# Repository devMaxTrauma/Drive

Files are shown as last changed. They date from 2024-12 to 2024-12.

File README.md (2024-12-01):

[//]: # (this description is temp for MDP announcement)

# **BL™ v1**

> **Blind Lumos**
>
> devMaxTrauma. Inc.™ presents **BL™ v1**

## 목차

> 1. [소개](#소개)
> 2. [대상 및 목적](#대상-및-목적)
> 3. [오픈소스](#오픈소스)
> 4. [기능](#기능)
> 5. [개발 과정](#개발-과정)
> 6. [알려진 문제](#알려진-문제)
> 7. [개발자들](#개발자들)

## 제품 소개

BL™ v1은 devMaxTrauma Inc.에서 개발한 혁신적인 시각 보조 기기로, 주로 시각장애인들을 위한 고급 기술을 탑재하고 있습니다. 이 제품은 OpenCV와 TensorFlow를 활용한 이미지 인식 기능과
FindMy 기능 등 다양한 편의 기능을 제공합니다.

BL™ v1의 소프트웨어는 오픈소스로 제공되며, 누구나 이를 참고하거나 수정할 수 있지만, 다음과 같은 조건이 적용됩니다:

> # BL™ v1 소프트웨어 사용 조건
>
> ---
>
> ## A. 출처 표기
> BL™ v1 소프트웨어를 사용할 때는 **반드시 devMaxTrauma Inc.와 BL™ v1의 출처를 명시**해야 합니다.  
> 출처가 명시되지 않을 경우, 해당 소프트웨어 사용 권한이 **즉시 상실**되며, 소프트웨어의 **소유권이나 지적 재산권을 주장할 수 없습니다**.
>
> ---
>
> ## B. 비상업적 및 윤리적 사용
> BL™ v1 소프트웨어는 **비상업적 목적**으로만 사용 가능하며, **비윤리적 사용**을 엄격히 금지합니다.  
> 상업적 목적으로 사용하려면 devMaxTrauma Inc.의 **사전 서면 승인**이 필요합니다.
>
> ---
>
> ## C. 수정 및 파생 소프트웨어
> BL™ v1 소프트웨어를 수정하거나 이를 기반으로 개발된 소프트웨어는 **본 라이선스 조건**을 그대로 따라야 하며,  
> devMaxTrauma Inc.는 해당 수정 소프트웨어에 대한 **소유권 및 라이선스 권한**을 보유합니다.
>
> ---
>
> ## D. 보증 및 책임
> BL™ v1 소프트웨어는 **"있는 그대로" 제공**되며, devMaxTrauma Inc.는 사용 중 발생하는 **어떠한 손해나 문제에 대해서도 책임을 지지 않습니다**.  
> 소프트웨어 사용으로 인해 발생하는 법적 분쟁, 손실, 또는 기타 불이익은 **사용자의 책임**입니다.
>
> ---
>
> ## E. 동의
> BL™ v1 소프트웨어를 다운로드, 설치 또는 사용할 경우, 위의 모든 조건에 **자동으로 동의**한 것으로 간주됩니다.
>
> ---

## 대상 및 목적

- 사람들은 보통 시각장애인이라 하면 전맹일 것이라 생각하지만, 실제로는 **전체 시각장애인 중 약 12%만이 전맹**이고, 나머지 88%는 색약이 있거나 시력이 떨어지는
  사람들입니다. [출처](http://www.kbufac.or.kr/Board/News/Detail?ContentSeq=2908&Page=19)
- **BL™은 전맹이 아닌 시각장애인들을 주 대상으로** 하며, 시각장애인의 불확실한 시각정보를 보완해주기 위해 제작한 작품입니다.
- 취약계층의 경제적 부담을 최대한 줄이며 보급률을 올리고자 제품 가격을 낮게 책정하여 설계했습니다. 대략 판매시 250,000 KRW 정도로 판매되길 희망합니다.

## 오픈소스

> ### EULA:
>
> BL™ v1을 개발하는 데 사용된 각종 소프트웨어 코드들은 모두 **오픈소스**로 제작되었습니다.  
> 이를 통해 누구나 이 프로젝트를 참고하거나 코드를 자유롭게 수정 및 재배포할 수 있습니다.  
> 다만, 이 프로젝트를 사용하는 모든 사용자는 다음 조건을 준수해야 합니다:
>
> ---
>
> 1. **출처 표기**
>> * 이 프로젝트를 참고하거나 수정된 코드를 배포할 때는 반드시 **devMaxTrauma Inc. 및 BL™ v1의 출처**를 명시해야 합니다.
>> * 출처를 명시하지 않을 경우, 귀하의 소프트웨어 사용 권한은 **즉시 상실**되며, devMaxTrauma Inc.가 귀하의 코드에 대한
>> * **소유권 및 라이선스 권한**을 행사할 수 있습니다.
>
> 2. **비도덕적 및 악용 금지**
>> * 이 프로젝트는 **비도덕적 목적**이나 **악의적인 의도**로 사용하는 것을 엄격히 금지합니다.
>> * 예를 들어, 불법적인 활동, 차별, 폭력 조장 등에 사용되는 경우 devMaxTrauma Inc.는 해당 사용자에 대해
>> * 법적 조치를 취할 권리를 보유합니다.
>
> 3. **수정 및 재배포**
>> * BL™ v1 기반으로 수정된 소프트웨어는 **동일한 라이선스 조건**을 따라야 합니다.
>> * 수정 및 재배포된 소프트웨어 또한 반드시 devMaxTrauma Inc.의 출처를 명시해야 하며,
>> * 이와 관련된 소유권은 devMaxTrauma Inc.에 귀속됩니다.
>
> ---
>
> ### 동의:
>
> 이 프로젝트를 다운로드, 수정, 재배포하거나 참여하는 행위만으로도 위의 모든 조건에 **자동으로 동의**한 것으로 간주됩니다.  
> devMaxTrauma Inc.는 본 프로젝트와 관련된 모든 지적 재산권과 법적 권리를 보유합니다.

### 작업결과들

- [S:IDE™](https://github.com/ellystargram/SIDE) - 자체개발 Code Editor, Kotlin 기반
- [rOS™](https://github.com/ellystargram/rOS) - Raspberry Pi 에서 돌아가는 텐서플로우 운영 체제
- [SLD™](https://github.com/devMaxTrauma/SLD) - FindMy기능을 활용할 수 있게 해주는 Android용 앱
- [devMaxTrauma. Inc.™](https://github.com/devMaxTrauma/Drive) - devMaxTrauma. Inc.의 모든 프로젝트 결과물

## 기능

> BL™ v1은 시각장애인의 시각정보를 보완해주는 제품입니다.

- BL™ v1은 라즈베리파이와 텐서플로우를 이용하여 사물을 인식하고, OpenCV를 이용하여 사물을 강조하여 표시합니다.
- SLD와 연동되어 안드로이드 기기에서 FindMy 기능을 사용할 수 있습니다.
- 탭틱엔진을 이용하여 햅틱 피드백을 얻을 수 있습니다.
- AR 기기답게 FPS 증진에 초점을 맞추어 최적화되었습니다. OpenCV Thread 와 Tensorflow Thread 를 병렬로 돌리며, 이를 통해 빠른 인식을 제공합니다.
- 물체와 사용자간의 거리를 측정하여 사용자에게 알려줍니다.

## 개발 과정

BL™ v1 (https://youtu.be/08gYM3Qs6oE)

### 설계 단계때 Inventor 상에 설계된 모델

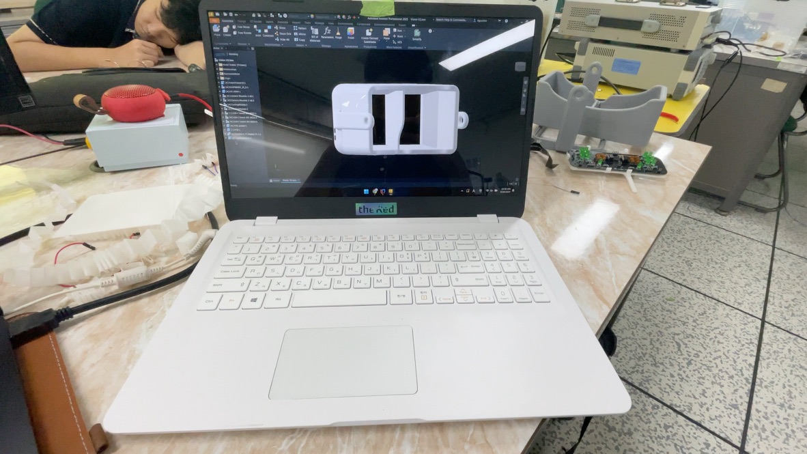
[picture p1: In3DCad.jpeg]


### 착용샷

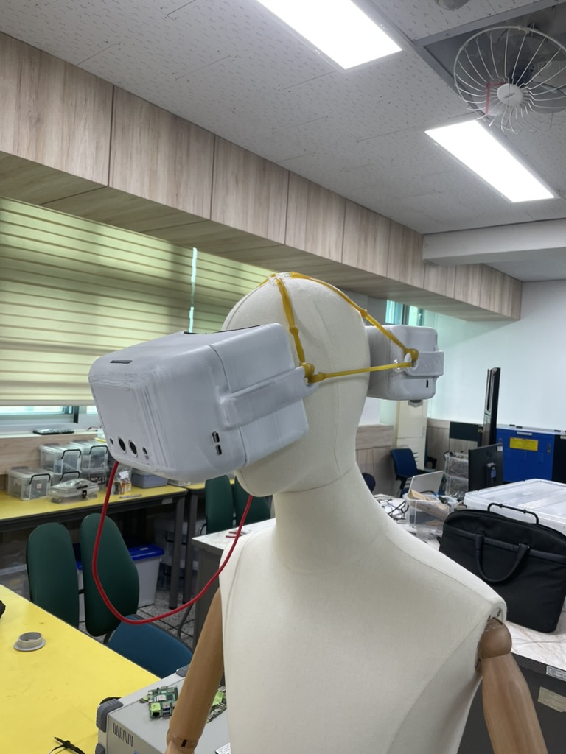
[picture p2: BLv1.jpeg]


### PCB

pcb picture

## 알려진 문제

- BL™ v1은 보기와 다르게 무거울 수 있습니다. 이는 MVP제품 특성상 발생하는 문제로, 이후 출시될 제품에서 개선될 예정입니다.
- BL™ v1은 시각장애인의 시각정보를 보완해주는 제품이지만, 시각장애인의 시각정보를 완벽하게 보완해주지는 못합니다. 이 점을 감안하여 사용해주시기 바랍니다.
- BL™ v1의 현재 디스플레이는 라즈베리파이 7인치 디스플레이로, 해상도가 낮고 명암비가 충분하지 않을 수 있습니다. 이는 다음 세대 제품에서 OLED 디스플레이를 탑제하면서 해결될 문제입니다.
- Light Seal™ 은 사람 체형에 맞춰서 커스텀으로 제작됩니다. 현제 착용하신 Light Seal 은 조원들중 한명의 얼굴을 본따 만들었기에 불편할 수 있습니다.
- Tensorflow Lite 모델이 부정확한 결과를 가져올 수 있습니다. 이는 AR 제품 특성상 FPS를 높이기 위해 모델을 최적화하다 보니 발생하는 문제입니다. 이는 다음 세대 제품에서 개선되길 희망합니다.

## 개발자들

### 최지오

> Role: Techno_King && Software Integrating Maestro

- <a href="https://discordapp.com/users/479559804021506049">
  Discord logo
  </a>
- <a href="https:/x.com/techno_sexking"> 
  X logo
  </a>
- <a href="https://github.com/ellystargram">
  Github logo
  </a>

### 송다연

> Role: Circuit Master

- <a href="https://instagram.com/day2onll"> 
    Instagram logo

</a>

### 최지훈

> Role: QC Master && Android Platform Sailor

- <a href="https://instagram.com/ji_h_6"> 
    Instagram logo

</a>

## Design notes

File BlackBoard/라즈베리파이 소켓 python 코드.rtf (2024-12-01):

import serial
import RPi.GPIO as GPIO
import socket
import threading

GPIO.setmode(GPIO.BCM)
GPIO.setup(17, GPIO.IN) # 입력 설정

HOST = "192.168.0.6"
PORT = 9021

# UART 포트 초기화

uart = serial.Serial("/dev/ttyS0", baudrate=115200, timeout=1)

# Socket 생성

s = socket.socket(socket.AF_INET, socket.SOCK_STREAM)
print('Socket created')
s.bind((HOST, PORT))
print('Socket bind complete')
s.listen(1)
print('Socket now listening')

u_data = ''
flag = 0

# 파이 컨트롤 함수

def do_some_stuffs_with_input(input_string):
if input_string == "send": # 휴대폰에서 send 라는 값이 올 경우 ...라는 값을 돌려준다.
input_string = "..."
else:
input_string = input_string + " 없는 명령어 입니다."
return input_string

# Socket 데이터 송수신을 위한 쓰레드

def socket_func(conn):
while True:
# 데이터 수신

data = conn.recv(1024)
data = data.decode("utf8").strip()
if not data:
break
print("Socket 수신된 데이터:", data)

u_data = data

# 수신한 데이터로 파이를 컨트롤

if data == 'close':
break
res = do_some_stuffs_with_input(data)

if data == "close":
flag = 1;

if GPIO.input(17) == 1: # 16번 GPIO에 입력값이 들어올 경우 ...이라는 값 대신에 push값전달
print("in")
command = "push"
conn.sendall(command.encode("utf-8"))
else: # 클라이언트에게 답을 보냄
conn.sendall(res.encode("utf-8"))

print(data)

# 데이터 송신

data_to_send = data
uart.write(data_to_send.encode()) # 문자열을 바이트로 변환하여 전송

conn.close()

try:

while True:
# 접속 승인

print("Waiting for connection...")
conn, addr = s.accept()
print("Connected by", addr)

# Socket 수신 쓰레드 시작

socket_thread = threading.Thread(target=socket_func, args=(conn,))
socket_thread.start()
print(u_data)

if flag == 1:
break

except KeyboardInterrupt:
pass

finally:
# Continuing the code

# Clean up resources

uart_thread.join()
s.close()
uart.close()

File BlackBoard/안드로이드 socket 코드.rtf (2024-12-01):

package com.example.socket5;

import androidx.appcompat.app.AppCompatActivity;

import android.os.Handler;
import android.os.Bundle;
import android.util.Log;
import android.view.View;
import android.widget.Button;
import android.widget.EditText;
import android.widget.TextView;
import android.widget.Toast;

import java.io.BufferedReader;
import java.io.BufferedWriter;
import java.io.IOException;
import java.io.InputStreamReader;
import java.io.OutputStreamWriter;
import java.io.PrintWriter;
import java.net.InetAddress;
import java.net.Socket;

public class MainActivity extends AppCompatActivity {
private Handler mHandler;
Socket socket;
String ip = "192.168.0.6"; // 서버의 IP 주소
int port = 9021; // PORT번호를 꼭 맞추어 주어야한다.
EditText et;
TextView msgTV;

@Override
protected void onCreate(Bundle savedInstanceState) {
super.onCreate(savedInstanceState);
setContentView(R.layout.activity_main);

mHandler = new Handler();


et = (EditText) findViewById(R.id.EditText01);
Button btn = (Button) findViewById(R.id.Button01);
msgTV = (TextView) findViewById(R.id.chatTV);

msgTV.setText("123");

btn.setOnClickListener(new View.OnClickListener() {
public void onClick(View v) {
if (et.getText().toString() != null || !et.getText().toString().equals("")) {
ConnectThread th = new ConnectThread();
Toast.makeText(MainActivity.this, "연결중", Toast.LENGTH_SHORT).show();
th.start();
}
}
});
}

@Override
protected void onStop() {
super.onStop();
try {
socket.close();//종료시 소켓도 닫아주어야한다.
} catch (IOException e) {
e.printStackTrace();
}
}

class ConnectThread extends Thread {//소켓통신을 위한 스레드

public void run() {
try {
// Toast.makeText(MainActivity.this, "linking", Toast.LENGTH_SHORT).show();
//소켓 생성
InetAddress serverAddr = InetAddress.getByName(ip);
socket = new Socket(serverAddr, port);
msgTV.setText("connected");
Toast.makeText(MainActivity.this, "linked", Toast.LENGTH_SHORT).show();
//입력 메시지
String sndMsg = et.getText().toString();
Log.d("=============", sndMsg);
//데이터 전송
PrintWriter out = new PrintWriter(new BufferedWriter(new OutputStreamWriter(socket.getOutputStream())), true);
out.println(sndMsg);
//데이터 수신
BufferedReader input = new BufferedReader(new InputStreamReader(socket.getInputStream()));
String read = input.readLine();
//화면 출력
mHandler.post(new msgUpdate(read));
Log.d("=============", read);
socket.close();//사용이 끝난뒤 꼭 닫아주어야한다.

if(et.getText().toString().equals("shut")) {
Toast.makeText(MainActivity.this, "closed", Toast.LENGTH_SHORT).show();
onStop();
}
} catch (Exception e) {
e.printStackTrace();
}
}


}

// 받은 메시지 출력
class msgUpdate implements Runnable {
private String msg;

public msgUpdate(String str) {
this.msg = str;
}

public void run() {
msgTV.setText(msgTV.getText().toString() + msg + "\n");
}
}
}

<?xml version="1.0" encoding="utf-8"?>
<LinearLayout xmlns:android="http://schemas.android.com/apk/res/android"
xmlns:app="http://schemas.android.com/apk/res-auto"
xmlns:tools="http://schemas.android.com/tools"
android:layout_width="match_parent"
android:layout_height="match_parent"
android:orientation="vertical"
tools:context=".MainActivity">

<LinearLayout
android:layout_width="match_parent"
android:layout_height="wrap_content"
android:layout_gravity="center"
android:orientation="horizontal"
android:weightSum="5">

<EditText
android:id="@+id/EditText01"
android:layout_width="0dp"
android:layout_height="match_parent"
android:layout_weight="4"
app:layout_constraintEnd_toEndOf="parent"
app:layout_constraintHorizontal_bias="0.874"
app:layout_constraintStart_toStartOf="@+id/Button01"
tools:layout_editor_absoluteY="608dp" />

<Button
android:id="@+id/Button01"
android:layout_width="0dp"
android:layout_height="match_parent"
android:layout_weight="1"
android:text="Send"
app:layout_constraintBottom_toBottomOf="parent"
tools:layout_editor_absoluteX="317dp" />

</LinearLayout>

<TextView
android:id="@+id/chatTV"
android:layout_width="match_parent"
android:layout_height="wrap_content"
app:layout_constraintBottom_toBottomOf="parent"
app:layout_constraintEnd_toEndOf="parent"
app:layout_constraintHorizontal_bias="0.0"
app:layout_constraintStart_toStartOf="parent" />

</LinearLayout>

<uses-permission android:name="android.permission.INTERNET" />

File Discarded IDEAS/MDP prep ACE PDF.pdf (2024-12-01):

## 작품 제안서

학과: 전자제어과 2학년 2반 12번 이름: 최지오

작품명 | ACE® (Autonomous Cooking Environment)
제안 이유 | 파스타를 만들다 보면 거의 레시피가 비슷한데, 손이 많이가는 경험을 할 수 있다. 또한 식당(* 돈까스 클럽, 홍익 돈까스 등)을 가보면 인건비로 인하여 파 스타 가격이 많이 비싸단것도 몸소 채감할 수 있다. 인건비를 해소하고 더 빠 르고 안전하게 파스타를 만들 수 있도록 이 장치를 개발시작하게 되었다.

블록 다이어그램

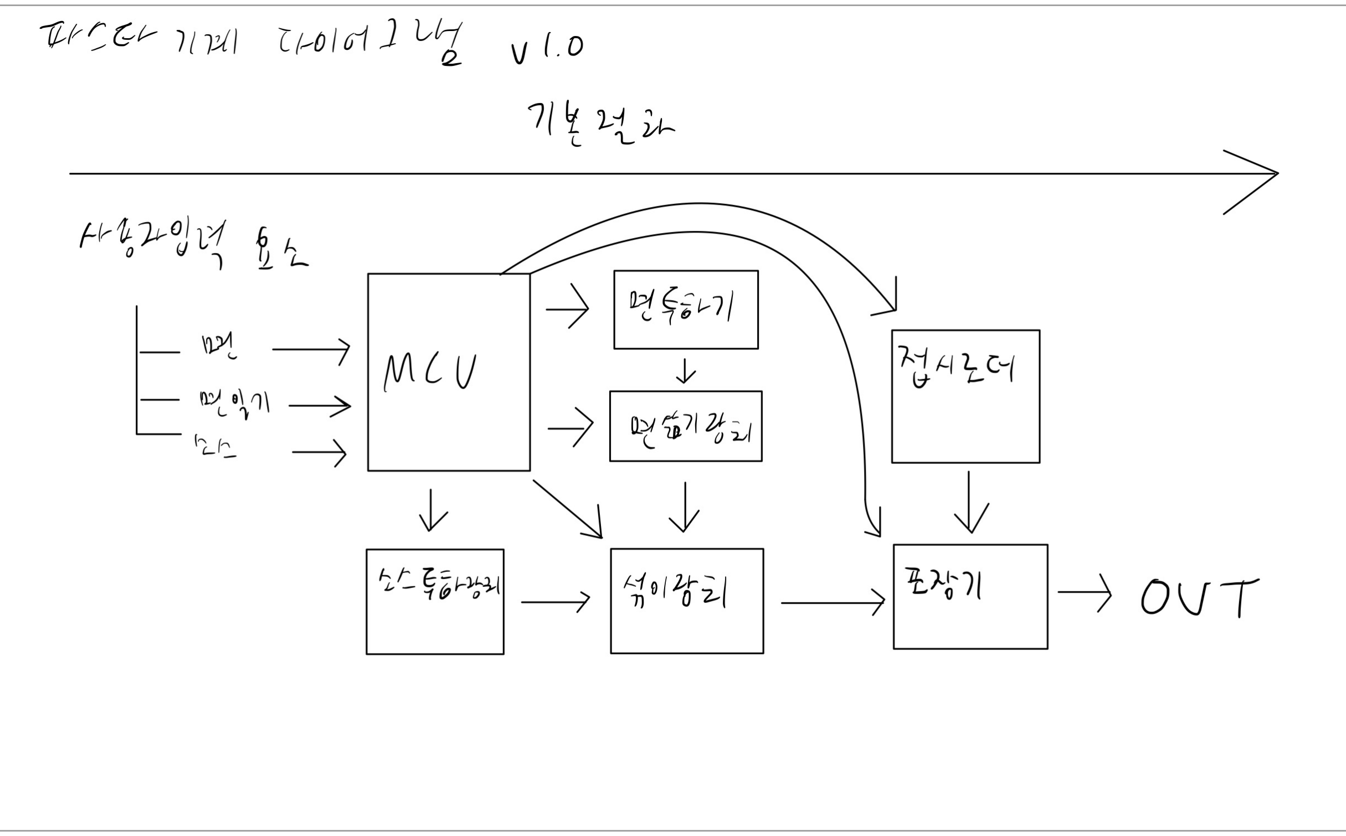
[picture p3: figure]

주요 구현 동작 | 1) 재료를 미리 다 넣어둔다. 2) 터치스크린을 통해 원하는 파스타면을 선택할 수 있다. 3) 터치스크린을 통해 원하는 소스를 선택할 수 있다. 4) 터치스크린을 통해 원하는 면 익힘 정도를 선택할 수 있다. 5) 선택된것(2,3,4)에 따라 조리를 한다음에 접시에 담아 제공한다.
필요 소모품 목록 | 입력부 | 터치스크린, 안전상의 이유로 존재하는 긴급 중지 버튼
| 제어부 | STM32(여러가지 모터 구동)
| 출력부 | 표시장치(진행상황 표시), 모터들, 발열체(가열), 펌프(급수)
참고자료 및 필요 배경 지식 | STM32 작동하기 c로 작동함 * c언어 배우기(Github, chatGPT, copilot) * c언어 분석(2학년때 만든 MDP 코드, sOS™ 분석) 여러가지 기계적 특성 및 설계 방법 * 유튜브에 Inventor 강의 많음 * 기계과 나온 우리형한테 자문 구함

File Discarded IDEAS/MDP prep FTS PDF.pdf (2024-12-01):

## 작품 제안서

학과: 전자제어과 2학년 2반 12번 이름: 최지오

작품명 | FTS (Fire Terminating System)
제안 이유 | 캠핑을 할때, 불타는 장작속으로 뛰어들어가는 나방을 본적이 있을것이다. 나 는 여기서 영감을 받아서 알아서 온도가 가장 높은곳(불 또는 발화원)으로 달 려가서 소화가스를 분사하는 시스템을 만들고 싶어졌다. 이는 화재 진압 과정 에서 인적 손실을 줄일 수 있고 배치 시간을 줄이는데 도움을 줄 수 있다.

블록 다이어그램

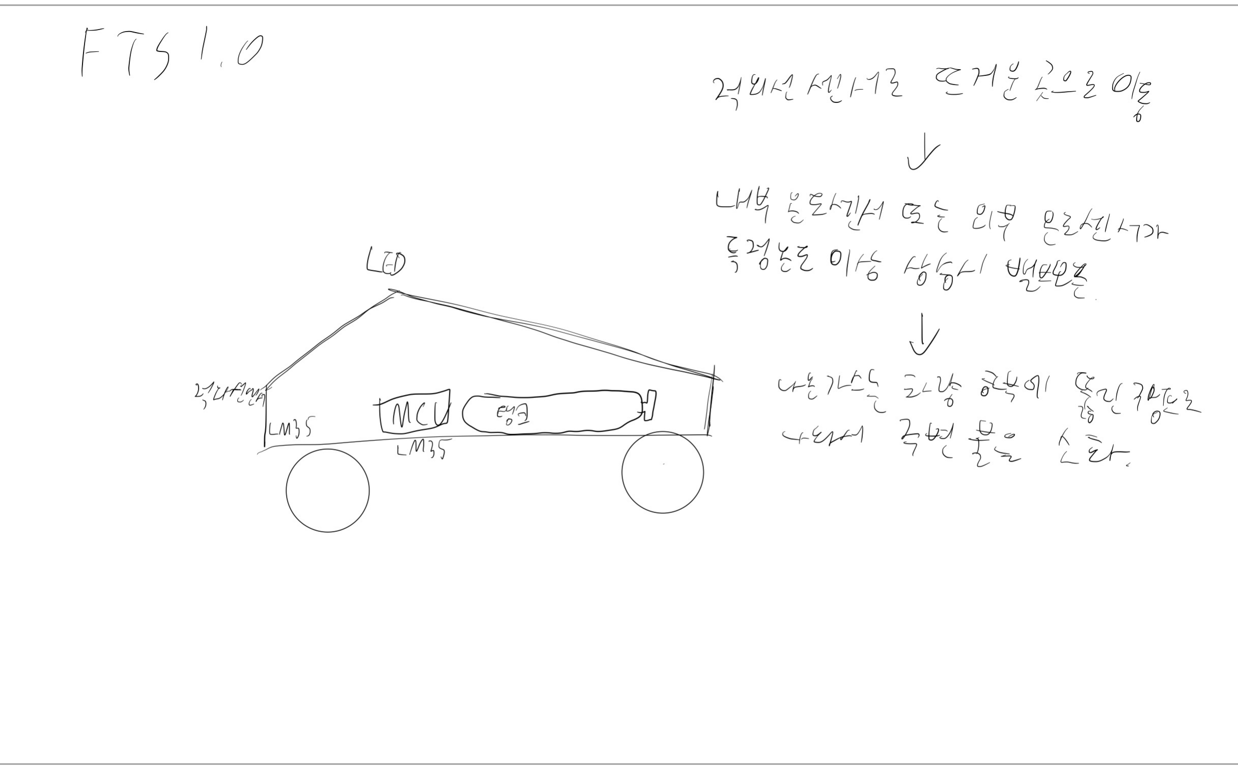
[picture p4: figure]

주요 구현 동작 | 1) 소화가스가 충전된 상태로 준비상태에 있다. 2) 출동 명령이 들어온다 3) 자체적으로 달려있는 적외선 감지기를 통해 가장 뜨거운 곳으로 주행을 시작한다 4) 주변 온도가 일정 온도 이상으로 올라가면(불난곳으로 들어가면) 소화가스방출을 시작한다.(이는 주변 소화 기능도 있지만, 소화가스방출중 발생하는 단열팽창을 통해 기계 자체를 냉각한다.) 5) 소화가스를 다 소모시 불 밖으로 도망나온다. 6) 소화가스를 다시 충전하면 다시 출동 준비가 완료된다.
필요 소모품 목록 | 입력부 | 적외선 센서, 주변온도 센서, 원격 제어를 위한 무선송수신부
| 제어부 | STM32(여러가지 모터 구동)
| 출력부 | 서보모터(소화가스 밸브작동), 모터(주행), 스피커(사이렌), LED, 가스탱크, 소화가스(CO2)
참고자료 및 필요 배경 지식 | STM32 작동하기 c로 작동함 * c언어 배우기(Github, chatGPT, copilot) * c언어 분석(2학년때 만든 MDP 코드, sOS™ 분석) 여러가지 기계적 특성 및 설계 방법 * 유튜브에 Inventor 강의 많음 * 기계과 나온 우리형한테 자문 구함 뜨거운 곳에서 작동해야 하기에 스테인리스 스틸로 외관을 제작해야함

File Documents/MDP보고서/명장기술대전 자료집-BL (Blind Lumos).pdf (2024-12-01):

# BL (Blind Lumos)

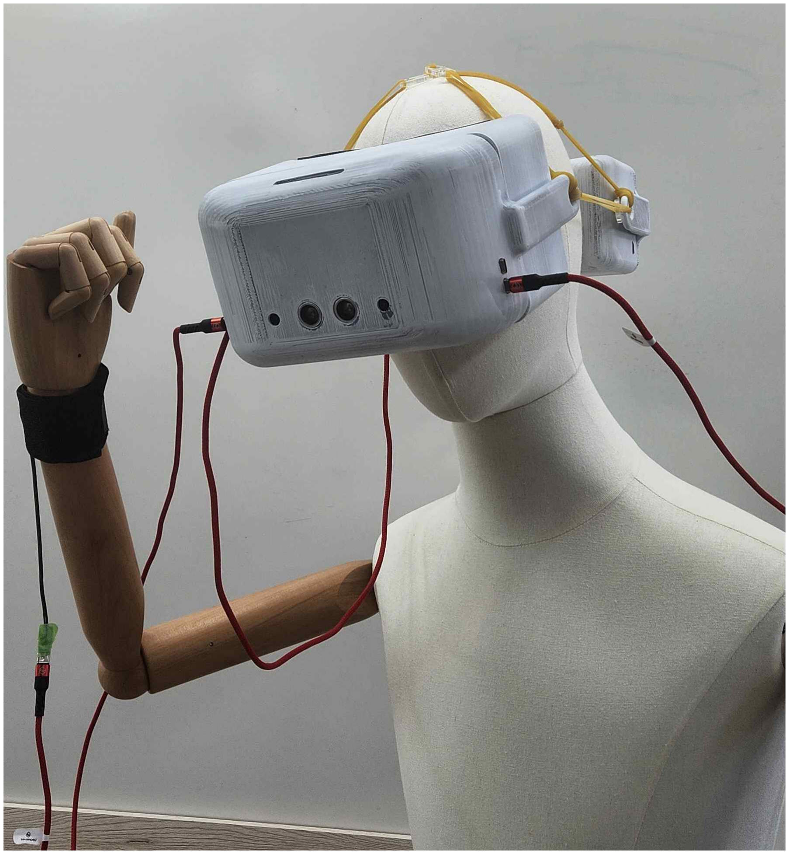
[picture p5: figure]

# 인천전자마이스터고등학교

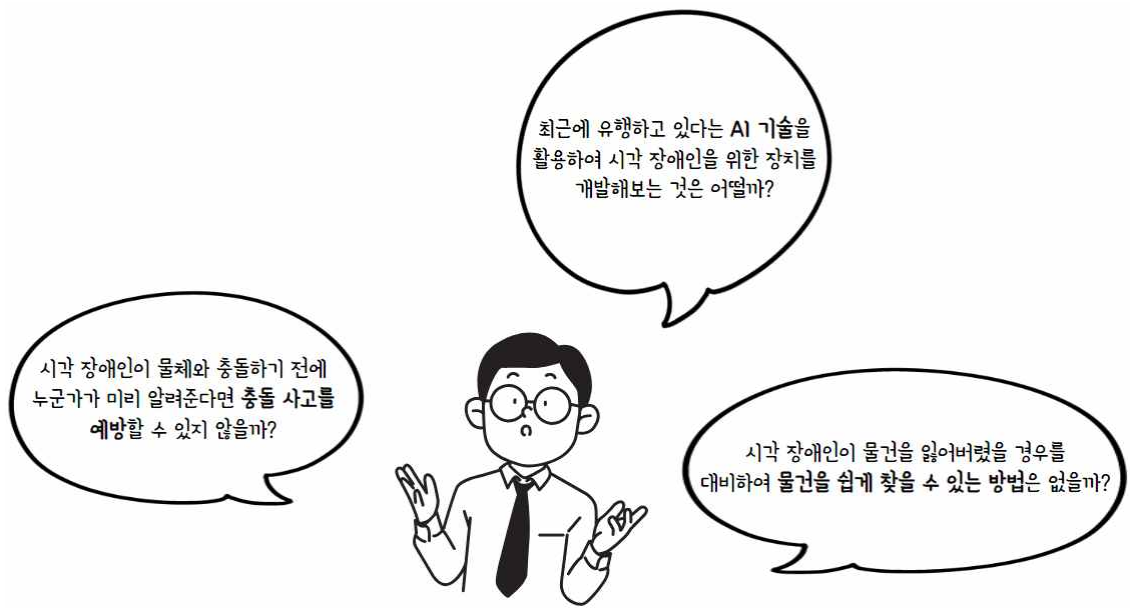
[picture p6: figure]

2 | 인천전자마이스터고등학교 IM 명장기술대전

사람들은 대부분 시각 장애라 하면, 빛을 완전히 인지하지 못하는 전맹을 생각하곤 한다. 하 지만 실제로는 저시력이나 단안 실명, 시야각 결손도 시각 장애에 포함이 된다. 따라서, 시각 장애인의 대부분은 전맹이 아니라 빛을 인지하고, 사물의 윤곽은 알아볼 수 있는 시각 장애인 의 비중이 훨씬 높다. 하지만 이들은 정확하지 않은 시각 정보에 크게 의존하는 경우가 많기 때문에 오히려 전맹을 가진 시각 장애인보다 더욱 위험한 상황에 처할 수 있다. 우리들은 이러 한 문제점을 파악한 후, 시각 장애인들의 안전을 위한 장치(BL)를 고안해보게 되었다. 장치의 기본적인 기능으로는 내부의 각종 모듈을 통해 디스플레이로 사물의 정보를 송출할 수 있도록 하는 것이다. 그리고 사물을 사람의 눈에 잘 띄는 색상(예: 고대비)을 가진 네모 영역으로 이미 지를 대체하여 사용자가 세상과 안전하게 상호작용 할 수 있도록 도움을 주게 한다. 또한, 정 면에 존재하는 사물이 사용자와 얼마나 가까이 있는지를 알리기 위해 손목 밴드의 진동 모듈 을 통하여 사용자에게 직접적으로 거리에 대한 정보를 제공한다. 만약, 사용자가 장치를 잃어 버렸을 경우에 대비하여 전용 APP(SLD)과 장치를 블루투스를 통해 서로 연동함으로써 사용자 가 장치와 멀리 떨어져 있어도 쉽게 장치를 찾을 수 있도록 하는 기능이 존재한다.

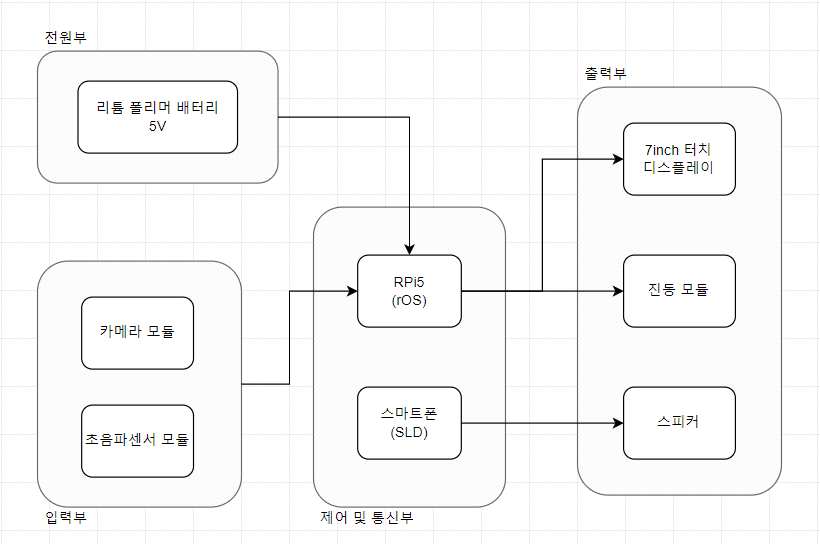
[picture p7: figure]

전자제어과 | 3

### 1. 동작 설명

가. 전원이 공급되고 있는 장치를 착용하여 장치의 동작을 확인한다.
나. 사용자의 주위에 위험한 사물이 있거나, 사물이 가까이 있는지 살펴본다.
다. 사용자의 주위에 위험한 사물이 있을 경우, 빨간색으로 강조된 네모 영역 이미지가 사물을 표시하여 보여준다.
라. 사용자의 주위에 사물이 가까이 있을 경우, 손목 밴드에 탑재되어 있는 진동 모듈이 거리에 따라 진동의 세기가 다르게 동작하여 사용자에게 위험 수준을 알린다. 2. 부가 요소

가. 장치 내부의 디스플레이를 통해 사물의 네모 영역 이미지를 보고 세상과 상호작용 할 수 있다,
나. 위험한 상황에 노출되지 않도록 정면에 있는 사물이 사용자와 얼마나 가까이 있는지를 진동 모듈을 통해 알 수 있다.
다. 장치의 디스플레이에 블루라이트 차단 필터 효과를 적용할 수 있다.
라. 전용 App과 장치를 연동할 경우에 장치가 사용자와 떨어져 있어도 어디에 있는지 전용 App을 통해 알 수 있다.
마. 전용 App의 화면을 슬라이딩하여 손쉽게 장치의 색약 보정을 할 수 있다.

4 | 인천전자마이스터고등학교 IM 명장기술대전

### 3. 전원부

가. 리튬 폴리머 배터리 5V
: 장치 내부의 Raspberry pi 5에 5V의 전원을 공급한다. 4. 프로세서 제어부

가. Raspberry pi 5 (8GB)
: 안드로이드 앱과 블루투스 통신을 하고, Raspberry pi 5와 연결된 카메라 모듈 및 초음파센서로부터 받아온 정보를 7inch 다스플레이에 실시간 송출한다. 또한, 사물을 인식하여 그에 맞는 네모 영역 이미지를 생성해 보여준다.
나. Android 및 iOS 어플리케이션 (SLD)
: 어플리케이션의 화면 속 버튼을 눌렀을 때, Raspberry pi 5와 연결된 스피커를 통해서 소리를 출력한다. 5. 입력부

가. 카메라 모듈
: Raspberry pi 5와 연결하여 사용자가 바라보는 시야 정보를 카메라 센서를 통해 디지털신호로 반환한다.
나. 초음파센서
: Raspberry pi 5와 연결하여 정면에 존재하는 사물과의 거리를 측정한다. 6. 출력부

가. 7inch 터치 디스플레이
: Raspberry pi 5와 연결된 카메라가 받아온 디지털신호와 사물의 네모 영역 이미지를 출력하여 보여준다.
나. 진동 모듈 (Taptic Engine)
: Raspberry pi 5와 연결된 초음파센서에서 받아온 데이터 값이 일정한 수치에 가까워지게 되면 진동 모듈에서 진동이 시작된다, 사물과의 거리가 가까울수록 진동 모듈이 크게 진동하고, 사물과의 거리가 멀수록 진동 모듈이 작게 진동한다. 다. 스피커
: Android 및 iOS 어플리케이션(SLD)을 통해 신호를 받으면 스피커에 소리를 재생시킨다.

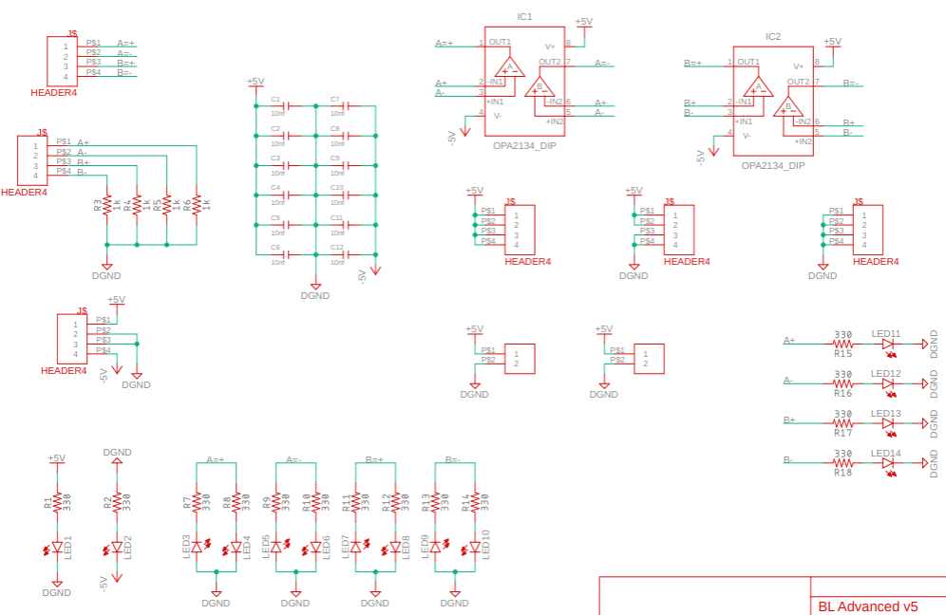
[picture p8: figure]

전자제어과 | 5

리튬 폴리머 배터리 5V로부터 전원을 공급받는 전원부이다. 이를 통해 각종 프로세서에 필요한 전원을 공급하여 프로세서를 동작시킬 수 있다.

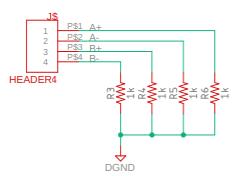
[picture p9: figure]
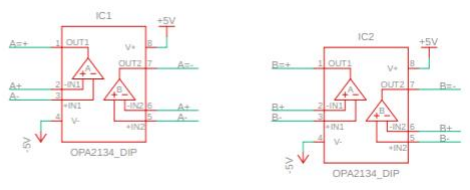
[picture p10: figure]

6 | 인천전자마이스터고등학교 IM 명장기술대전

입력을 받는 입력부이다. 진동 모듈이 동작하기 위해 Raspberry pi 5의 PWM 값을 입력받아 OP-Amp로 양과 음의 파형을 동작시키기 위한 회로이다.

출력이 되는 출력부이다. OP-Amp로 Raspberry pi 5의 PWM 파형이 입력되면 듀티비에 따라 진동 모듈의 진동 모터 속도가 변화하여 진동의 세기를 조절한다.

Raspberry pi 5로부터 입력을 받아 진동 모듈의 출력을 제어하는 OP-Amp 회로이다.

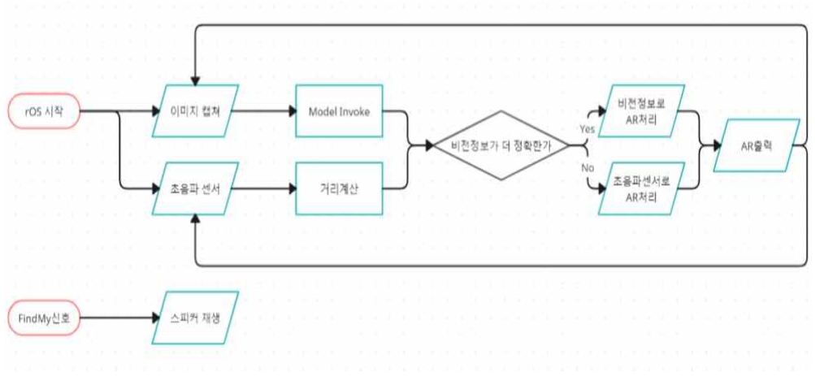
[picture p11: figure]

전자제어과 | 7

장치에는 Raspberry pi 5가 내장되어 있으며, 카메라 모듈과 초음파센서로부터 데이터를 받 아 프로그램의 동작을 수행한다. 또한, 받아온 데이터를 바탕으로 진동 모듈의 동작을 수행한 다. Raspberry pi 5로 실행되는 프로그램은 카메라 모듈로 입력받은 데이터를 통해 사물과 사 용자 간의 거리를 디스플레이에 표시하고, AI를 이용해 사물을 인식하여 네모 영역의 이미지를 디스플레이에 표시한다. 스마트폰의 장치 전용 App에서는 Raspberry pi 5와 블루투스 연동이 되어있을 때, 화면의 버튼을 누르면 장치 내부의 스피커에서 소리가 재생된다.

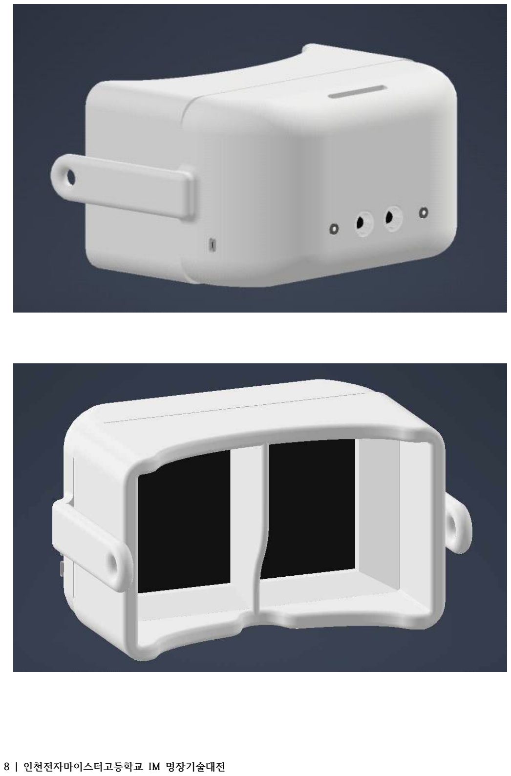
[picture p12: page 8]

8 | 인천전자마이스터고등학교 IM 명장기술대전

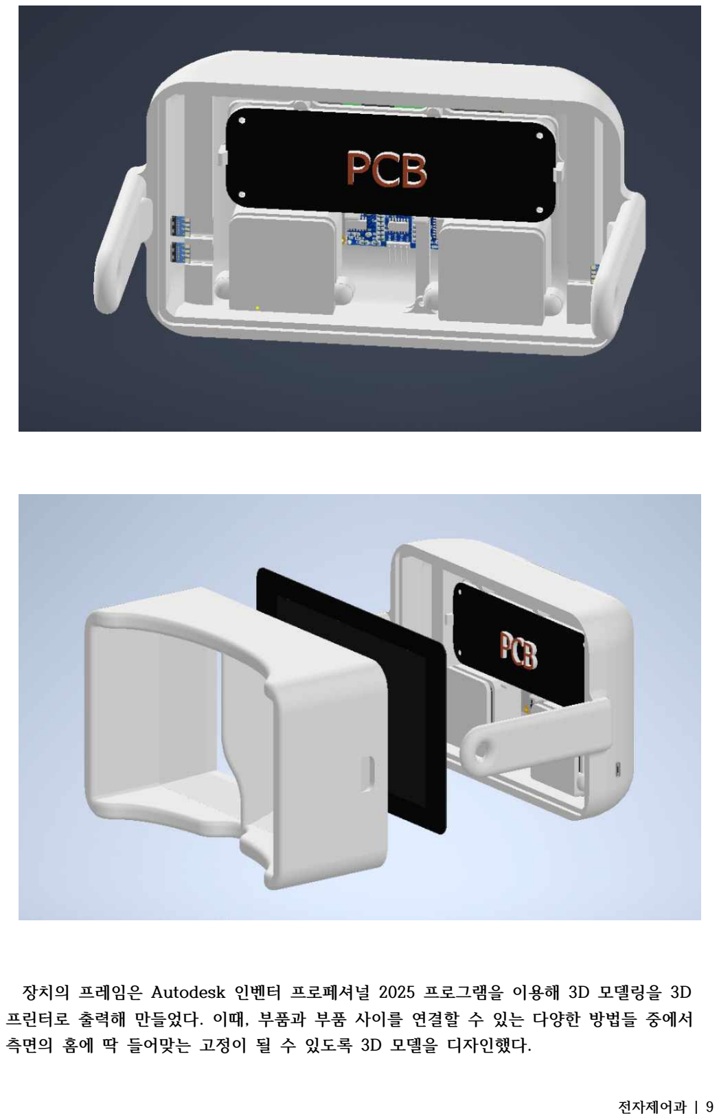
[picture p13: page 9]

전자제어과 | 9

장치의 프레임은 Autodesk 인벤터 프로페셔널 2025 프로그램을 이용해 3D 모델링을 3D 프린터로 출력해 만들었다. 이때, 부품과 부품 사이를 연결할 수 있는 다양한 방법들 중에서 측면의 홈에 딱 들어맞는 고정이 될 수 있도록 3D 모델을 디자인했다.

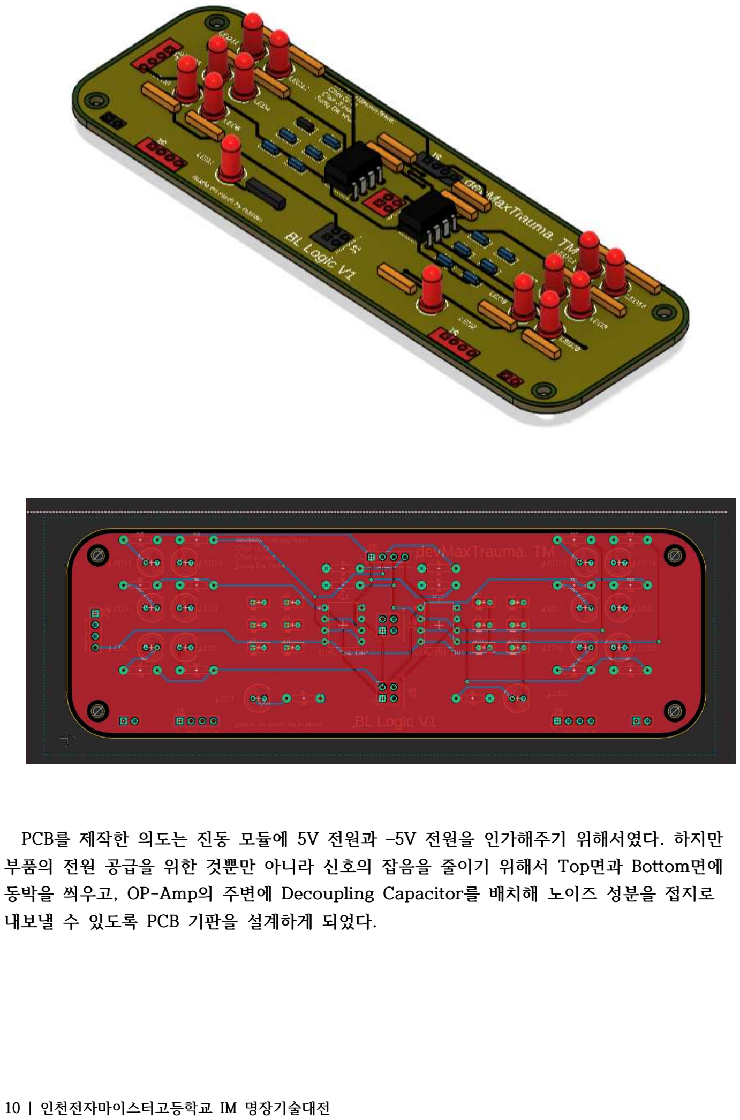
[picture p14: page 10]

10 | 인천전자마이스터고등학교 IM 명장기술대전

PCB를 제작한 의도는 진동 모듈에 5V 전원과 –5V 전원을 인가해주기 위해서였다. 하지만 부품의 전원 공급을 위한 것뿐만 아니라 신호의 잡음을 줄이기 위해서 Top면과 Bottom면에 동박을 씌우고, OP-Amp의 주변에 Decoupling Capacitor를 배치해 노이즈 성분을 접지로 내보낼 수 있도록 PCB 기판을 설계하게 되었다.

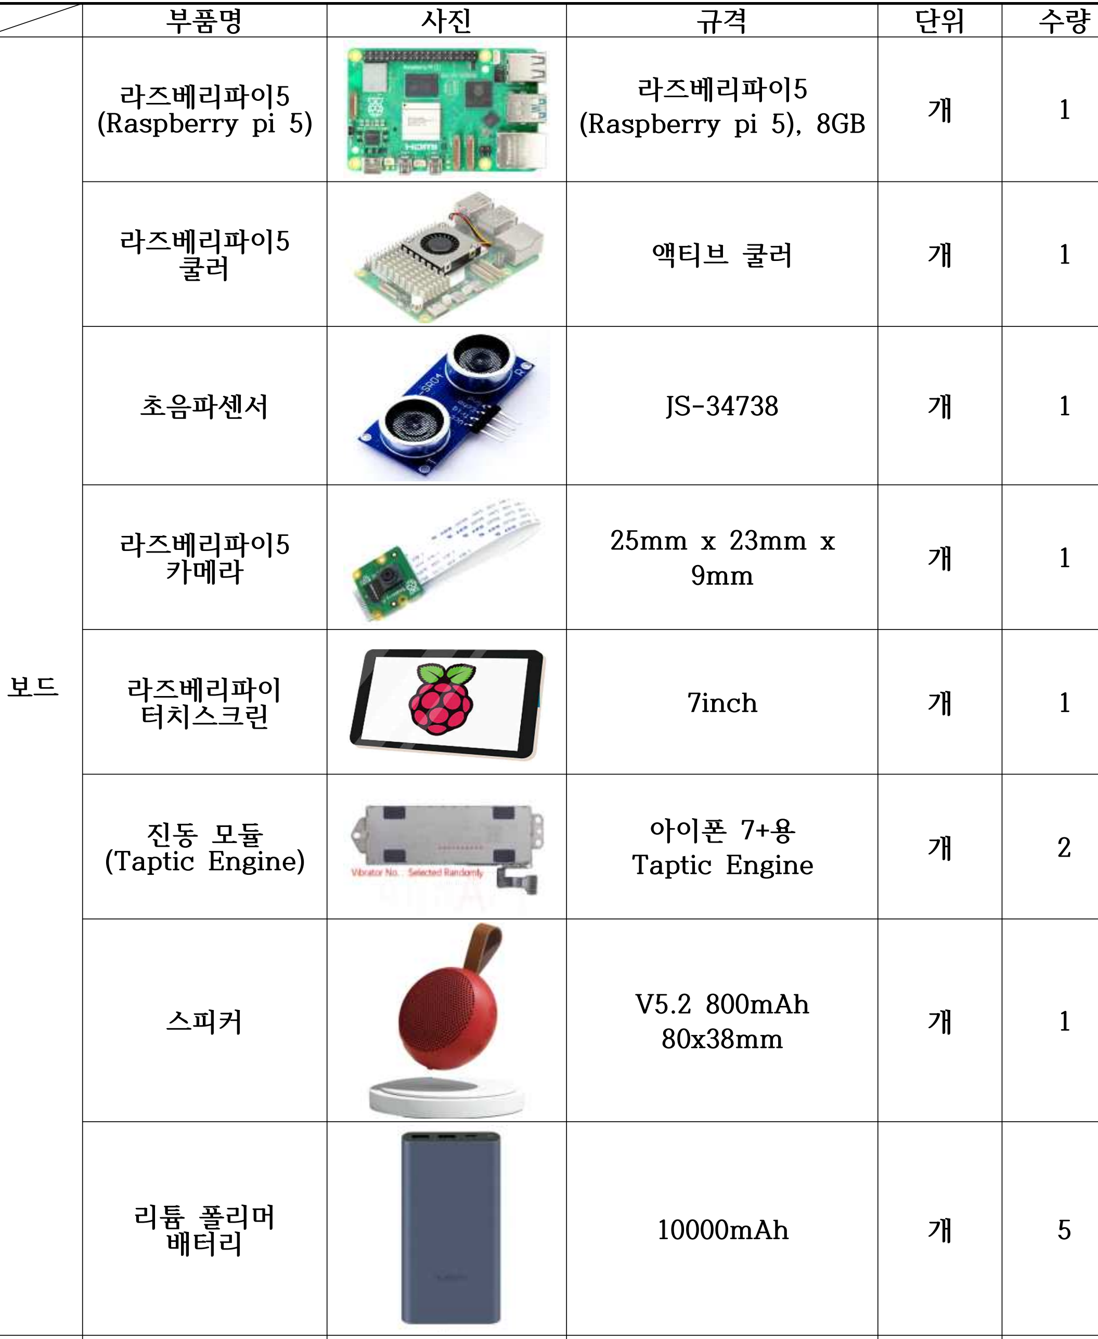
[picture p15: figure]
부품명; 라즈베리파이5 (Raspberry pi 5); 라즈베리파이5 (Raspberry pi 5), 8GB; 라즈베리파이5 쿨러; 액티브 쿨러; 초음파센서; 라즈베리파이5 카메라; 라즈베리파이 터치스크린; 7inch; 진동 모듈 (Taptic Engine); 아이폰 7+용 Taptic Engine; 스피커; V5.2 800mAh 80x38mm; 리튬 폴리머 배터리; 10000mAh

전자제어과 | 11
기구물 | 장치 프레임 | | 필라멘트, 16.3cm x 23.5cm x 11.9cm | 개 | 1

12 | 인천전자마이스터고등학교 IM 명장기술대전

이 작품은 우리가 처음 계획했었던 사물 인식 기능과 사용자와 사물간의 거리 측정 기능, 그 리고 사용자에게 위험도를 알리는 기능을 모두 수행하는 만족스러운 결과를 만들어 냈다. 하지만, 우리는 추가적으로 개발하려고 했었던 가속도센서를 이용한 추락 인지 기능을 구현

하지 못했다. 또한, 해당 작품이 우리가 예상했었던 무게를 초과하였기 때문에 착용하는 사람 에 따라 장치가 무겁다고 느낄 수 있을 것 같다. 앞으로 우리는 지금까지 개발된 기능들을 조금 더 체계적으로 정리한 다음, 구현해내지 못했

던 추락 인지 기능을 개발하여 장치에 추가할 예정이다. 그리고 기능이 추가된 만큼 늘어난 장 치의 무게를 줄이기 위한 방법을 찾기 위해 꾸준히 장치를 시험해볼 예정이다. 우리들은 이 장치를 통해서 세상에 존재하는 많은 시각 장애인들이 안전하게 세상과 상호작

용 할 수 있었으면 한다. 참고문헌

[1] https://www.apple.com/kr/newsroom/2023/06/introducing-apple-vision-pro/
[2] https://www.meta.com/kr/quest/quest-3/
[3] http://www.kbufac.or.kr/Board/News/Detail?ContentSeq=2908&Page=19

전자제어과 | 13

### 1. 프로젝트 수업 계획서

월 | 주 | 일 | 단 원 | 주요업무 | 비 고
(작성되어야 할 내용, 제출평가) | 확인 (지도교사)
3 | 2 | 3/4 ~ 3/8 | 프로젝트 구성안 | 제품명/디자인 및 동작 계획
| 3 | 3/11 ~ 3/15 | 프로젝트 구성안 | 기능 구상 및 역할 분담
| 4 | 3/18 ~ 3/22 | 부품 발주 | 프로젝트 필요 부품 구상 및 발주 신청
| 5 | 3/25 ~ 3/29 | 소프트웨어 | 플로우차트 작성
4 | 1 | 4/1 ~ 4/5 | 소프트웨어 | 기본 소프트웨어 구현
| 2 | 4/8 ~ 4/12 | 관련 학습 | 앱 기능 구현 방법 학습
| 3 | 4/15 ~ 4/19 | 부품 발주 | 필요 부품 발주 추가 신청
| 4 | 4/22 ~ 4/26 | 소프트웨어 | 기본 소프트웨어 구현
| 5 | 4/29 ~ 4/30 | 하드웨어 | 하드웨어 3D 모델링 제작
5 | 1 | 5/1 ~ 5/3 | 소프트웨어 | 기본 소프트웨어 구현
| 2 | 5/7 ~ 5/10 | 소프트웨어 | 심화 소프트웨어 구현
| 3 | 5/13 ~ 5/17 | 소프트웨어 | 심화 소프트웨어 구현
| 4 | 5/20 ~ 5/24 | 소프트웨어 | 앱 기능 구현
| 5 | 5/27 ~ 5/31 | 소프트웨어 | 앱 기능 구현
6 | 2 | 6/3 ~ 6/7 | 부품 발주 | 필요 부품 발주 신청
| 3 | 6/10 ~ 6/14 | 하드웨어 | 하드웨어 블록도 작성
| 4 | 6/17 ~ 6/21 | 소프트웨어 | 심화 소프트웨어 구현
| 5 | 6/24 ~ 6/28 | 하드웨어 | 기본 하드웨어 구성

14 | 인천전자마이스터고등학교 IM 명장기술대전
월 | 주 | 일 | 단 원 | 주요업무 | 비 고
(작성되어야 할 내용, 제출평가) | 확인 (지도교사)
7 | 1 | 7/1 ~ 7/2 | 하드웨어 | 기본 하드웨어 구성
| 2 | 7/8 ~ 7/12 | 하드웨어 | 심화 하드웨어 구성
| 3 | 7/15 ~ 7/19 | 소프트웨어 | 심화 소프트웨어 구현
| 4 | 7/22 ~ 7/26 | 소프트웨어 | 심화 소프트웨어 구현
| 5 | 7/29 ~ 7/31 | 소프트웨어 | 심화 소프트웨어 구현
8 | 1 | 8/1 ~ 8/2 | 하드웨어 | 심화 하드웨어 구성
| 2 | 8/5 ~ 8/9 | 하드웨어 | 심화 하드웨어 구성
| 3 | 8/12 ~ 8/16 | 소프트웨어 | 소프트웨어 구동 확인 및 수정
| 4 | 8/19 ~ 8/23 | 하드웨어 | 기구물과 하드웨어 결합
| 5 | 8/26 ~ 8/30 | 하드웨어 | 하드웨어 테스트 및 수정
9 | 1 | 9/2 ~ 9/6 | 성능 구현 | 소프트웨어 시연 및 수정
| 2 | 9/9 ~ 9/13 | 성능 구현 | 소프트웨어 시연 및 수정
| 3 | 9/16 ~ 9/20 | 성능 구현 | 소프트웨어 시연 및 수정
| 4 | 9/23 ~ 9/27 | 성능 구현 | 소프트웨어 시연 및 수정

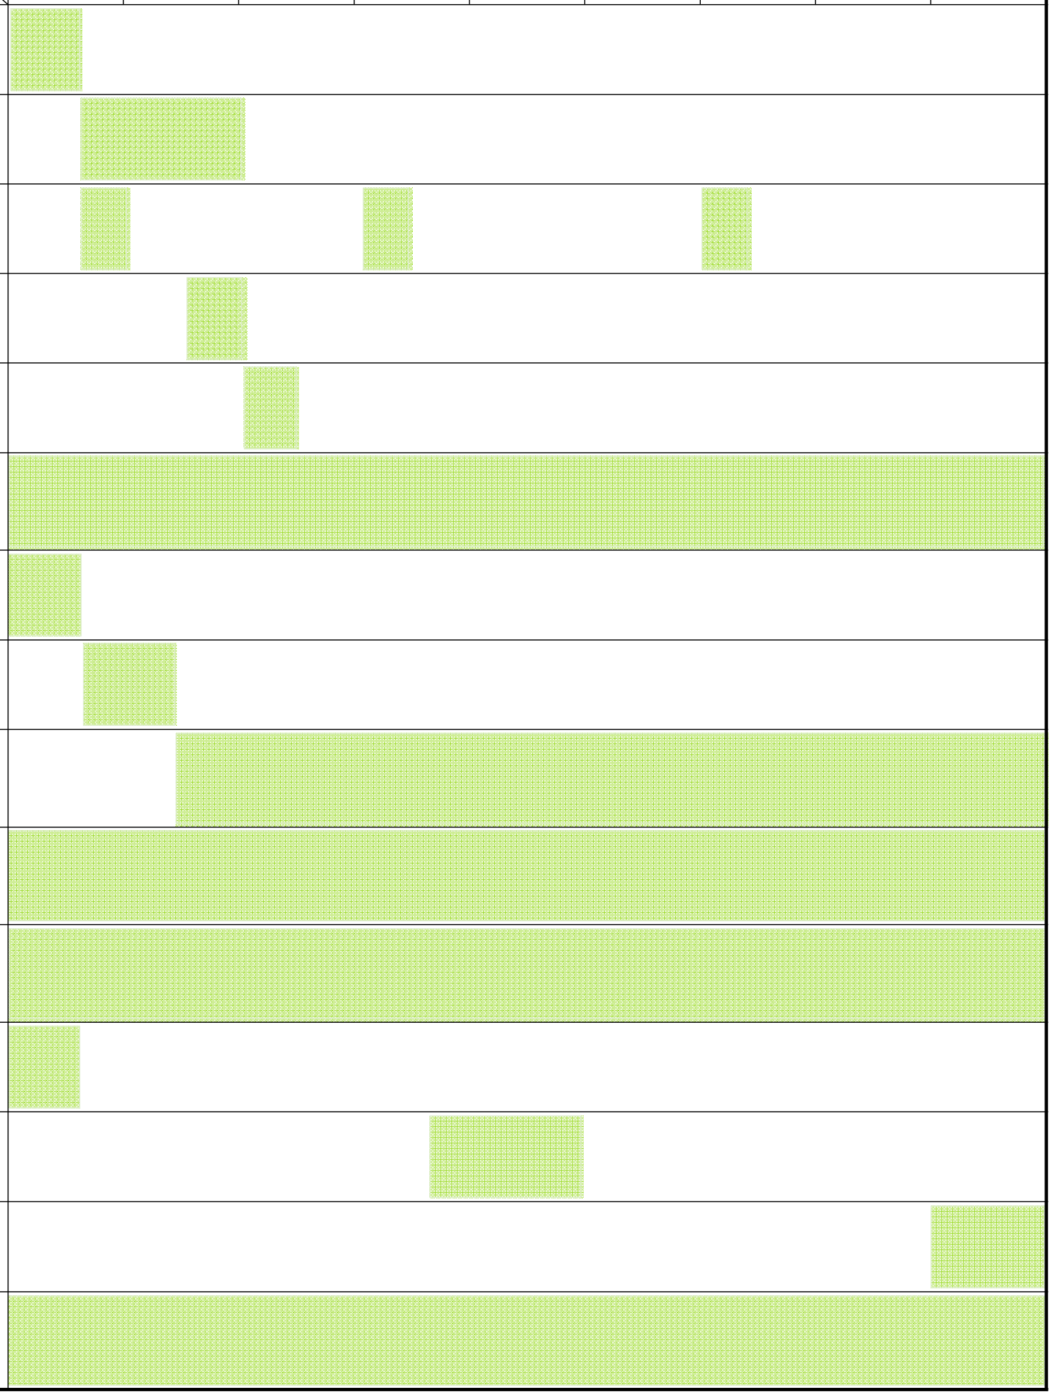
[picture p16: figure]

전자제어과 | 15

### 2. 과제 수행 진도표

일정 내용 | 3월 1~3주 | 3월 4~5주 | 4월 1~2주 | 4월 3~5주 | 5월 1~2주 | 5월 3~5주 | 6월 1~2주 | 6월 3~4주 | 7월 1~2주
하 드 웨 어 | 초안 작성
| 회로 설계
| 부품 발주
| 블럭도
| 테스트보드
| 보고서
소 프 트 웨 어 | 초안 작성
| 플로우차트
| 소프트웨어 구현
| 학습
| 보고서
시 스 템 | 초안 작성
| 기구물 디자인
| 조립 및 시현
| 보고서

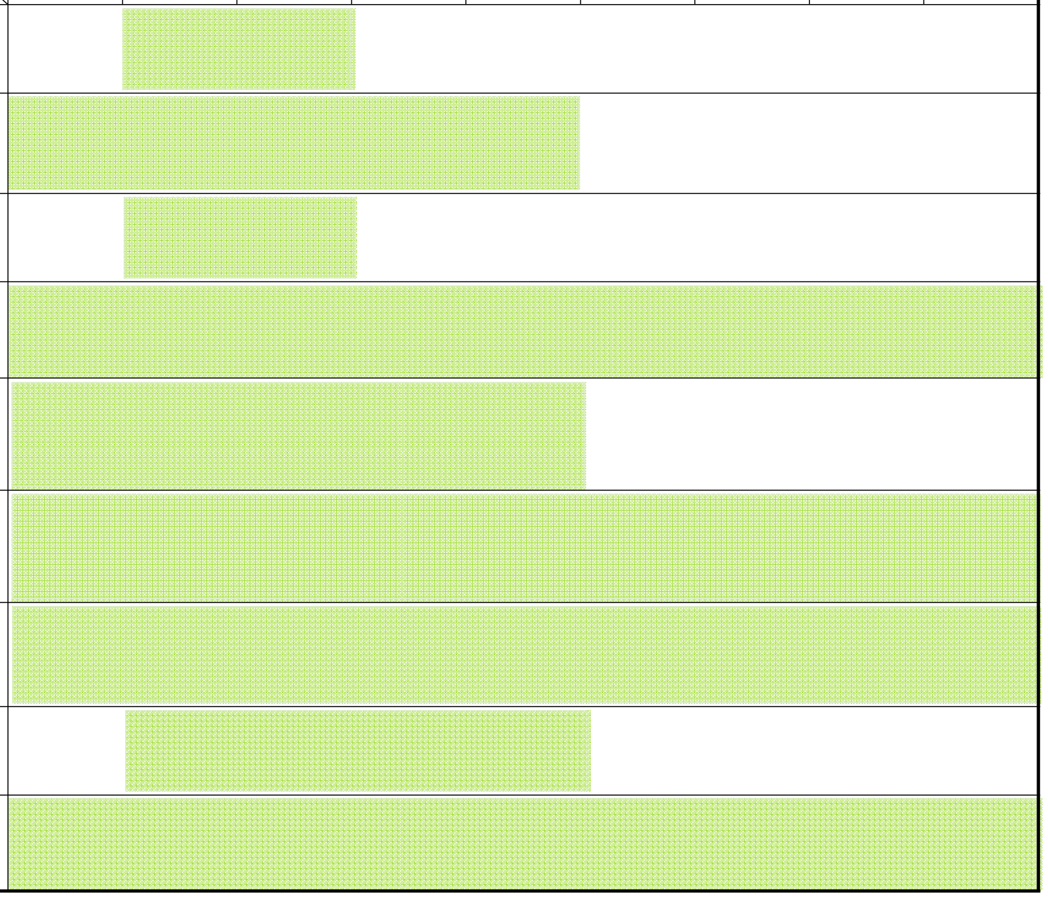
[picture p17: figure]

16 | 인천전자마이스터고등학교 IM 명장기술대전
일정 내용 | 7월 3~5주 | 8월 1~3주 | 8월 4~5주 | 9월 1~2주 | 9월 3~5주 | 10월 1~2주 | 10월 3~5주 | 11월 1~2주 | 11월 3~5주
하드 웨어 | 회로설계
| 시뮬레이션
| 구조물제작
| 보고서
소프 트웨 어 | 소프트웨어 구현
| 학습
| 보고서
시스 템 | 조립 및 시현
| 보고서

전자제어과 | 17

가. 라즈베리파이5 (Raspberry pi 5)

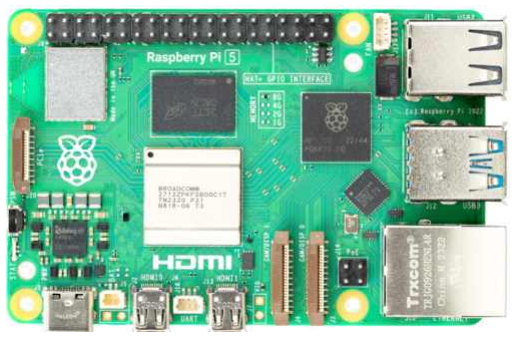
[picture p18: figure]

라즈베리 파이는 영국 잉글랜드의 라즈베리 파이 재단이 학교와 개발도상국에서 기초 컴퓨터 과학의 교육을 증진시키기 위해 개발한 신용카드 크기의 싱글 보드 컴퓨터이다. 초기의 라즈베 리 파이는 엘레멘트14/프리미어 파넬, RS 콤포넌트와의 허가된 제조 협정을 통해 제작되었다. Raspberry pi 5는 이전 세대에 비해 브로드컴 BCM2712 쿼드코어 Arm Cortex-A76 프로

세서를 탑재하여 2-3배 이상 빨라지고 가능한 최고의 성능을 위해 라즈베리파이 재단에서 자 체적으로 설계된 반도체가 포함된 패키지인 RP1 I/O 컨트롤러를 내장하여 지금까지의 라즈베 리파이와는 차원이 다른 경험을 제공한다. USB 3는 더 빠른 전송 속도를 위해 더 많은 총 대 역폭을 제공하고, 카메라와 DSI 디스플레이 커넥터는 서로 바꿔 사용하거나 각각 하나씩 사용 하는 등 두 개를 동일하게 사용할 수 있다. 우리가 사용한 Raspberry pi 5의 규격은 2.4GHz ARM 프로세서, 8GB의 RAM이다. 작품에서는 AR 플랫폼을 제공하고 전용 APP과 소켓 통신 을 하여 각종 부품들을 제어한다. 나. 진동 모듈 (Taptic Engine)

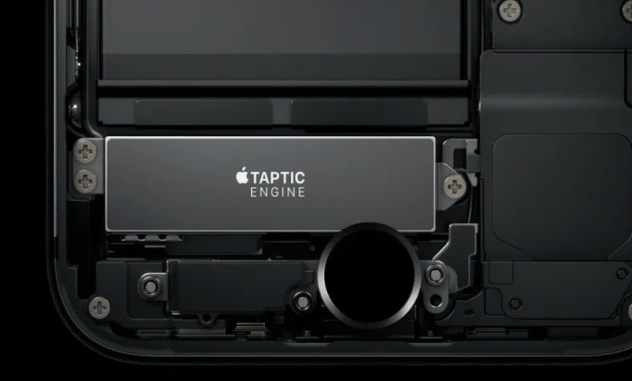
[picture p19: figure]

18 | 인천전자마이스터고등학교 IM 명장기술대전

Apple에서 개발한 진동 모터를 이용한 엔진이다. 일반적인 진동 부품보다 내구도가 강하며, 더 섬세하게 작동한다고 Apple은 소개하고 있다. 기존 진동 모터와 같은 느낌을 내는 것도 당

연히 가능하며, 일반적인 진동 모터와는 다르게 버튼을 누르는 듯한 매우 짧고 경쾌한 진동을 울리게 하는 것도 가능하다는 특징이 있다. Apple은 Taptic Engine을 이용하여 3D Touch 피드백이나 Apple Watch의 모든 진동 피드백을 구현했다. 이는 구조상 Taptic Engine에는 최대 크기의 진동까지 도달하는데 거의 딜레이가 존재하지 않기 때문에 가능한 것이지만, Tap tic Engine은 단방향으로만 직선운동을 하는 리니어 모터란 특성 때문에 바닥에 두었을 때에 는 진동이 울리는 것을 알아채기 힘들다는 것이 단점으로 꼽힌다. 작품에서는 초음파센서가 받 아온 값에 따라 사람에게 위험도를 알리는 용도로 사용된다. 다. 카메라 모듈

카메라모듈은 렌즈를 통해 들어온 이미지를 센서를 통해 디지털신호로 변환시키는 부품이다. 카메라 모듈은 크게 이미지 센서와 렌즈 모듈, IR-Filter, Package 등으로 구성된다. 이미지

센서는 CCD(Charge Coupled Device)센서와 CMOS(Complementary Metal Oxide Semi-co nductor)로 분류 된다. CCD센서는 일반적으로 CMOS보다 질 좋은 화질을 구현할 수 있다는 장점이 있으며, 단점은 가격이 비싸고 전력의 소모량이 크다는 것이 있다. CMOS는 양산성이 우수해서 가격이 저렴하지만, 단점으로는 상대적으로 화질이 떨어지고 노이즈가 발생하며 사이 즈가 크다는 것이 있다. 렌즈 모듈(Lens Module)은 구면은 유리로 만들고, 비 구면은 플라스 틱 사출로 만든다. 작품에서 카메라 모듈은 사용자가 바라보는 시각 정보를 받아오기 때문에 다른 부품들 보다도 매우 중요한 역할을 한다.

전자제어과 | 19

[ Android App(SLD) 코드 ]

// 메인코드 //
package com.example.mdp_project;

import static android.speech.tts.TextToSpeech.ERROR; import android.Manifest;
import android.annotation.SuppressLint;
import android.bluetooth.BluetoothAdapter;
import android.bluetooth.BluetoothDevice; import android.bluetooth.BluetoothSocket; import android.content.Context;
import android.content.pm.PackageManager; import android.os.Bundle;
import android.os.Vibrator;
import android.speech.tts.TextToSpeech;
import android.util.Log;
import androidx.appcompat.app.AppCompatActivity; import androidx.core.app.ActivityCompat;
import androidx.fragment.app.Fragment;
import androidx.viewpager2.widget.ViewPager2;
import com.tbuonomo.viewpagerdotsindicator.DotsIndicator; import java.io.IOException;
import java.io.OutputStream;
import java.lang.reflect.Method;
import java.util.ArrayList;
import java.util.Locale;
import java.util.UUID;

public class MainActivity extends AppCompatActivity { private static final int SPEECH_REQUEST_CODE = 0; PageAdapter pageAdapter;
ViewPager2 viewPager2;
ArrayList<Fragment> fragList = new ArrayList<Fragment>(); private TextToSpeech tts;

private static final String DEVICE_ADDRESS = "2C:CF:67:28:A6:D6";
// 라즈베리 파이 블루투스 주소
private static final UUID MY_UUID = UUID.fromString("00001101-0000-1000-8000-00805F9B 34FB");

private static BluetoothAdapter bluetoothAdapter;
private static BluetoothSocket bluetoothSocket;
private static OutputStream outputStream; @Override
protected void onCreate(Bundle savedInstanceState) { super.onCreate(savedInstanceState);
setContentView(R.layout.activity_main);
bluetoothAdapter = BluetoothAdapter.getDefaultAdapter();
BluetoothDevice device = bluetoothAdapter.getRemoteDevice(DEVICE_ADDRESS); tts = new TextToSpeech(this, new TextToSpeech.OnInitListener() {
@Override
public void onInit(int status) {
if (status != ERROR) {
// 언어를 선택한다.
tts.setLanguage(Locale.KOREAN);

20 | 인천전자마이스터고등학교 IM 명장기술대전
tts.setPitch(1.0f); | // 음성 톤은 기본 설정
tts.setSpeechRate(2.0f); | //음성 속도 기본 설정
tts.speak("기본 화면 입니다.", TextToSpeech.QUEUE_ADD, null); }
}
});
new Thread(new Runnable() { public void run() {
try {
bluetoothSocket = createBluetoothSocket(device);
if (ActivityCompat.checkSelfPermission(MainActivity.this, Manifest.permission. BLUETOOTH_CONNECT) != PackageManager.PERMISSION_GRANTED) { String[] permissions = new String[]{Manifest.permission.BLUETOOTH_CONNECT};

// TODO: Consider calling
// ActivityCompat#requestPermissions
// here to request the missing permissions, and then overriding
// public void onRequestPermissionsResult(int requestCode, String[] permissions,
// | int[] grantResults)
// to handle the case where the user grants the permission. See the documentation
// for ActivityCompat#requestPermissions for more details. ActivityCompat.requestPermissions(MainActivity.this, permissions, 01);
}
bluetoothSocket.connect();
tts.speak("연결되었습니다", TextToSpeech.QUEUE_ADD, null); outputStream = bluetoothSocket.getOutputStream(); Log.d("MainActivity", "Bluetooth connected");
} catch (IOException e) {
Log.e("MainActivity", "Error connecting to Bluetooth", e); }
}
}).start(); ~ 중략 ~

@SuppressLint("MissingPermission")
public | static | BluetoothSocket | createBluetoothSocket(BluetoothDevice | device) | throws
IOException {
try {
final | Method | m | = | device.getClass().getMethod("createRfcommSocket", | new
Class[]{int.class});
return (BluetoothSocket) m.invoke(device, 1);
} catch (Exception e) {
Log.e("MainActivity", "Could not create Insecure RFComm Connection", e); }
return device.createRfcommSocketToServiceRecord(MY_UUID);
}

public static void sendSignal(String signal) {
try {
outputStream.write(signal.getBytes()); Log.d("MainActivity", "Signal sent: " + signal); } catch (IOException e) {
Log.e("MainActivity", "Error sending signal", e); }
}
}~ 이하 생략 ~

전자제어과 | 21

[ Rapsberry pi 5(rOS) 코드 ]

// 메인코드 //
import numpy as np
import RKernel

rk = RKernel.RKernel()
fps_history = []

# resize window 360 360

rk.cv.namedWindow("ROS", rk.cv.WINDOW_NORMAL)
if rk.key_engine.get_key("ROSARDisplayEnabled").get("value"): ar_width = rk.key_engine.get_key("ARDisplayWidth").get("value") ar_height = rk.key_engine.get_key("ARDisplayHeight").get("value") rk.cv.resizeWindow("ROS", ar_width, ar_height)
else:
rk.cv.resizeWindow("ROS", 320, 320)

boot_start_time = rk.time.time()
while rk.time.time() - boot_start_time < 5:
if rk.key_engine.get_key("ROSARDisplayEnabled").get("value"): rk.cv.imshow("ROS", rk.make_ar_frame(rk.splash_screen)) else:
rk.cv.imshow("ROS", rk.splash_screen)
rk.cv.waitKey(1)

if rk.key_engine.get_key("CameraDevice").get("value") == "macbook pro": camera = rk.cv.VideoCapture(0)
elif rk.key_engine.get_key("CameraDevice").get("value") == "iphone": camera = rk.cv.VideoCapture(1)
elif rk.key_engine.get_key("CameraDevice").get("value") == "raspberry pi":
camera = rk.picamera2.Picamera2() camera.configure(camera.create_preview_configuration(main={"size": (320, 320)})) camera.start()

else:
print("warning! Invalid camera device. Using default device.") camera = rk.cv.VideoCapture(0)

if camera is None:
print("camera open failed") rk.shutdown()

last_update_time = rk.time.time()
while True:
if rk.key_engine.get_key("CameraDevice").get("value") == "raspberry pi":

22 | 인천전자마이스터고등학교 IM 명장기술대전 frame = camera.capture_array()
frame = rk.cv.cvtColor(frame, rk.cv.COLOR_BGR2RGB) if frame is None:
print("raspberry pi camera read failed")
break
else:
capture_success, frame = camera.read() if not capture_success:
print("camera read failed")
break

if frame.shape[0] != 320 or frame.shape[1] != 320: # make new_frame but don't flect it target_width = 320
target_height = 320
aspect_ratio = float(target_height) / frame.shape[0] dsize = (int(frame.shape[1] * aspect_ratio), target_height) new_frame = rk.cv.resize(frame, dsize)

# cut the new_frame width to 320 center

new_frame = new_frame[:,
new_frame.shape[1] // 2 - target_width // 2: new_frame.shape[1] // 2 + target_width // 2]
else:
new_frame = frame

if rk.key_engine.get_key("ROSModelActive").get("value"): rk.process_frame(new_frame)

boxes_idx, classes_idx, scores_idx = 0, 1, 2
boxes = rk.model.get_tensor(rk.model_output_details[boxes_idx]['index'])[0] classes = rk.model.get_tensor(rk.model_output_details[classes_idx]['index'])[0] scores = rk.model.get_tensor(rk.model_output_details[scores_idx]['index'])[0]

for i in range(len(scores)):
class_name = rk.label_engine.get_label(int(classes[i] + 1)).get("value") class_color = rk.color_engine.get_color(class_name)
if scores[i] > 0.5:
box = boxes[i] * [320, 320, 320, 320]
text_x, text_y = 0, 0 # for text position
if rk.key_engine.get_key("ROSMindDisplayWay").get("value") == "filled box": inverted_color = (255 - class_color[0], 255 - class_color[1], 255 - class_color[2])

# outer line

rk.cv.rectangle(new_frame, (int(box[1]), int(box[0]), int(box[3]), int(box[2])), inverted_color, 2)

전자제어과 | 23

# inner box

rk.cv.rectangle(new_frame, (int(box[1]), int(box[0])), (int(box[3]), int(box[2])), class_color, -1)
# put text center of the box

text_size = rk.cv.getTextSize(class_name, rk.cv.FONT_HERSHEY_SIMPLEX, 0.5, 2)[0]
text_x = int((box[1] + box[3]) / 2 - text_size[0] / 2)
text_y = int((box[0] + box[2]) / 2 + text_size[1] / 2)
rk.cv.putText(new_frame, | class_name, | | (text_x, | | text_y),
rk.cv.FONT_HERSHEY_SIMPLEX, 0.5, inverted_color, 2)

elif rk.key_engine.get_key("ROSMindDisplayWay").get("value") == "outlined box": rk.cv.rectangle(new_frame, (int(box[1]), int(box[0])), (int(box[3]), int(box[2])), class_color, 2)
text_x = int(box[1])
text_y = int(box[0])
rk.cv.putText(new_frame, | class_name, | | (text_x, | | text_y),
rk.cv.FONT_HERSHEY_SIMPLEX, 0.5, class_color, 2)

if rk.key_engine.get_key("DistanceDisplayEnabled").get("value"):
object_average_width | = | rk.label_engine.get_label(int(classes[i] | +
1)).get("average_width")
box_width_pixel = box[3] - box[1]
distance = rk.calculate_distance(object_average_width, box_width_pixel)
if | rk.key_engine.get_key("DistanceDisplayWay").get("value") | == "invertedColorInBox":

inverted_color = (255 - class_color[0], 255 - class_color[1], 255 - class_color[2])

# draw text in center of the box

rk.cv.putText(new_frame, | distance, | (text_x, | text_y | + | 20),
rk.cv.FONT_HERSHEY_SIMPLEX, 0.5,
inverted_color, 2)

if rk.key_engine.get_key("ROSDisplayFPSEnable").get("value"): update_time = rk.time.time()
fps = 1 / (update_time - last_update_time) fps_history.append(fps)
if len(fps_history) > 10:
fps_history.pop(0)
last_update_time = update_time
avg_fps = np.mean(fps_history)
rk.cv.putText(new_frame, f"FPS: {avg_fps:.2f}", (10, 20), rk.cv.FONT_HERSHEY_SIMPLEX, 0.5, (0, 255, 0), 2)

24 | 인천전자마이스터고등학교 IM 명장기술대전 if rk.key_engine.get_key("ROSARDisplayEnabled").get("value"):
new_frame = rk.make_ar_frame(new_frame)

rk.cv.imshow("ROS", new_frame)

if rk.cv.waitKey(1) & 0xFF == 27: break

rk.shutdown()

// RKernel 코드 //

from boot.RTensor import model

print("RKernel is booting up...")

print("defining pre def methods...")

def make_error(error_code: str, error_message: str): pass
print("E" + error_code + ": " + error_message) exit(error_code)

print("methods pre def defined.")

print("Loading Third Party imports...") try:
pass
import cv2 as cv
except ImportError:
pass
make_error("1001", "cv2 not found.") except Exception as e:
pass
make_error("1001-1", str(e))
try:
pass
import time
except ImportError:
pass
make_error("1002", "time not found.") except Exception as e:
pass
make_error("1002-1", str(e))

전자제어과 | 25

try:
pass
import picamera2
except ImportError:
pass
print("Picamera2 not found.") except Exception as e:
pass
make_error("1003", str(e)) try:
pass
import threading
except ImportError:
pass
make_error("1005", "threading not found.") except Exception as e:
pass
make_error("1005-1", str(e))
try:
pass
import numpy as np
except ImportError:
pass
make_error("1006", "numpy not found.") except Exception as e:
pass
make_error("1006-1", str(e))
try:
pass
import sys
except ImportError:
pass
make_error("1007", "sys not found.") except Exception as e:
pass
make_error("1007-1", str(e))
try:
pass
import os
except ImportError:
pass
make_error("1008", "os not found.") except Exception as e:
pass
make_error("1008-1", str(e)) print("Third Party Imports loaded.")

26 | 인천전자마이스터고등학교 IM 명장기술대전 print("Loading RKernel imports...")
try:
pass
import boot.RKey as key_engine except ImportError:
pass
make_error("1101", "RKey not found.") except Exception as e:
pass
make_error("1101-1", str(e))
try:
pass
import boot.RSound as sound_engine except ImportError:
pass
make_error("1102", "RSound not found.") except Exception as e:
pass
make_error("1102-1", str(e))
try:
pass
import boot.RFPS as fps_engine except ImportError:
pass
make_error("1103", "RFPS not found.") except Exception as e:
pass
make_error("1103-1", str(e))
try:
pass
import boot.RTensor as tensor_engine except ImportError:
pass
make_error("1104", "RTensor not found.") except Exception as e:
pass
make_error("1104-1", str(e))
try:
pass
import boot.RLabel as label_engine except ImportError:
pass
make_error("1105", "RLabel not found.") except Exception as e:
pass

전자제어과 | 27

make_error("1105-1", str(e))
try:
pass
import boot.RColor as color_engine except ImportError:
pass
make_error("1106", "RColor not found.") except Exception as e:
pass
make_error("1106-1", str(e))
try:
pass
import boot.RBluetooth as bluetooth_engine except ImportError as e:
pass
print("RBluetooth not found.")
except Exception as e:
pass
make_error("1107", str(e))
try:
pass
import boot.RNotification as notification_engine except ImportError:
pass
make_error("1108", "RNotification not found.") except Exception as e:
pass
make_error("1108-1", str(e))
try:
pass
import boot.RTTS as tts_engine except ImportError:
pass
make_error("1109", "RTTS not found.") except Exception as e:
pass
make_error("1109-1", str(e))
# try:

# import boot.RGPIO as gpio_engine # except ImportError:

# print("RGPIO not found.")

# try:

# if "boot.RGPIO" in sys.modules: import boot.RUSS as ultrasonic_engine # except ImportError:

# make_error("1111", "RUSS not found.")

# try:

28 | 인천전자마이스터고등학교 IM 명장기술대전

# if "boot.RGPIO" in sys.modules: import boot.RTaptic as taptic_engine # except ImportError:

# make_error("1112", "RTaptic not found.") ~ 중략 ~ # set_tensor_input()

if key_engine.get_key("ROSBootChimeEnabled").get("value"): pass
sound_engine.play("boot/res/StartUp.mp3")

started_time = time.time()
splash_display_time = key_engine.get_key("ROSSplashScreenTime").get("value") while time.time() - started_time < splash_display_time:
pass
boot_logo(time.time() - started_time, splash_display_time)
tick_screen()
# debug

# if hard_warning_icon is None:

# kernel_panicked = True

kernel_panicked = kernel_panic_check()
if cv.waitKey(1) & 0xFF == key_engine.get_key("ROSOffKey").get("value"):
| pass
| shutdown()

tts_engine.sound_engine = sound_engine
notification_engine.sound_engine = sound_engine ~ 이하 생략 ~ 보다 더 자세한 코드 내용은 https://github.com/devMaxTrauma을 통해 확인해주시길 바랍니다.

전자제어과 | 29

<최지오>
이번 프로젝트를 통해 다양한 기술을 실제로 적용해보면서 많은 것을 배울 수 있었습니다. 이번 프로젝트에서도 Inventor를 활용해 3D 모델링을 진행했습니다. 이전에도 3D 모델링을

해본 경험이 있었지만, 이번에는 더 복잡하고 정교한 모델을 설계하면서 기술적인 깊이를 더할 수 있었습니다. 모델링 과정에서의 디테일한 수정과 최적화를 통해 설계의 완성도를 높이는 법 을 익혔습니다. Eagle을 사용해서는 PCB 설계를 했는데, 실제 회로를 설계하고 시뮬레이션해 볼 수 있어 전자공학의 기본 원리를 더 깊이 이해할 수 있었습니다. 설계한 회로가 실제로 작 동하는 것을 보며 설계의 중요성을 다시 한번 실감하게 되었어요. Python과 OpenCV를 활용 해 이미지 처리와 컴퓨터 비전을 구현했습니다. 이미지를 분석하고 처리하는 과정에서 OpenCV의 다양한 기능을 활용할 수 있었고, 특히 실시간 데이터 처리의 가능성을 엿볼 수 있 었던 부분이 인상적이었습니다. 또한, TensorFlow Lite를 사용해 모델을 경량화하고 모바일 환경에서도 딥러닝 모델을 구현하는 작업도 진행했어요. 모델 최적화 과정에서 성능과 정확도 사이의 균형을 맞추는 것이 쉽지 않았지만, 이를 통해 모바일 환경에서도 AI를 적용할 수 있는 가능성을 확인할 수 있었습니다. 이번 프로젝트는 다양한 기술을 실무에 적용해보는 좋은 기회 였으며, 특히 각 기술의 강점을 이해하고 어떻게 활용할지에 대한 감각을 기를 수 있었습니다. 도전과 성장이 공존했던 프로젝트였고, 이러한 경험들이 앞으로의 학습과 실무에 큰 도움이 될

것이라 믿습니다. <송다연>

MDP 발표회를 준비하던 중간에 취업교육을 듣게 되면서 한동안 학교를 나오지 못했던 적이 있었습니다. 하지만 취업교육이 끝나 다시 학교로 돌아왔을 때, 저희 팀원들이 자신들이 맡았 던 소프트웨어 개발의 많은 부분을 완성해주어서 저 또한 의욕을 잃지 않고 MDP에 열심히 참 여할 수 있었던 것 같습니다. 이 과정에서 팀에 생긴 저의 빈 자리를 메꾸기 위해 저는 팀원들 과 종종 소통을 하고, 팀원들이 저의 도움을 필요로 하면 내키지 않고 바로 도움을 주었던 기 억이 있습니다. 이 덕분에 저희 팀원들 또한 팀원의 공백이 있었음에도 불구하고 끝까지 맡은 바를 완벽히 해내어준 것 같습니다. 그리고 팀원들과 큰 마찰없이 기분 좋게 MDP 발표회를 마무리할 수 있게 되어 굉장히 기분이 좋습니다. 다음에도 공동 프로젝트에 참여할 기회가 생 긴다면 소통을 최우선으로 팀원들과 함께 즐거운 마음으로 프로젝트에 참여할 것 같습니다. 감 사합니다. <최지훈>

MDP 발표회에서 앱 개발을 담당하면서 많은 것을 배웠습니다. 처음부터 끝까지 앱 개발의 과정을 직접 경험하면서 기술적인 성장뿐만 아니라 팀과의 소통의 중요성을 다시금 느낄 수 있었습니다. 전기전자 전공의 특성상 다양한 하드웨어와 소프트웨어가 결합된 프로젝트였는데, 그 속에서 앱이 어떻게 전체 시스템과 유기적으로 작동하는지 이해하는 데 많은 시간이 걸렸

습니다. 하지만 하나씩 이해 해가며 문제점을 해결하고 무사히 발표회를 하게 되어 뿌듯합니 다.

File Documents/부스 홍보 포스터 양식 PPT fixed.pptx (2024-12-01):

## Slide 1

양식

작품요약:
시각장애인들이 거리를 돌아다니다 다치는 경우를 많이 목격하여 만든 각장애인을 위한 주변 안내 AR

devMaxTrauma. Inc. ™
present

BL

(Blind Lumos)

기능:
- 사물을 인식해서 위험정도와 거리를 알려준다
- 안드로이드와 연동되서 FindMy™를 사용가능하다

™

자세히 알아보기

©devMaxTrauma. Inc. ™

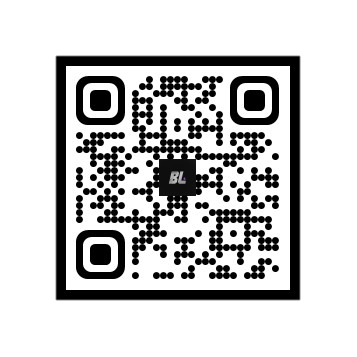
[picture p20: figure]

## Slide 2

디자인 철학

1. Simple Is The Best(SITB)
2. 저기에 너무 자세히 적으면 글이 너무 작아져서 그걸 모두 github readme.md로 적을거임
3. 작품명 Blind Lumos에 걸맞는 검은 배경에 흰 QR 디자인
4. 시각장애인들도 그나마 읽을 수 있도록 중요한 부분에 강조되고 큰 글씨

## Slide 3

안내사항

1. 양식 안에 들어갈 내용을 생각하기.
2. 디자인은 업체에서 자유롭게 해준다고 했으니, 내용만 생각할 것
3. //사진, 기능설명, 작품명, 작품개요 등 여러가지가 들어가면 좋음 모두 요약함
4. 검색창에 ‘박람회 부스’를 검색해서 다양한 예시들 참고할 것
5. 완성된 조는 조장이 반단톡에 제출할 것.(이번주 9/4 오전 10시까지)
6. 양식은 PPT, 한글파일 상관없으나 누가 열어도 알아볼 수 있게끔 작성할 것.
7. 가장 중요한 것은 가독성!

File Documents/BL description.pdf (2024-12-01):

# 라즈베리파이 와 안드로이드를 이용한 5

# BL(Blind Lumos)

소 속 | 전자제어과 학년 임베디드 시스템 실무 3
학 생 | 최지오 최지훈 송다연 , ,
지도 교사 | 김민정 선생님
제작 의도 | BL은 시각장애인들이 사물을 인식하여 위험한 물체를 구별하는 등 세상과 좀 더 상호 작용 할 수 있도록 구상해서 편리한 생활을 할 수 있도록 설계된 웨어러블 디바이 스입니다.
소프트웨어 | • 라즈베리파이 에서 tensorflow lite OpenCV 와 를 통하여 물체를 구분하고 렌더 5 해서 보여줌 • 안드로이드 기기와 블루투스 연결을 하여 기기가 멀리 떨어져 있어도 기 FindMy 능을 통해 기기를 쉽게 찾을 수 있음.

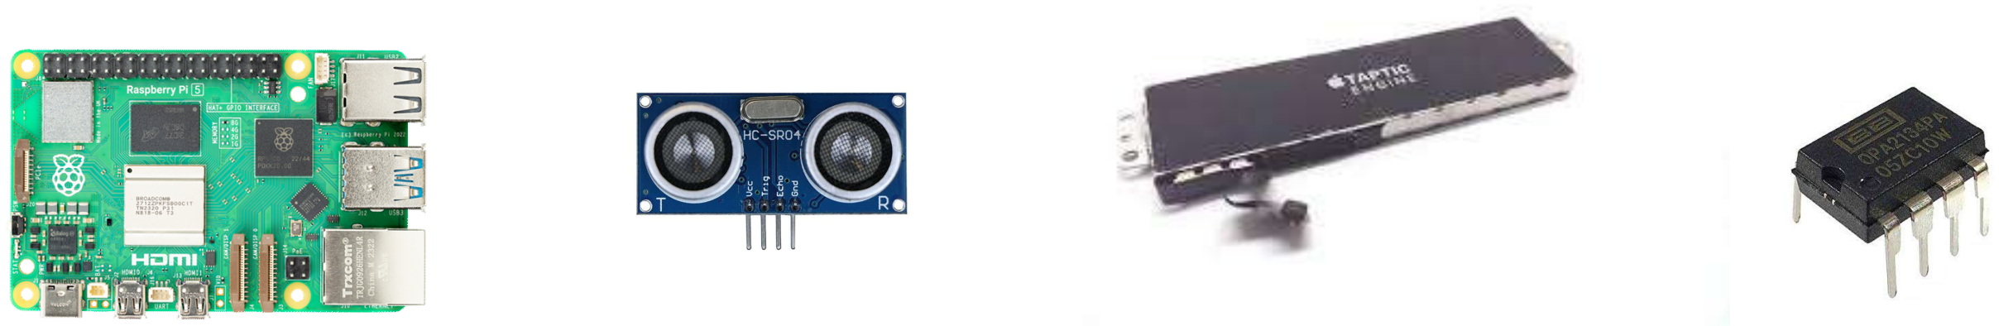
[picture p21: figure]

하드웨어 | Raspberry PI 5 HC-SR04 TapticEngine OPA2134PA

시연 내용

### 1. UI설명

rOS | mac | vnc | python IDE | SIDE 멀티플렛폼 기반으로 설계된 | 를 | 에서 | 로 보여주거나 자체개발한 | 인 | 를 활용하여
보여줌

### 2. 장착된 모습 보여줌

마네킹에 씌운 제품을 사람들한테 보여줌
3. | DEMO 실제 | 시간
사람들한테 착용하여 실제로 체험해볼 수 있음

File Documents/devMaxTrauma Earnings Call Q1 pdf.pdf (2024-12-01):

devMaxTrauma. Inc.

devMaxTrauma. Inc.

# Earnings Call Q1, 2024

### Blind Lumos

# I. Q1 성과 요약

# I. Q1 성과 요약

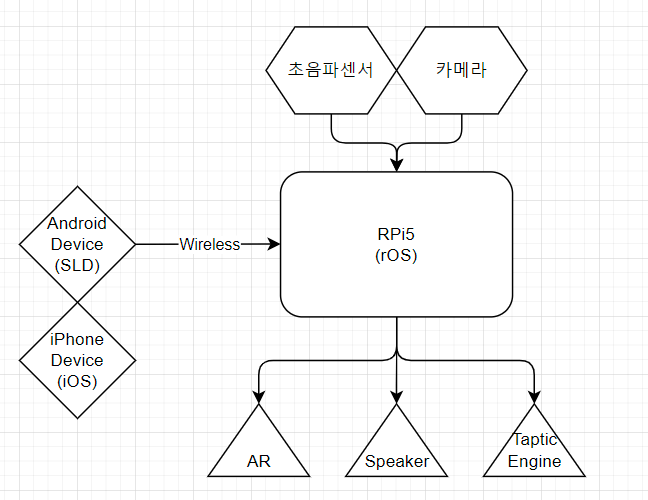
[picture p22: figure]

블럭도 개발

# I. Q1 성과 요약

### 소프트웨어 개발/SLD on Android

- Fragment 를 이용한 슬라이드 화면 구성(색맹보정 기능을 구현함)
- Fragment 마다 버튼을 눌렀을때 핸드폰에서 햅틱 피드백 기능을 구현함

# I. Q1 성과 요약

소프트웨어 개발/rOS

- Tensorflow와 OpenCV를 통하여 물체 인식 및 출력 가능함

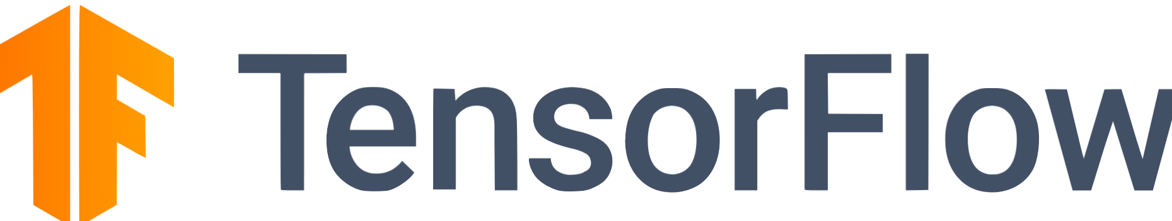
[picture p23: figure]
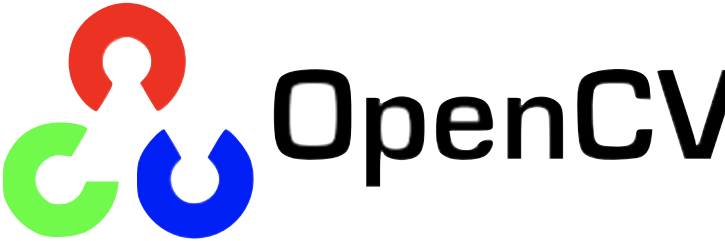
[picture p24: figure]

- 자체 파일 저장포맷 .rKY, .rCL, .rCC등의 포맷을 개발함
- 오로지 카메라 비전만을 이용하여 물체의 거리를 ±5% 이내의 오차로 측정 가능함
- 총합 1500줄의 새로운 코드

# I. Q1 성과 요약

### tOS에 대해

- tOS의 기존 역활: 라즈베리파이 통신을 통하여 탭틱엔진 제어
- rOS가 tOS를 통합함
- 아날로그 제어를 PWM으로 변경됨

# II. Q2 해야할 방향

# II. Q2 해야할 방향

### SLD on Android

- 라즈베리파이와 소켓통신을 통하여 신호 통신
- 음성인식을 통하여 전화연결(개발 중)
- UI 최적화

# II. Q2 해야할 방향

### rOS

- Tensorflow Lite로 라이브러리를 변경해서 프레임 향상(rOS Clannad.0 개발중)
- 초음파 센서로 근접할 경우 정밀 거리 측정
- 탭틱 엔진 구동
- SLD와 연동하기

# II. Q2 해야할 방향

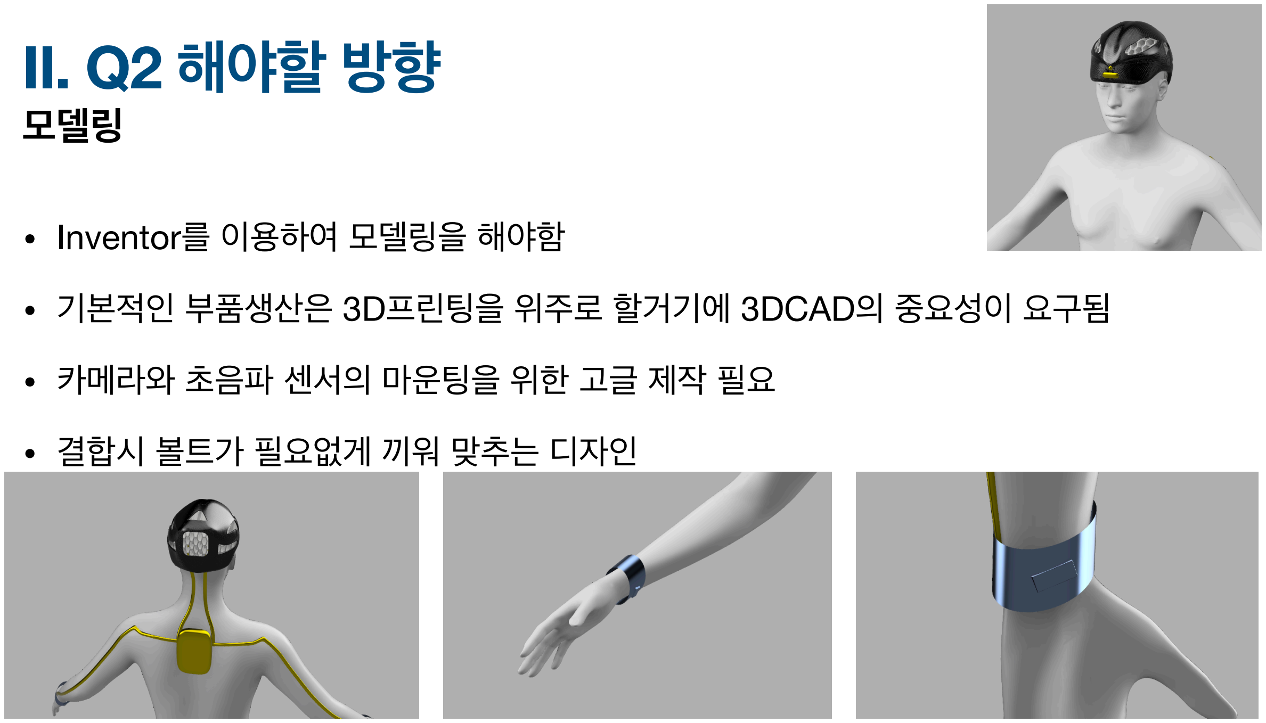
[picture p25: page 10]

### 모델링

- Inventor를 이용하여 모델링을 해야함
- 기본적인 부품생산은 3D프린팅을 위주로 할거기에 3DCAD의 중요성이 요구됨
- 카메라와 초음파 센서의 마운팅을 위한 고글 제작 필요
- 결합시 볼트가 필요없게 끼워 맞추는 디자인

# III. SLD on Android && rOSDemo

# IV. 라이센스 변경점

# IV. 라이센스 변경점

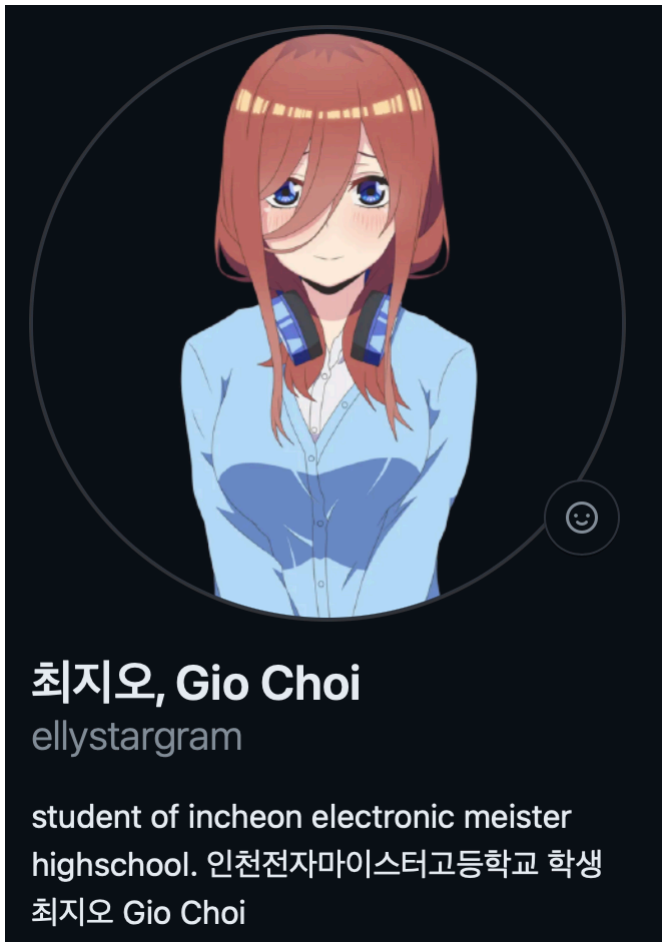
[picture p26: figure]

### Source Code Github

- rOS Github: github.com/ellystargram/rOS


- SLD Github: github.com/Anas1230/SLD

# V. QnAi

2024 devMaxTrauma. Inc.

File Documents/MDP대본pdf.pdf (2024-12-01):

## BL™ 발표 자료 v0.9

### 들어가면서

이 문서가 작성된 이유는 MDP발표회날 막힘없이 관람객에게 BL에 대해 설명하기 위해 작성 되었습니다. 기본적인 발표후 사람들이 질문할 것으로 예상되는 부분에 대해 대비해뒀습니 다. OpenAI 의 GPT-3.5를 활용하여 다듬어 졌습니다.

### 기본 설명

저희는 시각장애인들이 모두 전맹이 아니라는 점에서 착안하여 BL™을 개발하기 시작했습니 다. 실제로, 시각장애인의 대부분은 약간의 시력이 남아있거나 색약을 가지고 있으며, 전맹인 경우는 드뭅니다. 이러한 분들을 위해 남아있는 시각을 활용해 일상생활을 돕는 AR 기반 기 기를 만들었고, 그 결과 BL™이 탄생했습니다. BL™은 라즈베리파이에서 구동되며, TensorFlow Lite와 OpenCV를 사용한 약 2700줄의 Python 코드로 시각 정보를 처리합 니다. 또한 탭틱 엔진을 통해 즉각적인 피드백을 제공하여 사용자가 빠르게 상황을 파악할 수 있도록 돕습니다. 이 소프트웨어는 rOS™라 불리며, 저희가 개발한 전용 IDE인 SIDE™에서 만들어졌습니다. 필수 라이브러리만 있으면 다양한 플랫폼에서 실행할 수 있도록 설계된 것 이 특징입니다. 아무래도 AR장치이다 보니 지연시간을 줄이고 fps를 높이기 위해 노력했습 니다. 그 결과 다른 어떤 조의 코드보다 더 높은 fps를 유지할 수 있었습니다. 사용자가 기기 를 충전하기 위해 벗은 상태에서는 기기를 쉽게 찾을 수 있도록 안드로이드 기기와 블루투스 로 연결하여 SLD™앱을 통하여 FindMy™기능을 사용할 수 있습니다. SLD™앱에도 시각 장애인들이 쉽게 사용할 수 있도록 버튼을 크게크게 배치하였고 색약자들도 볼 수 있도록 여 러가지 색상 필터를 적용하여 소외되는 사람이 최대한 없도록 했습니다.

### 시나리오별 설명

BL™의 개발영감에 대한 설명: 친구의 아버지가 시각장애를 가지고 있으신대 아버지가 전맹 은 아니지만 부정확한 시각 정보를 바탕으로 생활하다 보니 어디 부딪히고 넘어지고 하면서 다리에 많은 상처가 생겨나가서 더이상의 사고를 방지하고자 안전한건 안전하다, 위험한건 위 험하다 기계장치의 힘을 빌려 빠르게 판단할 수 있도록 고안되었습니다.

BL™의 명칭에 대한 설명: BL™은 앞서 말했듯 시각장애인의 생활에 기반하여 만들어졌습니 다. 이를 나타내기 위한 이름으로 Blind Lumos (장님 불을 밝혀주다) 라는 의미를 내포하고 있습니다.

©devMaxTrauma. Inc.™ | 1

팀명 devMaxTrauma. Inc.™에 대한 설명: 아버지가 부딛히고 아파하던 모습을 보면 트라 우마가 떠올라 그 힘을 이용해서 다시는 이런일을 반복시키지 말자고 사기를 다질 수 있었습 니다. Trauma를 이용해 개발을 한다 해서 devMaxTrauma. Inc.™ 입니다.

무게가 너무 무겁다는 평에 대한 설명: BL™ v1은 현재 MVP(Minimum Viable Product) 단계이므로 타사 제품보다 다소 무겁게 느껴질 수 있습니다. 하지만 Exoshell™을 얇게 하거 나 Endobar™를 제거하는 등 무게를 줄일 방법이 다양하게 존재합니다. 더 가벼운 제품을 원하신다면 차세대 제품을 기대해 주세요.

Lightseal™이 너무 번거롭다는 평에 대한 설명: Lightseal™은 사용 중 빛이 들어오지 않 도록 얼굴에 맞춰 설계되었습니다. 얼굴 형태가 사람마다 다르기 때문에 커스터마이징이 필요 하지만, 쉽게 탈부착할 수 있도록 설계하여 편리하게 사용할 수 있습니다.

양산 가격에 대한 설명: BL™ v1의 경우 양산판매가격은 249,000KRW 로 예상됩니다. 시 각장애인들은 경제활동에 어려움을 겪고, 저희는 그들의 그런 사정을 잘 알기에 최대한 저렴 하게 판매할 수 있도록 노력중에 있습니다. 그러면서도 품질에는 절대 타협하지 않고 안전하 게 착용할 수 있도록 당사 기준에 부합하게 제작중에 있습니다.

호환성에 대한 설명: devMaxTrauma. Inc.™ 는 세계표준을 사랑합니다. 실제로 개발중에 도 세계표준 파일 확장자를 사용하고(.hwp 배척) (.dwg, .pdf, .docx) 저희 작품에 세상에 가장 표준적인 포트인 USB-C 포트를 군데군데 배치하였습니다. 또한 저희의 모든 소프트웨 어(rOS™, SLD™, SIDE™)는 https://github.com/ellystargram/ 통하여 OpenSource 로 공유되고 있습니다. 실제로 저희의 코드는 저희의 작품뿐 아니라 다른 조들의 작품에도 사 용(황선유)되거나 알고리즘을 영감받아 퍼포먼스 향상에 도움이(오지빈) 되었습니다.

내구성에 관한 설명: BL™의 Exoshell™ 및 BatPack™의 Exoshell™은 모두 PLA를 사 용하여 출력되었습니다. 따라서 경도는 준수한 편이지만 인장강도가 좋지는 않습니다. 다만 3D출력을 통한 높은 생산력을 바탁으로 쉬운 수리를 염두하고 설계했습니다.

부스 뒤에 왜 QR코드 가 있냐 묻는 경우에 관한 설명: 우리의 작품은 사회적 약자를 위하여 만들어진 작품입니다. 그런 작품을 설명하는 경우 사회적 약자를 포함하여 누구나 확인할 수 있도록 할 필요가 있습니다. 실물로 인쇄된 경우 확대를 할 수 없지만 인터넷상에 있으면 원하 는 만큼 확대 축소가 가능하기에 이런 방법이 저희작품에 더 어울린다 생각했습니다.

앞으로 업그레이드 계획에 대한 설명: AR가독성을 더 좋게 하고, LCD가 아닌 OLED디스플 레이를 활용하여 명암비를 높이겠습니다. 또한 AI도우미를 통합하여 Siri처럼 사용할 수 있게 하고싶습니다. 그러면서도 소프트웨어 최적화를 통해 라즈베리파이의 램용량을 줄여 가격을 더 내리고 싶습니다.

성능향상방법에 대한 설명: 간단하게 말하면 tensor thread와 main thread를 분리하였기 에 성능을 향상할 수 있었습니다. 자세한 방법은 https://github.com/ellystargram/rOS 를 참고해 주시기 바랍니다.

설계하면서 가장 중요하게 여긴 부분에 대한 설명: AR기기와 저희가 만드는 소프트웨어의 통 합이 가장 중요하다 생각합니다. 그러면서도 사용자 경험을 해치지 않도록 UI를 배치하고 커 널을 설계하는게 중요하다 되새기며 설계했습니다.

Tensor 정확성에 대한 설명: AR기기는 멀미를 최소화 하기 위해 빠른 응답성이 중요합니다. 그러기 위해 저희는 rOS를 개발할때 처리속도와 정확성에서 어느정도 타협을 했어야 했습니 다. 그뿐 아니라 Tensor thread와 main thread를 분리해서 최대한 성능을 올려야만 했습니 다. 물론 실제 AR에 비하면 아직도 반응속도가 느리긴 하지만 BL™ v1은 MVP 이기 때문에 다음 세대 제품이 기대하시기 바랍니다.

### “Designed by devMaxTrauma. Inc.™ in Incheon.”

### “Made on Earth by humans”

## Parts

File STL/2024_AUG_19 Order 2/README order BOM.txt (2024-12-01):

order BOM
한세트 만드는데 필요한 물품
1개: VisionFrameV2
1개: PCB_Braket
2개: FANHOLDER
2개: FANCATCHER
1개: BatPackCase
1개: BatPackCaseCover

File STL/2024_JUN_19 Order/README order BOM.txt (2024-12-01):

order BOM
2PCS: VisionFrameV2
2PCS: PCB_Braket
2PCS: LightSealGioV2
4PCS: FANHOLDER
4PCS: FANCATCHER
2PCS: BatPackCase
2PCS: BatPackCaseCover

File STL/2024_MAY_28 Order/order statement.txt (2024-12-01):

FANCATCHER 4pc
FANHOLDER 4pc
LightSealGioV2 2pc
PCB_Braket 2pc
VisionFrame 2pc

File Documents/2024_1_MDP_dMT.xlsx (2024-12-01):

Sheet: 신청내역
MDP 1차 실험실습 소모품 및 재료 구입 (기초금액산출내역서)
순번 | 품명 | 규격 | 단위 | 수량 | 단가(원) | 추정금액(원) | 비고(사이트) | 납품장소 | 규격문의
합 계 |  |  |  |  |  | 15711614.4 |  |  |  |  | 배송료
1 | LPM재단 나무판자 | 15T PB 밀키화이트 / 4.니게르화이트 / 200mmX300mm | 개 | 2 | 12000 | 28800 | https://smartstore.naver.com/yuksam/products/4528544732 | 2층 산학협력취업부 | 618(김민정) | 나무판
2 | LPM재단 나무판자 | 15T PB 밀키화이트 / 4.니게르화이트 / 배송메모: 200X500(2장 구매), 200X470(2장재단) | 개 | 2 | 14300 | 34320 | https://smartstore.naver.com/yuksam/products/4528544732 | 2층 산학협력취업부 | 618(김민정) | 나무판
3 | LPM재단 나무판자 | 15T PB 밀키화이트 / 4.니게르화이트 / 300mmX500mm | 개 | 1 | 16700 | 20040 | https://smartstore.naver.com/yuksam/products/4528544732 | 2층 산학협력취업부 | 618(김민정) | 나무판
4 | LPM재단 나무판자 | 15T PB 밀키화이트 / 4.니게르화이트 / 배송메모: 200X300(2장 구매), 191X270(2장재단) | 개 | 2 | 12000 | 28800 | https://smartstore.naver.com/yuksam/products/4528544732 | 2층 산학협력취업부 | 618(김민정) | 나무판
5 | LPM재단 나무판자 | 15T PB 밀키화이트 / 4.니게르화이트 / 배송메모: 500X600(1장 구매), 500X560(1장재단) | 개 | 1 | 10100 | 12120 | https://smartstore.naver.com/yuksam/products/4528544732 | 2층 산학협력취업부 | 618(김민정) | 나무판
6 | 아크릴 미러 | 500mmX470mm/1/3T/은경/사각 | 개 | 1 | 19200 | 23040 | https://smartstore.naver.com/haegongso/products/8206875182 | 2층 산학협력취업부 | 618(김민정) | 아크릴미러 | 3000
7 | LPM재단 나무판자 | 18T MDF 밀키화이트 35U E0 / 4.니게르화이트 / 배송메모: 400X900(1장 구매), 400X860(1장재단) | 개 | 1 | 33000 | 39600 | https://smartstore.naver.com/yuksam/products/5685887064 | 2층 산학협력취업부 | 618(김민정) | 나무판
8 | LPM재단 나무판자 | 30T PB 밀키화이트 /2.니게르화이트/[배송메모]100X500(2장 구매)/50X470(2장재단) | 개 | 2 | 19000 | 45600 | https://smartstore.naver.com/yuksam/products/486526197 | 2층 산학협력취업부 | 618(김민정) | 나무판
9 | LPM재단 나무판자 | 30T PB 밀키화이트 /2.니게르화이트/[배송메모]100X600(1장 구매)/50X560(1장재단) | 개 | 1 | 20600 | 24720 | https://smartstore.naver.com/yuksam/products/486526198 | 2층 산학협력취업부 | 618(김민정) | 나무판
10 | LPM재단 나무판자 | 9T MDF 밀키하우스 /[배송메모]300X500(1장 구매)/270X470(1장재단) | 개 | 1 | 10100 | 12120 | https://smartstore.naver.com/yuksam/products/502840210 | 2층 산학협력취업부 | 618(김민정) | 나무판
11 | 펠티어 소자 | [XD-7082] 70X70 정사각형 펠티어 쿨러(스트레이트 타입) | 개 | 4 | 19250 | 92400 | https://www.eleparts.co.kr/goods/view?no=11735435 | 2층 산학협력취업부 | 618(김민정) | 펠티에
12 | 온습도 센서 | [SEN0137] DHT22 온습도 센서 | 개 | 2 | 15070 | 36168 | https://www.eleparts.co.kr/goods/view?no=3101737 | 2층 산학협력취업부 | 618(김민정) | 온습도 센서
13 | UV LED바 | 5V UV LED바 5mm 비방수(365-370nm) / 배송요청란: 27cm(2개) | 개 | 2 | 8500 | 20400 | https://shopping.interpark.com/product/productInfo.do?prdNo=9768032547&dispNo=016001&bizCd=P01397 | 2층 산학협력취업부 | 618(김민정) | UV LED | 3500
14 | 터치센서 | [CJMCU-1010 ] 터치센서 | 개 | 12 | 2200 | 31680 | https://www.eleparts.co.kr/goods/view?no=7660902 | 2층 산학협력취업부 | 618(김민정) | 터치 센서
15 | LED BAR 완제품 | DC 12V 12X12 사각커버/주광색(하양색 6000k)/50cm/양쪽전선(각 1M) | 개 | 1 | 9750 | 11700 | https://smartstore.naver.com/sollux/products/4858256023 | 2층 산학협력취업부 | 618(김민정) | LED BAR | 3000
16 | LED BAR 완제품 | DC 12V 12X12 사각커버/주광색(하양색 6000k)/45cm/한쪽전선 2M | 개 | 2 | 8850 | 21240 | https://smartstore.naver.com/sollux/products/4858256023 | 2층 산학협력취업부 | 618(김민정) | LED BAR
17 | SMPS(안정기) | SMPS 12V/12V 60W | 개 | 2 | 16000 | 38400 | https://smartstore.naver.com/sollux/products/4858256023 | 2층 산학협력취업부 | 618(김민정) | SMPS
18 | 아크릴 | 아크릴 판재 투명 3T A3(290*410) | 개 | 2 | 5250 | 12600 | www.eleparts.co.kr/goods/view?no=30255 | 2층 산학협력취업부 | 618(김민정) | 아크릴판
19 | 오픈 센서 스위치 | 개폐형(DK4012T), DC 12V 24V | 개 | 1 | 21500 | 25800 | https://dkled.kr/product/오픈-센서-스위치-근접-자동-온오프-개폐형-장식장-도어-dk-5076/5076/category/1647/display/1/ (https://dkled.kr/product/%EC%98%A4%ED%94%88-%EC%84%BC%EC%84%9C-%EC%8A%A4%EC%9C%84%EC%B9%98-%EA%B7%BC%EC%A0%91-%EC%9E%90%EB%8F%99-%EC%98%A8%EC%98%A4%ED%94%84-%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) | 2층 산학협력취업부 | 618(김민정) | 오픈 센서 | 3000
20 | SMPS(안정기) | 추가상품: SMPS 12V 60W 방수형 IP67 3구 DK-1782 | 개 | 1 | 15900 | 19080 | https://dkled.kr/product/detail.html?product_no=1782 | 2층 산학협력취업부 | 618(김민정) | SMPS
21 | 파워코드전선 | 파워코드선 0.75SQ*2C 1M-IS, 전기코드선 DK-2165 대경엘이디 | 개 | 1 | 1200 | 1440 | https://dkled.kr/product/detail.html?product_no=2165 | 2층 산학협력취업부 | 618(김민정) | 파워코드
22 | LED 레고바 신형 전원케이블 | 전원케이블 B형 30cm | 개 | 1 | 900 | 1080 | https://dkled.kr/product/detail.html?product_no=3746 | 2층 산학협력취업부 | 618(김민정) | LED BAR
23 | LED 레고바 전용 연결케이블 | 연결케이블 2P 20cm, DK-3783 | 개 | 1 | 1100 | 1320 | https://dkled.kr/product/detail.html?product_no=3783 | 2층 산학협력취업부 | 618(김민정) | LED BAR
24 | LED | 12V 비방수 실내 포커스빔 LED모듈 클리어타입 가로*세로*높이 (80*22*15mm) / 빨간색 3개, 파란색 3개 | 개 | 6 | 2290 | 16488 | http://smart09.shop/goods/goods_view.php?goodsNo=1000541661&inflow=naver | 2층 산학협력취업부 | 618(김민정) | LED | 3000
25 | 지문인식센서 | AS608 호환 JB-101B 아두이노 지문 인식 센서 | 개 | 2 | 12440 | 29856 | https://smartstore.naver.com/misoparts/products/5600769605 | 2층 산학협력취업부 | 618(김민정) | 지문인식 센서 | 3000
26 | QR스캐너 | 바케이블 스캐너 GM811 시리즈 / DC 5V / 선택사항 03번 | 개 | 1 | 40720 | 48864 | http://item.gmarket.co.kr/DetailView/Item.asp?goodscode=2803147822&GoodsSale=Y&jaehuid=200001169 | 2층 산학협력취업부 | 618(김민정) | QR 스캐너 |  | 해외배송
27 | 영수증 프린터 | Heayzoki 열 영수증 프린터, 58mm, blue, 패키지구성(열프린터, USB 케이블, 광학디스크, 용지, 전원공급장치, 가죽케이스) | 개 | 1 | 46700 | 56040 | https://www.11st.co.kr/products/pa/5543711400 | 2층 산학협력취업부 | 618(김민정) | 영수증 프린터 |  | 해외배송
28 | 인체감지센서 | DC12-24V, PIR 스위치, 모션감지센서 | 개 | 2 | 8000 | 19200 | https://smartstore.naver.com/365diy/products/4675937429 | 2층 산학협력취업부 | 618(김민정) | 인체감지 센서
29 | 스텝모터 | SM24240 | 개 | 7 | 10516 | 88334.4 | https://www.eleparts.co.kr/goods/view?no=7451136 | 2층 산학협력취업부 | 618(김민정) | 스테핑 모터
30 | 금속탐지센서 | [MD-300] Coms 테스터기(MD-300) 금속 탐지기, 스피커/진동 알람, 원형 | 개 | 1 | 21240 | 25488 | https://www.eleparts.co.kr/goods/view?no=4076210 | 2층 산학협력취업부 | 618(김민정) | 금속탐지 센서
31 | 압력인식센서 | [Interlink ] 압력센서 FSR 406 Solder Tabs [30-73258] | 개 | 4 | 9790 | 46992 | https://www.devicemart.co.kr/goods/view?no=33868 | 2층 산학협력취업부 | 618(김민정) | 압력인식 센서
32 | 라즈베리파이 캠 | Camera Module 3 (라즈베리파이 카메라모듈 3) | 개 | 2 | 41800 | 100320 | https://www.eleparts.co.kr/goods/view?no=12391454 | 2층 산학협력취업부 | 618(김민정) | 라즈베리파이 캠
33 | PVC 벨트 | 재전매트 정전기방지 PVC Anti-static Mat 2T*600mm*1M / 상품1 / 3M | 개 | 3 | 17000 | 61200 | http://itempage3.auction.co.kr/DetailView.aspx?ItemNo=B590590747&frm3=V2 | 2층 산학협력취업부 | 618(김민정) | PVC 벨트 | 5000 | 제전방지매트
34 | 컨베이어 롤러 | 외경 50.8, 롤러길이 550-580 | 개 | 8 | 11000 | 105600 | https://smartstore.naver.com/khss/products/542783018 | 2층 산학협력취업부 | 618(김민정) | 컨베리어 롤러 | 6000
 | 프로파일 | 프로파일 길이1300mm /3030 / 901~1000mm | 개 | 5 | 10000 | 60000 | https://smartstore.naver.com/bandotec/products/7230610259 | 2층 산학협력취업부 | 618(김민정) | 프로파일 30x30
 | 폼보드 | 폼보드(60X90cm) / 흰색 / 5T_5장 | 개 | 2 | 31500 | 75600 | https://www.coupang.com/vp/products/191728543?itemId=548321785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 | 2층 산학협력취업부 | 618(김민정) | 폼보드
 | 압력센서 | [Interlink] 압력센서 FSR 402 Solder Tabs [30-81794] | 개 | 4 | 7920 | 38016 | https://www.devicemart.co.kr/goods/view?no=33870 | 2층 산학협력취업부 | 618(김민정) | 압력 센서
35 | 라즈베리파이 카메라모듈 | [RASPBERRY-PI] 라즈베리파이 HQ 카메라모듈 C/CS mount (Raspberry Pi High Quality Camera) | 개 | 2 | 79200 | 190080 | https://www.devicemart.co.kr/goods/view?no=12543579 | 2층 산학협력취업부 | 618(김민정) | 라즈베리파이 캠
36 | SMPS(안정기) | [파워캅] STAR 50S-F-12T (50W 12V 터미널블록타입) | 개 | 2 | 33880 | 81312 | https://www.devicemart.co.kr/goods/view?no=12544964 | 2층 산학협력취업부 | 618(김민정) | 인체감지 센서
37 | 인체감지센서 | [SMG-A] 인체감지센서모듈 HC-SR501 [SZH-EK052] | 개 | 3 | 1430 | 5148 | https://www.devicemart.co.kr/goods/view?no=1287086 | 2층 산학협력취업부 | 618(김민정) | 파워
38 | DC모터 | [㈜디엔지위드] 기어모터 RB-35GM 21TYPE (12V) | 개 | 5 | 15620 | 93720 | https://www.devicemart.co.kr/goods/view?no=1326494 | 2층 산학협력취업부 | 618(김민정) | 기어DC모터
39 | 모터 드라이버 | [SMG] 2A L298 모터드라이버 모듈 (아두이노 호환) [SZH-EK001] | 개 | 10 | 2200 | 26400 | https://www.devicemart.co.kr/goods/view?no=1278835 | 2층 산학협력취업부 | 618(김민정) | DC모터 드라이버
40 | 스텝모터 | [주식회사 뉴티씨(NEWTC)] 스테핑모터 1.7kg급 (SE-SM243) | 개 | 5 | 44000 | 264000 | https://www.devicemart.co.kr/goods/view?no=19764 | 2층 산학협력취업부 | 618(김민정) | 스테핑 모터
41 | Altera디바이스용 USB블라스타 | FM-USBBLASTER V01 | 개 | 10 | 49500 | 594000 | https://www.newtc.co.kr/dpshop/shop/item.php?it_id=1373027044 | 10층 전문교육부 | 675(손한옥) | USB ISP
42 | 아두이노 USB to UART 모듈 | FT232RL | 개 | 20 | 4290 | 102960 | https://www.devicemart.co.kr/goods/view?no=1290042 | 10층 전문교육부 | 675(손한옥) | USB to UART
43 | USB 2.0 케이블 Mini 5P | NMC-UM210, 1m | 개 | 20 | 1089 | 26136 | https://www.devicemart.co.kr/goods/view?no=10923751 | 10층 전문교육부 | 675(손한옥) | USB 케이블
44 | 블루투스 직렬포트 모듈 | HC-05 | 개 | 20 | 11000 | 264000 | https://www.devicemart.co.kr/goods/view?no=1289993 | 10층 전문교육부 | 675(손한옥) | 블루투스 모듈
45 | 블루투스 직렬포트 모듈 | HC-06 | 개 | 20 | 7150 | 171600 | https://www.devicemart.co.kr/goods/view?no=1278220 | 10층 전문교육부 | 675(손한옥) | 블루투스 모듈
46 | 시리얼 와이파이 모듈 | ESP8266 ESP-01 | 개 | 20 | 3520 | 84480 | https://www.devicemart.co.kr/goods/view?no=1383320 | 10층 전문교육부 | 675(손한옥) | ESP8266
47 | 직렬 포트 WIFI 무선 ESP-01 어댑터 모듈 | ESP-01용 | 개 | 20 | 3630 | 87120 | https://www.devicemart.co.kr/goods/view?no=6500189 | 10층 전문교육부 | 675(손한옥) | ESP-01 어댑터
48 | [새한미디어] 디지털 포켓 테스터기 SH-3234 | 55(W)x109(H)x12D(mm), 약100g | 개 | 10 | 38060 | 456720 | https://www.devicemart.co.kr/goods/view?no=10937425 | 7층 교육정보부 | 668(조희은) | 테스터기
49 | 도트매트릭스 모듈 | 8*32, 적색 | 개 | 20 | 15000 | 360000 | http://item.gmarket.co.kr/Item?goodscode=882554150 | 6층 명장양성부 | 661(김득식) | 도트매트릭스 모듈
50 | IC | MAX7219 | 개 | 20 | 1200 | 28800 | http://item.gmarket.co.kr/Item?goodscode=1570812229 | 6층 명장양성부 | 661(김득식) | LED 드라이버 IC
51 | 라즈베리파이 4 | Model B, 4GB | 개 | 4 | 101200 | 485760 | https://www.eleparts.co.kr/goods/view?no=8195636 | 6층 명장양성부 | 661(김득식) | 라즈베리파이4 4G
52 | 라즈베리파이 4 | Model B, 8GB | 개 | 1 | 134200 | 161040 | https://www.eleparts.co.kr/goods/view?no=9467937 | 6층 명장양성부 | 661(김득식) | 라즈베리파이4 8G
53 | 심박수 센서 | 공급 전압 3.3V~5V | 개 | 1 | 11960 | 14352 | https://www.icbanq.com/P007324753 | 8층 전자회로과 | 680(정채린) | 심박수 센서
54 | 라즈베리파이 방열판 | 라즈베리파이4 B 알루미늄 방열판 | 개 | 10 | 4700 | 56400 | https://www.icbanq.com/P010372160 | 8층 전자회로과 | 680(정채린) | 라즈베리파이 방열판 |  | 해외재고
55 | 유심트레이 | 16GB | 개 | 1 | 15070 | 18084 | http://www.tmon.co.kr/deal/17659654226?opt_deal_srl=17659654726&coupon_srl=3108794 | 8층 전자회로과 | 680(정채린) | 유심트레이 |  | 해외구매대행
56 | 비접촉 온도센서 모듈 | 측정범위 : -70°C ~ 380°C | 개 | 2 | 24480 | 58752 | https://www.devicemart.co.kr/goods/view?no=10918253 | 8층 전자회로과 | 680(정채린) | 온도센서 모듈
57 | 절연테이프 | 15M | 개 | 2 | 6400 | 15360 | https://www.coupang.com/vp/products/4342001694?itemId=5083263398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 | 8층 전자회로과 | 680(정채린) | 절연테이프
58 | 라즈베리파이용 마이크 | 라즈베리 파이 미니 USB 마이크, 무료 드라이버 | 개 | 1 | 8000 | 9600 | https://ko.aliexpress.com/item/1005001689860044.html?_t=pvid%3Ae4d8d3db-7933-4268-aa92-e50db58a3915 | 8층 전자회로과 | 680(정채린) | 라즈베리파이 마이크
59 | 식물재배 LED바 | 식물재배 LED바(삼성칩 PCB타입)-50cm /식물성장 조명 풀스펙트럼 | 개 | 3 | 10000 | 36000 | http://item.gmarket.co.kr/DetailView/Item.asp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 | 8층 전자회로과 | 680(정채린) | LED BAR
60 | 파이프 | PVC부속 파이프 마개 배관 50 개몫 14quot 수나사 - 14quot 엘보우 ro 워터 피팅 6.5mm pom 호스 pe 퀵 커넥터 워터 필터 부품 | 개 | 2 | 18800 | 45120 | https://www.coupang.com/vp/products/6824057820?itemId=16182420489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 | 8층 전자회로과 | 680(정채린) | 파이프 |  | 해외배송
61 | 실리콘 | 수달 픽스올 실리콘 플렉시 고탄성 방수 보수 틈새 메꿈 냄새없는 강력접착실리콘 검정색 290ml | 개 | 1 | 25500 | 30600 | https://www.coupang.com/vp/products/6168899507?itemId=12027662311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 | 8층 전자회로과 | 680(정채린) | 실리콘
62 | 방수테이프 | 블랙, 152cm | 개 | 2 | 13800 | 33120 | https://www.coupang.com/vp/products/6850245035?itemId=16316780269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 | 8층 전자회로과 | 680(정채린) | 방수테이프
63 | 실리콘튜브 | 실리콘호스 실리콘튜브 내경18mm외경22mm (반투명) 2M | 개 | 1 | 18600 | 22320 | http://item.gmarket.co.kr/Item?goodscode=2065254961 | 8층 전자회로과 | 680(정채린) | 실리콘튜브
64 | 마스킹테이프 | 3M 종이 마스킹 테이프 아이보리 50mm 보양 도색 도장 | 개 | 1 | 5350 | 6420 | http://item.gmarket.co.kr/DetailView/Item.asp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 | 8층 전자회로과 | 680(정채린) | 마스킹테이프
65 | 워터펌프 | 다이아프램펌프 80W DC12V 워터펌프 캠핑 세차 샤플로 | 개 | 2 | 29000 | 69600 | http://item.gmarket.co.kr/DetailView/Item.asp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 | 8층 전자회로과 | 680(정채린) | 워터펌프
66 | 실리콘호스 | 실리콘호스 실리콘튜브 내경3mm외경6.5mm (반투명) 5M | 개 | 1 | 10600 | 12720 | http://item.gmarket.co.kr/Item?goodscode=2051360014 | 8층 전자회로과 | 680(정채린) | 실리콘호스
67 | 스펀지 | 수경재배 포트 스펀지 60mm 세트 10pcs | 개 | 2 | 7900 | 18960 | https://www.coupang.com/vp/products/1430246673?itemId=2470917817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 | 8층 전자회로과 | 680(정채린) | 스펀지
68 | 구절판 | 가로세로 280 높이 60 | 개 | 2 | 12900 | 30960 | https://www.coupang.com/vp/products/3441833?itemId=16193134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 | 8층 전자회로과 | 680(정채린) | 구절판
69 | 조립형 강아지집 | 57x44x57 | 개 | 1 | 50400 | 60480 | https://www.coupang.com/vp/products/6882206070?itemId=16496275130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 | 8층 전자회로과 | 680(정채린) | 조립형 강아지집
70 | 미니 온풍기 | 밑면지름100x높이 190(cm) | 개 | 1 | 35000 | 42000 | https://www.coupang.com/vp/products/6962966101?itemId=16957887522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 | 8층 전자회로과 | 680(정채린) | 미니 온풍기
71 | 열전소자 냉각펌프 | 8mm | 개 | 4 | 3500 | 16800 | https://www.coupang.com/vp/products/205391824?itemId=604975034&vendorItemId=4585804000&isAddedCart= | 8층 전자회로과 | 680(정채린) | 열전소자 냉각펌프
72 | 열전소자 수냉키트 | 60 * 40 * 55mm | 개 | 2 | 26000 | 62400 | https://www.coupang.com/vp/products/207876643?itemId=616042182&vendorItemId=4616083228&isAddedCart= | 8층 전자회로과 | 680(정채린) | 열전소자 수냉키트
73 | 펠티어 소자 | TEM1-12710 | 개 | 2 | 38000 | 91200 | https://www.coupang.com/vp/products/148262831?itemId=428820381&vendorItemId=4057240039&isAddedCart= | 8층 전자회로과 | 680(정채린) | 펠티에
74 | 펠티어 소자 | TEC1-12706 | 개 | 2 | 5000 | 12000 | https://www.coupang.com/vp/products/207471920?itemId=614187617&vendorItemId=4611632958&isAddedCart= | 8층 전자회로과 | 680(정채린) | 펠티에
75 | 아크릴판 | 아크릴판 A3 3T 297x420mm, 투명 | 개 | 3 | 15800 | 56880 | https://www.coupang.com/vp/products/7029626796?itemId=17343631393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 | 8층 전자회로과 | 680(정채린) | 아크릴판
76 | 샤칸 익스트림 써멀구리스 | 4g | 개 | 1 | 12000 | 14400 | https://www.coupang.com/vp/products/5754620438?itemId=9728591428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 | 8층 전자회로과 | 680(정채린) | 써멀구리스
77 | 락카스프레이 | 백색 | 개 | 5 | 2255 | 13530 | https://www.devicemart.co.kr/goods/view?no=14111198 | 8층 전자회로과 | 680(정채린) | 락카스프레이
78 | 락카스프레이 | 은색 | 개 | 5 | 2255 | 13530 | https://www.devicemart.co.kr/goods/view?no=14111198 | 8층 전자회로과 | 680(정채린) | 락카스프레이
79 | 보수시트 | FDWM-14 캐러멜애쉬 몰딩 | 개 | 1 | 7000 | 8400 | https://www.coupang.com/vp/products/6654413744?itemId=15257422281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 | 8층 전자회로과 | 680(정채린) | 보수시트
80 | 적외선 비접촉 온도센서 | 정격전압 : 3V ~ 5V / FOV : 35° / 인터페이스 : I2C / 측정범위 : -70°C ~ 380°C / 기울기 보정기능 탑재사양 | 개 | 1 | 26400 | 31680 | https://www.devicemart.co.kr/goods/view?no=13067760 | 8층 전자회로과 | 680(정채린) | 온도센서 모듈
81 | 토양 습도 센서 | 작동 전압 : 3.3V ~ 5V / 인터페이스 : PH2.0-4Pin / 사이즈 : 23mm X 102mm | 개 | 5 | 5800 | 34800 | https://www.devicemart.co.kr/goods/view?no=12146922 | 8층 전자회로과 | 680(정채린) | 토양습도 센서
82 | 불꽃감지센서 모듈 | NS-FDSM Ver 7.0 | 개 | 3 | 16500 | 59400 | https://www.devicemart.co.kr/goods/view?no=1246940 | 8층 전자회로과 | 680(정채린) | 불꽃감지센서 모듈
83 | 벽지 | 공팡이방지 일반풀바른벽지 100cm | 개 | 1 | 6300 | 7560 | https://www.coupang.com/vp/products/6487230305?itemId=14226156640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 | 8층 전자회로과 | 680(정채린) | 벽지
84 | 바코드 스캐너 모듈 | Interface : USB / Scan Element Type : Linear CCD / CPU : 32 bit / Optical Resolution : 2500 / Decoding speed : 300times/s / Light Source : Visible red light, 625±10nm | 개 | 7 | 41800 | 351120 | https://www.devicemart.co.kr/goods/view?no=10826182 | 8층 전자회로과 | 680(정채린) | 바코드스캐너 모듈
85 | 라즈베리파이용 카메라 | 23.86 x 25 x 9 | 개 | 10 | 41800 | 501600 | https://www.devicemart.co.kr/goods/view?no=1077951 | 8층 전자회로과 | 680(정채린) | 라즈베리파이 캠
86 | LED MATRIX | 32 x 64 | 개 | 1 | 77000 | 92400 | https://www.devicemart.co.kr/goods/view?no=1246920 | 8층 전자회로과 | 680(정채린) | LED 매트릭스 |  | 해외배송
87 | 아크릴 | 2T 투명 아크릴, 425x425 | 개 | 11 | 6270 | 82764 | https://naver.me/G8tznD2z | 8층 전자회로과 | 680(정채린) | 아크릴판
88 | 사물인식 AI 카메라 | 38(W)*47(H) | 개 | 3 | 85200 | 306720 | https://www.devicemart.co.kr/goods/view?no=12169644 | 8층 전자회로과 | 680(정채린) | 사물인식 AI 카메라
89 | RGB컬러 센서 | TCS34725 RGB 컬러 센서 [SEN0212] | 개 | 3 | 10670 | 38412 | https://www.devicemart.co.kr/goods/view?no=1324053 | 8층 전자회로과 | 680(정채린) | RGB컬러 센서
90 | 라즈베리파이 방열판 | 라즈베리파이4 구리 방열판 세트 [RBP-017] | 개 | 10 | 2750 | 33000 | https://www.devicemart.co.kr/goods/view?no=12496234 | 8층 전자회로과 | 680(정채린) | 라즈베리파이 방열판
91 | 배터리홀더 | AA배터리홀더 2선 전원타입 (직렬) | 개 | 2 | 1320 | 3168 | https://www.devicemart.co.kr/goods/view?no=3900 | 8층 전자회로과 | 680(정채린) | 배터리홀더
92 | 배터리홀더 | AA배터리 건전지홀더 2선 전원타입 | 개 | 2 | 1980 | 4752 | https://www.devicemart.co.kr/goods/view?no=3090 | 8층 전자회로과 | 680(정채린) | 배터리홀더
93 | Pixy2 팬/틸트 서보 모터 키트 | Pan/Tilt2 Servo Motor Kit for Pixy2 - Dual Axis Robotic Camera Mount | 개 | 1 | 32450 | 38940 | https://www.devicemart.co.kr/goods/view?no=12374630 | 8층 전자회로과 | 680(정채린) | 팬/틸트 서보모터 키트
94 | 카메라모듈 | 12.3 메가픽셀 고해상도 Sony IMX477 센서 / 기존 IMX219 대비 저조도 퍼포먼스 향상 / 백포커스, C 마운트 및 CS 마운트 렌즈 지원 | 개 | 1 | 79200 | 95040 | https://www.devicemart.co.kr/goods/view?no=12543579 | 8층 전자회로과 | 680(정채린) | 라즈베리파이 캠
95 | 광각 렌즈 | 라즈베리파이 HQ 카메라모듈용 6mm 광각 렌즈 3MP | 개 | 1 | 38500 | 46200 | https://www.devicemart.co.kr/goods/view?no=12543580 | 8층 전자회로과 | 680(정채린) | 광각렌즈
96 | 비행제어 센서 모듈 | 10축 센서 | 개 | 3 | 26400 | 95040 | https://www.devicemart.co.kr/goods/view?no=1289994 | 8층 전자회로과 | 680(정채린) | 비행제어 센서 모듈
97 | 드론프레임 | 쿼드콥터 드론본체와 랜딩스키드 | 개 | 1 | 77000 | 92400 | http://www.allfirstedu.co.kr/goods/goods_view.php?goodsNo=1000001306 | 8층 전자회로과 | 680(정채린) | 드론프레임
98 | 드론 랜딩 다리 | 드론 450 프레임 랜딩 다리 | 개 | 1 | 12300 | 14760 | http://www.allfirstedu.co.kr/goods/goods_view.php?goodsNo=1000000186 | 8층 전자회로과 | 680(정채린) | 드론 랜딩 다리
99 | 브러시리스 모터 | 2212 1000kv | 개 | 4 | 16900 | 81120 | http://www.allfirstedu.co.kr/goods/goods_view.php?goodsNo=1000000083 | 8층 전자회로과 | 680(정채린) | 브러시리스 모터
100 | 드론 프로펠러 | 드론 프로펠러 / 1045R 1045 CW/CCW Prop Set | 개 | 1 | 20000 | 24000 | http://www.allfirstedu.co.kr/goods/goods_view.php?goodsNo=1000001175 | 8층 전자회로과 | 680(정채린) | 드론 프로펠러
101 | 변속기 | 30A, SimonK 30A Firmware Brushless ESC w/ 3A 5V BEC for F450 F550 | 개 | 4 | 19780 | 94944 | http://www.allfirstedu.co.kr/goods/goods_view.php?goodsNo=1000001042 | 8층 전자회로과 | 680(정채린) | 변속기
102 | 시러스 전원 분배 보드 | with T connector | 개 | 1 | 9000 | 10800 | http://www.allfirstedu.co.kr/goods/goods_view.php?goodsNo=1000000046 | 8층 전자회로과 | 680(정채린) | 전원분배 보드
103 | 벨크로 타이 케이블 | 20*2cm | 개 | 1 | 8500 | 10200 | http://www.allfirstedu.co.kr/goods/goods_view.php?goodsNo=1000000009 | 8층 전자회로과 | 680(정채린) | 타이 케이블
104 | 육각 드라이버 셋트 | 4pcs White Steel Hexagonal Screw Driver | 개 | 1 | 20000 | 24000 | http://www.allfirstedu.co.kr/goods/goods_view.php?goodsNo=1000001144 | 8층 전자회로과 | 680(정채린) | 육각 드라이버 세트
105 | 배터리홀더 | 알씨구 rc카 배터리 리포 YK4082 TRX4 SCX10 아르마 3셀 3S 5200 | 개 | 1 | 53000 | 63600 | https://smartstore.naver.com/pushking/products/5621261740 | 8층 전자회로과 | 680(정채린) | 배터리셀
 | ATMEGA128 | ATmega128 학습용 USB 모듈 V3.0 | 개 | 10 | 55000 | 660000 | https://newtc.co.kr/dpshop/shop/item.php?it_id=1672795879 | 8층 전자회로과 | 680(정채린) | ATmega128
106 | AC-DC 컨버터 | AC 220V / DC 5V 1A | 개 | 2 | 10700 | 25680 | https://www.11st.co.kr/products/5485015946?NaPm=ct=lfdc6neg|ci=e274b76c282dfae9eacb577f2f760b3fae94aba8|tr=slsl|sn=17703|hk=ae6d055b0b82ff6710059ff47d71f92edb498190&utm_term=&utm_campaign=%B3%D7%C0%CC%B9%F6pc_%B0%A1%B0%DD%BA%F1%B1%B3%B1%E2%BA%BB&utm_source=%B3%D7%C0%CC%B9%F6_PC_PCS&utm_medium=%B0%A1%B0%DD%BA%F1%B1%B3 | 3층 교육연구부 | 634(이성경) | AC-DC 컨버터
107 | AC-DC 컨버터 | AC 220V / DC 12V 0.4A | 개 | 2 | 10700 | 25680 | https://www.11st.co.kr/products/5485015946?NaPm=ct=lfdc6neg|ci=e274b76c282dfae9eacb577f2f760b3fae94aba8|tr=slsl|sn=17703|hk=ae6d055b0b82ff6710059ff47d71f92edb498190&utm_term=&utm_campaign=%B3%D7%C0%CC%B9%F6pc_%B0%A1%B0%DD%BA%F1%B1%B3%B1%E2%BA%BB&utm_source=%B3%D7%C0%CC%B9%F6_PC_PCS&utm_medium=%B0%A1%B0%DD%BA%F1%B1%B3 | 3층 교육연구부 | 634(이성경) | AC-DC 컨버터
108 | 커넥터 | 일자 스카치락 0.5-1SQ (적색) 10개 무탈피 커넥터 | 개 | 2 | 2500 | 6000 | http://item.gmarket.co.kr/DetailView/Item.asp?goodscode=2430219403&GoodsSale=Y&jaehuid=200001169 | 3층 교육연구부 | 634(이성경) | 커넥터
109 | 커넥터 | 003/방수솔더링-슬리브 / 청색(2.5sq)-5개 | 개 | 2 | 2500 | 6000 | G마켓 - 방수 솔더링 슬리브 청색 2.5sq 5개 열수축 단자 절연 (gmarket.co.kr) (http://item.gmarket.co.kr/Item?goodscode=1729129734) | 3층 교육연구부 | 634(이성경) | 커넥터
110 | 열풍기 | BOSCH 보쉬 열풍기 히팅건 GHG16-50 노즐2종포함 | 개 | 1 | 63000 | 75600 | BOSCH 보쉬 열풍기 히팅건 GHG16-50 노즐2종포함 (11st.co.kr) (https://www.11st.co.kr/products/1177388207) | 3층 교육연구부 | 634(이성경) | 열풍기
111 | 라이트 | 동양 LED 직부등 15W/주광색 | 개 | 1 | 9000 | 10800 | https://www.11st.co.kr/products/3973885115?NaPm=ct=lfe57jww|ci=6e8b1e9b520c44715bcc4ec5d4e7ddbebf24181a|tr=slsl|sn=17703|hk=a433ee0cfe0339775799f0ce161ca5ddf6af4fed&utm_term=&utm_campaign=%B3%D7%C0%CC%B9%F6pc_%B0%A1%B0%DD%BA%F1%B1%B3%B1%E2%BA%BB&utm_source=%B3%D7%C0%CC%B9%F6_PC_PCS&utm_medium=%B0%A1%B0%DD%BA%F1%B1%B3 | 3층 교육연구부 | 634(이성경) | LED 라이트
112 | 동박 테이프 | 구리 테이프 전도성 동박 동테이프 두께 0.06mm /폭 10mm/길이 20M | 개 | 1 | 3000 | 3600 | https://smartstore.naver.com/delona/products/4976859891 | 3층 교육연구부 | 634(이성경) | 동박 테이프
113 | ic | NE555DR(SMD) | 개 | 50 | 330 | 19800 |  | 3층 교육연구부 | 634(이성경)
114 | PCB | 20x60mm 양면 가공 / 주문제작 | 개 | 100 | 1750 | 210000 |  | 3층 교육연구부 | 634(이성경)
115 | 칩LED | SMD 2012타입 적색 | 개 | 55 | 90 | 5940 |  | 3층 교육연구부 | 634(이성경)
116 | 칩저항 | SMD 2012타입 560Ω | 개 | 100 | 10 | 1200 |  | 3층 교육연구부 | 634(이성경)
117 | 칩저항 | SMD 2012타입 3㏀ | 개 | 100 | 10 | 1200 |  | 3층 교육연구부 | 634(이성경)
118 | 칩저항 | SMD 2012타입 4.7㏀ | 개 | 100 | 10 | 1200 |  | 3층 교육연구부 | 634(이성경)
119 | 칩콘덴서 | SMD 2012타입 0.1㎌ | 개 | 100 | 30 | 3600 |  | 3층 교육연구부 | 634(이성경)
120 | 칩콘덴서 | SMD 2012타입 0.0022㎌ | 개 | 100 | 30 | 3600 |  | 3층 교육연구부 | 634(이성경)
121 | 저항 | 33Ω / 0.5W | 개 | 100 | 10 | 1200 |  | 3층 교육연구부 | 634(이성경)
122 | 스피커 | 삼성 AKG이어폰 C타입(블랙) | 개 | 2 | 30000 | 72000 | https://smartstore.naver.com/_next_/products/6534428154 | 3층 교육연구부 | 634(이성경) | 스피커
123 | TR | 2SC1815 | 개 | 30 | 30 | 1080 |  | 3층 교육연구부 | 634(이성경)
124 | TR | 2N2222 | 개 | 30 | 30 | 1080 |  | 3층 교육연구부 | 634(이성경)
125 | 비닐 접착기 | SK-210 러브러 | 개 | 1 | 30000 | 36000 | https://smartstore.naver.com/hmpacking/products/8062371089 | 3층 교육연구부 | 634(이성경) | 비닐 접착기
126 | 핀헤더 | 1x40Pin Straight(2.54mm) | 개 | 10 | 135 | 1620 |  | 3층 교육연구부 | 634(이성경)
127 | 무선 키보드/마우스 | SRP-9500 화이트색상 | EA | 2 | 59000 | 141600 | G마켓 - 삼성 무선 키보드/마우스 세트 SRP-9500 (gmarket.co.kr) (http://item.gmarket.co.kr/Item?goodscode=1986855253) | 7층 정보통신과 | 673(채광원) | 키보드/마우스
128 | 투명 강력접착제 | 아크릴용 | EA | 4 | 5800 | 27840 | G마켓 - 투명 강력접착제 본드 아크릴 목공 순간 접착제 금속 (gmarket.co.kr) (http://item.gmarket.co.kr/Item?goodscode=1723206719) | 7층 정보통신과 | 673(채광원) | 접착제
129 | 카시오 계산기 | DF-120FM | EA | 2 | 40000 | 96000 | G마켓 - 오피스네오/전자계산기 모음/카시오/누리안/캐논 (gmarket.co.kr) (http://item.gmarket.co.kr/Item?goodsCode=2005157549&jaehuid=) | 7층 정보통신과 | 673(채광원) | 계산기
130 | 정밀 드라이버 세트 | 9pcs | EA | 1 | 19500 | 23400 | G마켓 - 정밀 드라이버 세트 550122 9pcs NAVI (gmarket.co.kr) (http://item.gmarket.co.kr/Item?goodscode=2039649217) | 7층 정보통신과 | 673(채광원) | 드라이버 세트
131 | 라즈베리파이 10.1인치 터치스크린 | 10.1인치 | EA | 3 | 199100 | 716760 | 라즈베리파이 10.1인치 터치스크린 LCD 모니터 [CN0364] / 디바이스마트 (devicemart.co.kr) (https://www.devicemart.co.kr/goods/view?no=1383616) | 7층 정보통신과 | 673(채광원) | 터치스크린
132 | 알루미늄 프로파일 30x30 | 1600 | mm | 2 | 22000 | 52800 | http://item.gmarket.co.kr/Item?goodscode=2248358945 | 7층 정보통신과 | 673(채광원) | 프로파일 30x30
133 | 알루미늄 프로파일 30x30 | 1500 | mm | 2 | 9500 | 22800 | http://item.gmarket.co.kr/Item?goodscode=2206332663 | 7층 정보통신과 | 673(채광원) | 프로파일 30x30
134 | 알루미늄 프로파일 30x30 | 1000 | mm | 6 | 10500 | 75600 | http://item.gmarket.co.kr/Item?goodscode=1564045353 | 7층 정보통신과 | 673(채광원) | 프로파일 30x30
135 | 알루미늄 프로파일 30x30 | 800 | mm | 5 | 8500 | 51000 | http://item.gmarket.co.kr/Item?goodscode=1689094770 | 7층 정보통신과 | 673(채광원) | 프로파일 30x30
136 | 알루미늄 프로파일 30x30 | 750 | mm | 2 | 12000 | 28800 | http://item.gmarket.co.kr/Item?goodscode=2248342553 | 7층 정보통신과 | 673(채광원) | 프로파일 30x30
137 | 알루미늄 프로파일 30x30 | 400 | mm | 2 | 5500 | 13200 | http://item.gmarket.co.kr/Item?goodscode=1689094894 | 7층 정보통신과 | 673(채광원) | 프로파일 30x30
138 | 알루미늄 프로파일 30x30 | 300 | mm | 2 | 4500 | 10800 | http://item.gmarket.co.kr/Item?goodscode=1689094941 | 7층 정보통신과 | 673(채광원) | 프로파일 30x30
139 | LED 아케이드 버튼 스위치 | 100 | mm | 2 | 8250 | 19800 | https://www.devicemart.co.kr/goods/view?no=1360577 | 7층 정보통신과 | 673(채광원) | 스위치
140 | 볼트, 너트 | 25 | mm | 50 | 231 | 13860 | https://www.devicemart.co.kr/goods/view?no=23963 | 7층 정보통신과 | 673(채광원) | 너트
141 | 직각 브라켓 | 30 | mm | 30 | 540 | 19440 | https://www.devicemart.co.kr/goods/view?no=24012 | 7층 정보통신과 | 673(채광원) | 브라켓
142 | 농구 골대링, 망 | 45 | cm | 1 | 29900 | 35880 | http://item.gmarket.co.kr/Item?goodscode=271785344 | 7층 정보통신과 | 673(채광원) | 농구골대링/망
143 | 거리측정 센서(GP2Y0A21YK) | 37 | mm | 2 | 7150 | 17160 | https://www.devicemart.co.kr/goods/view?no=5264 | 7층 정보통신과 | 673(채광원) | 거리측정 센서
144 | 철망 | 양계망, 폭85cm X 9M | cm | 1 | 20000 | 24000 | http://item.gmarket.co.kr/Item?goodscode=852016925 | 7층 정보통신과 | 673(채광원) | 철말
145 | 아크릴판 | 900x50, 가로x세로 | mm | 2 | 3660 | 8784 | http://item.gmarket.co.kr/Item?goodsCode=1182354434 | 7층 정보통신과 | 673(채광원) | 아크릴판
146 | 아크릴판 | 596x50, 가로x세로 | mm | 2 | 2070 | 4968 | http://item.gmarket.co.kr/Item?goodsCode=1182354434 | 7층 정보통신과 | 673(채광원) | 아크릴판
147 | 흰색 포맥스 | 900x600, 가로x세로 | mm | 3 | 8040 | 28944 | http://item.gmarket.co.kr/Item?goodscode=1917811914 | 7층 정보통신과 | 673(채광원) | 포맥스
148 | 로드셀 무게센서 | 50x17x8, 가로x세로x높이 | mm | 10 | 14300 | 171600 | https://www.devicemart.co.kr/goods/view?no=1360976 | 7층 정보통신과 | 673(채광원) | 무게 센서
149 | HX711 (로드셀 AD컨버터) | 35x22, 가로x세로 | mm | 10 | 1870 | 22440 | https://www.devicemart.co.kr/goods/view?no=1327440 | 7층 정보통신과 | 673(채광원) | AD 컨버터
150 | RGB LED | 10 | 파이 | 11 | 1375 | 18150 | https://www.devicemart.co.kr/goods/view?no=12501933 | 7층 정보통신과 | 673(채광원) | LED
151 | 자동차 모형 | 13.5x7.5x4 가로x세로x높이 | cm | 10 | 5000 | 60000 | http://item.gmarket.co.kr/Item?goodscode=2742899223 | 7층 정보통신과 | 673(채광원) | 자동차모형
152 | 고리봉돌 무게추 50호 | 185 / 67x22 높이x지름 | g/mm | 25 | 1100 | 33000 | http://item.gmarket.co.kr/Item?goodscode=2428054918 | 7층 정보통신과 | 673(채광원) | 무게추
153 | 적외선 리시버 |  |  | 2 | 3000 | 7200 | https://vctec.co.kr/product/ir-%EC%A0%81%EC%99%B8%EC%84%A0-%EB%A6%AC%EC%8B%9C%EB%B2%84-tl1838-ir-infrared-receiver-tl1838/10423/ | 6층 명장양성부 | 664(최정우) | 적외선 리시버
154 | 포맥스 3T (검정) | 450x450 | mm | 3 | 5060 | 18216 | https://www.devicemart.co.kr/goods/view?no=10114 | 6층 명장양성부 | 664(최정우) | 모맥스
155 | 시스템 쿨러 | 120 | mm | 1 | 45100 | 54120 | https://www.devicemart.co.kr/goods/view?no=14556339 | 6층 명장양성부 | 664(최정우) | 쿨러
156 | 건전지 홀더 |  |  | 2 | 1100 | 2640 | https://www.devicemart.co.kr/goods/view?no=1278965 | 6층 명장양성부 | 664(최정우) | 배터리홀더
157 | 리튬 충전 배터리 |  |  | 4 | 7700 | 36960 | https://www.devicemart.co.kr/goods/view?no=1361229 | 6층 명장양성부 | 664(최정우) | 충전 배터리
158 | DIY용 스피커 유닛 |  |  | 2 | 5060 | 12144 | https://www.devicemart.co.kr/goods/view?no=12236769 | 6층 명장양성부 | 664(최정우) | 스피커
159 | 1인치 메탈 캐스터 |  |  | 2 | 880 | 2112 | https://www.devicemart.co.kr/goods/view?no=1327611 | 6층 명장양성부 | 664(최정우) | 메탈 캐스터
160 | 기어박스 장착모터 |  |  | 3 | 1980 | 7128 | https://www.devicemart.co.kr/goods/view?no=37853 | 6층 명장양성부 | 664(최정우) | 기어DC모터
161 | 바퀴 66파이 |  |  | 3 | 880 | 3168 | https://www.devicemart.co.kr/goods/view?no=37801 | 6층 명장양성부 | 664(최정우) | 바퀴
162 | 초음파 거리센서 모듈 |  |  | 5 | 3630 | 21780 | https://www.devicemart.co.kr/goods/view?no=10825459 | 6층 명장양성부 | 664(최정우) | 거리센서 모듈
163 | 미니 브레드 보드(투명) |  |  | 5 | 880 | 5280 | https://www.devicemart.co.kr/goods/view?no=1329504 | 6층 명장양성부 | 664(최정우) | 브레드보드
164 | 블루투스 모듈 |  |  | 2 | 6600 | 15840 | https://www.devicemart.co.kr/goods/view?no=1376882 | 6층 명장양성부 | 664(최정우) | 블루투스 모듈
165 | SMPS JK-LRS-35-12 |  |  | 1 | 11390 | 13668 | https://www.devicemart.co.kr/goods/view?no=12710322 | 6층 명장양성부 | 664(최정우)
166 | 모터 | 2450k 4pcs |  | 1 | 76000 | 91200 | https://ko.aliexpress.com/item/1005004698466078.html?curPageLogUid=yrHvPMo9m269 | 6층 명장양성부 | 664(최정우) | 모터
167 | 모터 | 2450k 2pcs |  | 1 | 40000 | 48000 | https://ko.aliexpress.com/item/1005004698466078.html?curPageLogUid=yrHvPMo9m269 | 6층 명장양성부 | 664(최정우) | 모터
168 | 프로펠러 | 블랙 5~6인치 4pcs |  | 2 | 3900 | 9360 | https://ko.aliexpress.com/item/1005002080378174.html?curPageLogUid=gnhte1Vhr3FI | 6층 명장양성부 | 664(최정우) | 프로펠러
169 | 프롭 아답터 | 내경 5 | mm | 1 | 12500 | 15000 | https://www.falconshop.co.kr/shop/goods/goods_view.php?goodsno=99986259 | 6층 명장양성부 | 664(최정우) | 아답터
170 | 적외선 근접센서 |  |  | 2 | 770 | 1848 | https://ko.aliexpress.com/item/1005004698466078.html?curPageLogUid=yrHvPMo9m269 | 6층 명장양성부 | 664(최정우) | 근접센서
171 | GPS 모듈 | Ublox NEO M8N GPS For APM and Pixhawk Flight Controller |  | 1 | 37000 | 44400 | http://hobbyzone.kr/product/ublox-neo-m8n-gps-for-apm-and-pixhawk-flight-controller-gps-%EB%AA%A8%EB%93%88/5535/ | 6층 명장양성부 | 664(최정우) | GPS 모듈
172 | 드른 속도조절기 | long with XT60 |  | 6 | 7000 | 50400 | https://ko.aliexpress.com/item/4000158662826.html?_t=pvid%3Aef2d6999-3d3e-427c-a23f-01db615b5754 | 6층 명장양성부 | 664(최정우) | ESC
173 | 드론 진동방지 댐퍼 | M3x7+4.5 |  | 1 | 6500 | 7800 | https://www.rcbank.co.kr/shop/goods/goods_view.php?&goodsno=15070 | 6층 명장양성부 | 664(최정우) | 댐퍼
174 | 드론 무선 통신 모듈 | MATEK PDB-XT60 BEC 5V & 12V |  | 1 | 85000 | 102000 | https://ko.aliexpress.com/item/1005003005063302.html | 6층 명장양성부 | 664(최정우) | 무선통신
175 | 드론 배전 보드 | MATEK PDB-XT60 BEC 5V & 12V 배전 보드 3-4S 30X30mm |  | 2 | 11500 | 27600 | https://ko.aliexpress.com/i/32879895039.html | 6층 명장양성부 | 664(최정우) | BEC
176 | 드론 배터리 | 피니티 3S 11.1V 1500mAh 45C Graphene LiPo 배터리 |  | 2 | 18500 | 44400 | https://ko.aliexpress.com/item/33002320717.html?gatewayAdapt=glo2kor | 6층 명장양성부 | 664(최정우) | 배터리
177 | STM32 보드 | 엠하이브 STM32 MH-FC V2.2 IMU기능내장 |  | 1 | 224000 | 268800 | https://smartstore.naver.com/mhivestore/products/4961922335 | 6층 명장양성부 | 664(최정우)
178 | Xbee 모듈 |  |  | 2 | 40000 | 96000 | https://www.navimro.com/g/429996/ | 6층 명장양성부 | 664(최정우) | Xbee 모듈
179 | 조이스틱 | 모드1 |  | 1 | 16516 | 19819.2 | https://ko.aliexpress.com/item/32558965306.html?scm_id=1007.40000.326746.0&scm-url=1007.40000.326746.0 | 6층 명장양성부 | 664(최정우) | 조이스틱
180 | 조이스틱 | 모드2 |  | 1 | 16516 | 19819.2 | https://ko.aliexpress.com/item/32558965306.html?scm_id=1007.40000.326746.0&scm-url=1007.40000.326746.0 | 6층 명장양성부 | 664(최정우) | 조이스틱
181 | USB Xbee Adapter | USB XBee Adapter |  | 1 | 45000 | 54000 | https://www.adafruit.com/?q=+XBee+Adapter&sort=BestMatch | 6층 명장양성부 | 664(최정우) | Xbee Adapter | 해외
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

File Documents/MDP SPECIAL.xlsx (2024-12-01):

제2차 MDP 실험실습 소모품 및 재료 구입 (기초금액산출내역서)
* 할인된 금액이 아닌 정가를 적어주세요. (쿠폰적용가X, 부가세포함한 금액으로 쓰기) * 알리익스프레스 등 해외배송/직구 등은 지체가 될 수 있습니다. 지양해주세요.(해외배송의 경우 디바이스마트, 엘레파츠, g마켓, 옥션 사이트 내에서 찾아주세요) * 배송비가 있는 경우 탭에 적어주세요.
순번 | 품명 | 규격 | 단위 | 수량 | 단가(원) | 추정금액(원) | 배송비 | 비고(사이트) | 납품장소 | 견적문의(신청자)
합 계 |  |  |  |  |  | 291420 | 8000 |  |  |  | 배송비
1 | 라즈베리파이 | Raspberry Pi 5 8GB RAM | 개 | 1 | 117700 | 141240 |  | https://www.icbanq.com/P015956550 | 6층 명장양성교육부
2 | 쿨링팬 | 에버쿨 쿨러 40MM (1B/2P/10T/5V) | 개 | 2 | 6050 | 14520 |  | https://www.icbanq.com/P004710081?gad_source=1 | 6층 명장양성교육부
3 | 5/10pcs USB 3.1 Type-c 커넥터 24 핀 암 플러그 소켓 | 10pcs | 세트 | 2 | 6909 | 16581.6 |  | https://www.temu.com/ul/kuiper/un9.html?subj=goods-un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 | 6층 명장양성교육부
4 | 사포 | 220방 5개 | 세트 | 2 | 3900 | 9360 | 0 | https://www.coupang.com/vp/products/15146788?itemId=62331079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 | 6층 명장양성교육부
5 |  |  |  |  |  | 0 |  |  | 6층 명장양성교육부
6 | 사포 | 600방 5개 | 세트 | 10 | 3900 | 46800 | 0 | https://www.coupang.com/vp/products/15146788?itemId=62331079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 | 6층 명장양성교육부
7 | 사포 | 1000방 5개 | 세트 | 1 | 3900 | 4680 | 0 | https://www.coupang.com/vp/products/15146788?itemId=62331079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 | 6층 명장양성교육부
8 | 웨더 스트리핑 씰 스트립 18피트 | 검은색 | 롤 | 1 | 5632 | 6758.4 |  | https://www.temu.com/kr/%EB%AC%B8-%EC%B0%BD%EB%AC%B8%EC%9A%A9-1%EB%A1%A4-%EC%9B%A8%EB%8D%94-%EC%8A%A4%ED%8A%B8%EB%A6%AC%ED%95%91-%EC%94%B0-%EC%8A%A4%ED%8A%B8%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 | 6층 명장양성교육부
9 | 플렉스 USB PD C타입 to C 60W 고속충전 케이블 30cm외 | C to C 60w black 플랙스 블랙 30cm | 개 | 4 | 3400 | 16320 | 2500 | https://www.coupang.com/vp/products/5542149861?itemId=8731904266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 | 6층 명장양성교육부
10 | 일신 락카 스프레이 페인트 도색 리폼 도장 기타 | 영일라카 무광백색 420ml 1개 | 통 | 3 | 2500 | 9000 | 3000 | https://www.coupang.com/vp/products/7837031178?itemId=20100769063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 | 6층 명장양성교육부
11 | 서멀구리스 | ARCTIC MX-6 서린 (4g) | 개 | 1 | 10100 | 12120 | 0 | https://www.coupang.com/vp/products/7830692293?itemId=21296611592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 | 6층 명장양성교육부
12 | 라즈베리파이 쿨러 | 라즈베리파이5 액티브 쿨러 | 개 | 1 | 7700 | 9240 |  | https://www.devicemart.co.kr/goods/view?no=15276241 | 6층 명장양성교육부
13 | dcdc컨버터 | 캠팜 LM2596 스텝다운 정전압 DC-DC 컨버터 (1.25~35V출력) | 개 | 2 | 2000 | 4800 | 2500 | https://www.coupang.com/vp/products/23556827?itemId=91607218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 | 6층 명장양성교육부
14 |  |  |  |  |  | 0 |  |  | 6층 명장양성교육부
15 |  |  |  |  |  | 0 |  |  | 6층 명장양성교육부
16 |  |  |  |  |  | 0 |  |  | 6층 명장양성교육부
17 |  |  |  |  |  | 0 |  |  | 6층 명장양성교육부
18 |  |  |  |  |  | 0 |  |  | 6층 명장양성교육부
19 |  |  |  |  |  | 0 |  |  | 6층 명장양성교육부
20 |  |  |  |  |  | 0 |  |  | 6층 명장양성교육부
21 |  |  |  |  |  | 0 |  |  | 6층 명장양성교육부
22 |  |  |  |  |  | 0 |  |  | 6층 명장양성교육부
23 |  |  |  |  |  | 0 |  |  | 6층 명장양성교육부
24 |  |  |  |  |  | 0 |  |  | 6층 명장양성교육부
25 |  |  |  |  |  | 0 |  |  | 6층 명장양성교육부
26 |  |  |  |  |  | 0 |  |  | 6층 명장양성교육부
27 |  |  |  |  |  | 0 |  |  | 6층 명장양성교육부
28 |  |  |  |  |  | 0 |  |  | 6층 명장양성교육부
29 |  |  |  |  |  | 0 |  |  | 6층 명장양성교육부
30 |  |  |  |  |  | 0 |  |  | 6층 명장양성교육부
31 |  |  |  |  |  | 0 |  |  | 6층 명장양성교육부
32 |  |  |  |  |  | 0 |  |  | 6층 명장양성교육부
33 |  |  |  |  |  | 0 |  |  | 6층 명장양성교육부
34 |  |  |  |  |  | 0 |  |  | 6층 명장양성교육부
35 |  |  |  |  |  | 0 |  |  | 6층 명장양성교육부
36 |  |  |  |  |  | 0 |  |  | 6층 명장양성교육부
37 |  |  |  |  |  | 0 |  |  | 6층 명장양성교육부
38 |  |  |  |  |  | 0 |  |  | 6층 명장양성교육부
39 |  |  |  |  |  | 0 |  |  | 6층 명장양성교육부
40 |  |  |  |  |  | 0 |  |  | 6층 명장양성교육부
41 |  |  |  |  |  | 0 |  |  | 6층 명장양성교육부
42 |  |  |  |  |  | 0 |  |  | 6층 명장양성교육부
43 |  |  |  |  |  | 0 |  |  | 6층 명장양성교육부
44 |  |  |  |  |  | 0 |  |  | 6층 명장양성교육부
45 |  |  |  |  |  | 0 |  |  | 6층 명장양성교육부
46 |  |  |  |  |  | 0 |  |  | 6층 명장양성교육부
47 |  |  |  |  |  | 0 |  |  | 6층 명장양성교육부
48 |  |  |  |  |  | 0 |  |  | 6층 명장양성교육부
49 |  |  |  |  |  | 0 |  |  | 6층 명장양성교육부
50 |  |  |  |  |  | 0 |  |  | 6층 명장양성교육부
51 |  |  |  |  |  | 0 |  |  | 6층 명장양성교육부
52 |  |  |  |  |  | 0 |  |  | 6층 명장양성교육부
53 |  |  |  |  |  | 0 |  |  | 6층 명장양성교육부
54 |  |  |  |  |  | 0 |  |  | 6층 명장양성교육부
55 |  |  |  |  |  | 0 |  |  | 6층 명장양성교육부
56 |  |  |  |  |  | 0 |  |  | 6층 명장양성교육부
57 |  |  |  |  |  | 0 |  |  | 6층 명장양성교육부
58 |  |  |  |  |  | 0 |  |  | 6층 명장양성교육부
59 |  |  |  |  |  | 0 |  |  | 6층 명장양성교육부
60 |  |  |  |  |  | 0 |  |  | 6층 명장양성교육부
61 |  |  |  |  |  | 0 |  |  | 6층 명장양성교육부
62 |  |  |  |  |  | 0 |  |  | 6층 명장양성교육부
63 |  |  |  |  |  | 0 |  |  | 6층 명장양성교육부
64 |  |  |  |  |  | 0 |  |  | 6층 명장양성교육부
65 |  |  |  |  |  | 0 |  |  | 6층 명장양성교육부
66 |  |  |  |  |  | 0 |  |  | 6층 명장양성교육부
67 |  |  |  |  |  | 0 |  |  | 6층 명장양성교육부
68 |  |  |  |  |  | 0 |  |  | 6층 명장양성교육부
69 |  |  |  |  |  | 0 |  |  | 6층 명장양성교육부
70 |  |  |  |  |  | 0 |  |  | 6층 명장양성교육부
71 |  |  |  |  |  | 0 |  |  | 6층 명장양성교육부
72 |  |  |  |  |  | 0 |  |  | 6층 명장양성교육부
73 |  |  |  |  |  | 0 |  |  | 6층 명장양성교육부
74 |  |  |  |  |  | 0 |  |  | 6층 명장양성교육부
75 |  |  |  |  |  | 0 |  |  | 6층 명장양성교육부
76 |  |  |  |  |  | 0 |  |  | 6층 명장양성교육부
77 |  |  |  |  |  | 0 |  |  | 6층 명장양성교육부
78 |  |  |  |  |  | 0 |  |  | 6층 명장양성교육부
79 |  |  |  |  |  | 0 |  |  | 6층 명장양성교육부
80 |  |  |  |  |  | 0 |  |  | 6층 명장양성교육부
81 |  |  |  |  |  | 0 |  |  | 6층 명장양성교육부
82 |  |  |  |  |  | 0 |  |  | 6층 명장양성교육부
83 |  |  |  |  |  | 0 |  |  | 6층 명장양성교육부
84 |  |  |  |  |  | 0 |  |  | 6층 명장양성교육부
85 |  |  |  |  |  | 0 |  |  | 6층 명장양성교육부
86 |  |  |  |  |  | 0 |  |  | 6층 명장양성교육부
87 |  |  |  |  |  | 0 |  |  | 6층 명장양성교육부
88 |  |  |  |  |  | 0 |  |  | 6층 명장양성교육부
89 |  |  |  |  |  | 0 |  |  | 6층 명장양성교육부
90 |  |  |  |  |  | 0 |  |  | 6층 명장양성교육부
91 |  |  |  |  |  | 0 |  |  | 6층 명장양성교육부
92 |  |  |  |  |  | 0 |  |  | 6층 명장양성교육부
93 |  |  |  |  |  | 0 |  |  | 6층 명장양성교육부
94 |  |  |  |  |  | 0 |  |  | 6층 명장양성교육부
95 |  |  |  |  |  | 0 |  |  | 6층 명장양성교육부
96 |  |  |  |  |  | 0 |  |  | 6층 명장양성교육부
97 |  |  |  |  |  | 0 |  |  | 6층 명장양성교육부
98 |  |  |  |  |  | 0 |  |  | 6층 명장양성교육부
99 |  |  |  |  |  | 0 |  |  | 6층 명장양성교육부
100 |  |  |  |  |  | 0 |  |  | 6층 명장양성교육부
101 |  |  |  |  |  | 0 |  |  | 6층 명장양성교육부
102 |  |  |  |  |  | 0 |  |  | 6층 명장양성교육부
103 |  |  |  |  |  | 0 |  |  | 6층 명장양성교육부
104 |  |  |  |  |  | 0 |  |  | 6층 명장양성교육부
105 |  |  |  |  |  | 0 |  |  | 6층 명장양성교육부
106 |  |  |  |  |  | 0 |  |  | 6층 명장양성교육부
107 |  |  |  |  |  | 0 |  |  | 6층 명장양성교육부
108 |  |  |  |  |  | 0 |  |  | 6층 명장양성교육부
109 |  |  |  |  |  | 0 |  |  | 6층 명장양성교육부
110 |  |  |  |  |  | 0 |  |  | 6층 명장양성교육부
111 |  |  |  |  |  | 0 |  |  | 6층 명장양성교육부
112 |  |  |  |  |  | 0 |  |  | 6층 명장양성교육부
113 |  |  |  |  |  | 0 |  |  | 6층 명장양성교육부
114 |  |  |  |  |  | 0 |  |  | 6층 명장양성교육부
115 |  |  |  |  |  | 0 |  |  | 6층 명장양성교육부
116 |  |  |  |  |  | 0 |  |  | 6층 명장양성교육부
117 |  |  |  |  |  | 0 |  |  | 6층 명장양성교육부
118 |  |  |  |  |  | 0 |  |  | 6층 명장양성교육부
119 |  |  |  |  |  | 0 |  |  | 6층 명장양성교육부
120 |  |  |  |  |  | 0 |  |  | 6층 명장양성교육부
121 |  |  |  |  |  | 0 |  |  | 6층 명장양성교육부
122 |  |  |  |  |  | 0 |  |  | 6층 명장양성교육부
123 |  |  |  |  |  | 0 |  |  | 6층 명장양성교육부
124 |  |  |  |  |  | 0 |  |  | 6층 명장양성교육부
125 |  |  |  |  |  | 0 |  |  | 6층 명장양성교육부
126 |  |  |  |  |  | 0 |  |  | 6층 명장양성교육부
127 |  |  |  |  |  | 0 |  |  | 6층 명장양성교육부
128 |  |  |  |  |  | 0 |  |  | 6층 명장양성교육부
129 |  |  |  |  |  | 0 |  |  | 6층 명장양성교육부
130 |  |  |  |  |  | 0 |  |  | 6층 명장양성교육부
131 |  |  |  |  |  | 0 |  |  | 6층 명장양성교육부
132 |  |  |  |  |  | 0 |  |  | 6층 명장양성교육부
133 |  |  |  |  |  | 0 |  |  | 6층 명장양성교육부
134 |  |  |  |  |  | 0 |  |  | 6층 명장양성교육부
135 |  |  |  |  |  | 0 |  |  | 6층 명장양성교육부
136 |  |  |  |  |  | 0 |  |  | 6층 명장양성교육부
137 |  |  |  |  |  | 0 |  |  | 6층 명장양성교육부
138 |  |  |  |  |  | 0 |  |  | 6층 명장양성교육부
139 |  |  |  |  |  | 0 |  |  | 6층 명장양성교육부
140 |  |  |  |  |  | 0 |  |  | 6층 명장양성교육부
141 |  |  |  |  |  | 0 |  |  | 6층 명장양성교육부
142 |  |  |  |  |  | 0 |  |  | 6층 명장양성교육부
143 |  |  |  |  |  | 0 |  |  | 6층 명장양성교육부
144 |  |  |  |  |  | 0 |  |  | 6층 명장양성교육부
145 |  |  |  |  |  | 0 |  |  | 6층 명장양성교육부
146 |  |  |  |  |  | 0 |  |  | 6층 명장양성교육부
147 |  |  |  |  |  | 0 |  |  | 6층 명장양성교육부
148 |  |  |  |  |  | 0 |  |  | 6층 명장양성교육부
149 |  |  |  |  |  | 0 |  |  | 6층 명장양성교육부
150 |  |  |  |  |  | 0 |  |  | 6층 명장양성교육부
151 |  |  |  |  |  | 0 |  |  | 6층 명장양성교육부
152 |  |  |  |  |  | 0 |  |  | 6층 명장양성교육부
153 |  |  |  |  |  | 0 |  |  | 6층 명장양성교육부
154 |  |  |  |  |  | 0 |  |  | 6층 명장양성교육부
155 |  |  |  |  |  | 0 |  |  | 6층 명장양성교육부
156 |  |  |  |  |  | 0 |  |  | 6층 명장양성교육부
157 |  |  |  |  |  | 0 |  |  | 6층 명장양성교육부
158 |  |  |  |  |  | 0 |  |  | 6층 명장양성교육부

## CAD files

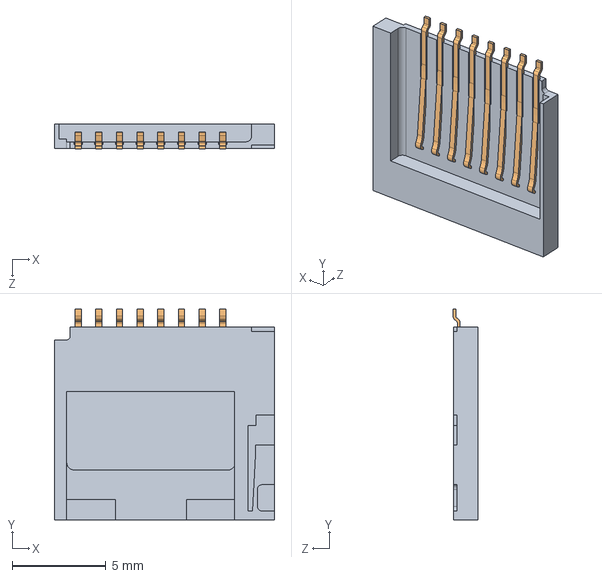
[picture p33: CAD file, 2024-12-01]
3DModel/raspberry-pi-5-2.snapshot.7/PARTS/SD CARD/SLOT_CARD_ASM.SLDASM
11.7 x 11.2 x 1.33 mm
CARD_SLOT_METAL_PIN
SD_CARD_V1

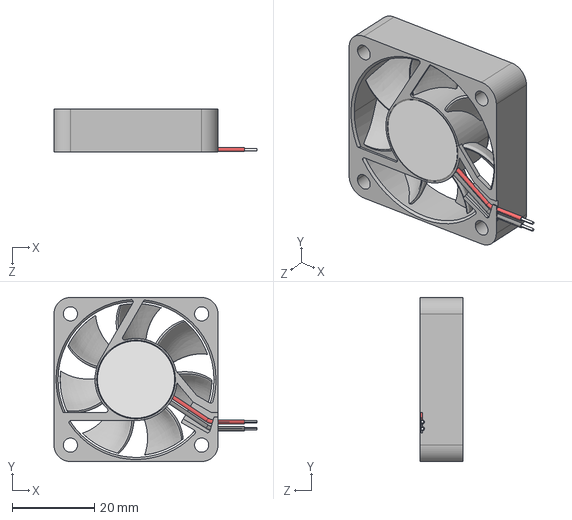
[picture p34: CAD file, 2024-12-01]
3DModel/CoolingModule/40mm-dc-fan-1.snapshot.7/40x40x10 DC Fan.STEP
49.5 x 40.0 x 10.5 mm

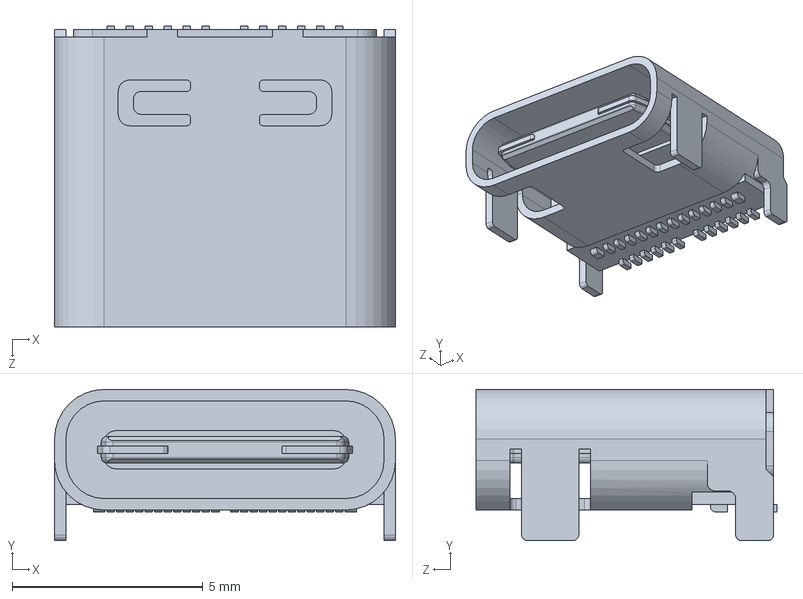
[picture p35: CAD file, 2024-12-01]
3DModel/raspberry-pi-5-2.snapshot.7/PARTS/FEMALE_USB_CONNECTOR.SLDPRT
8.94 x 3.96 x 7.90 mm

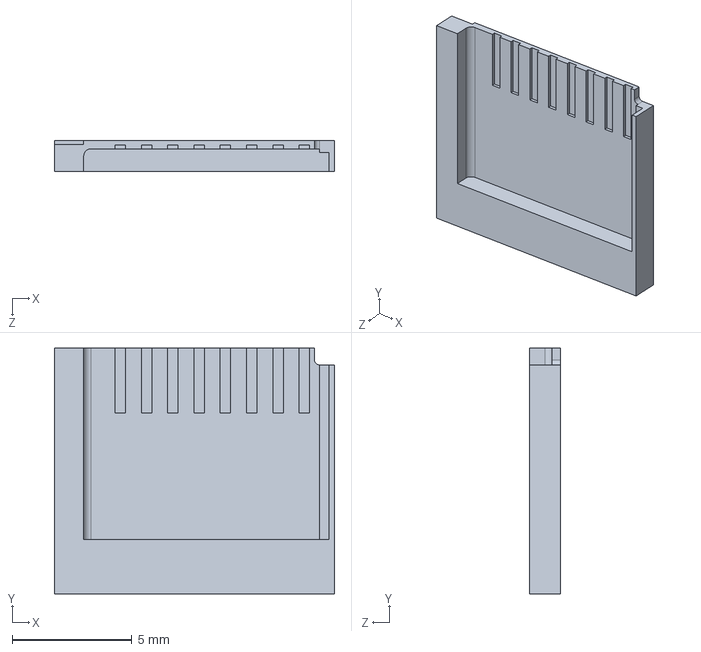
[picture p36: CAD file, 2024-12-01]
3DModel/raspberry-pi-5-2.snapshot.7/PARTS/SD CARD/SD_CARD_V1.SLDPRT
11.7 x 10.3 x 1.30 mm

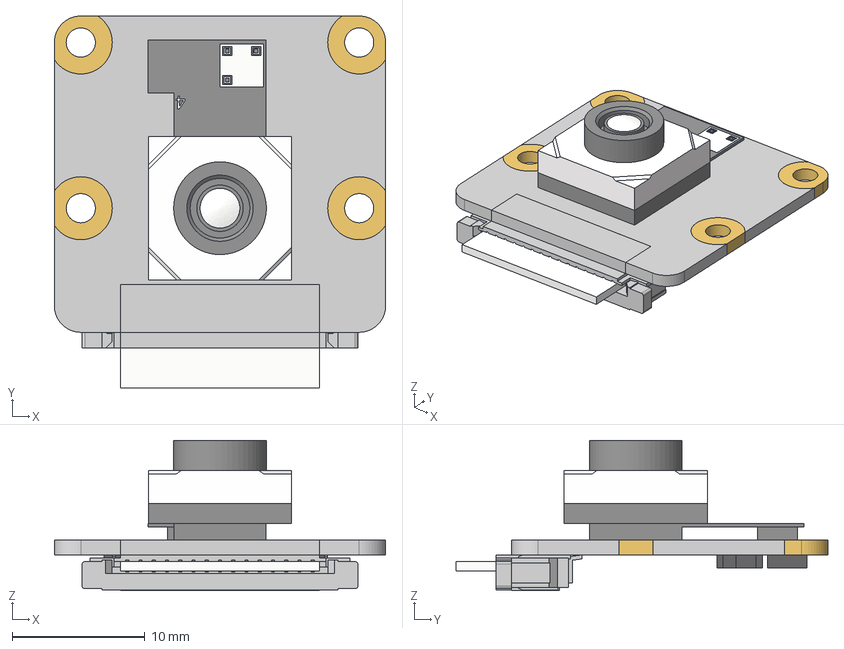
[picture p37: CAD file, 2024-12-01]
3DModel/raspberry-pi-camera-module-v3-2.snapshot.4/Camera Moudule 3 v8.step
25.0 x 28.1 x 11.3 mm
Board
sfw15r3ste1lf
Sensor
Lens
Ring
Mount
Housing

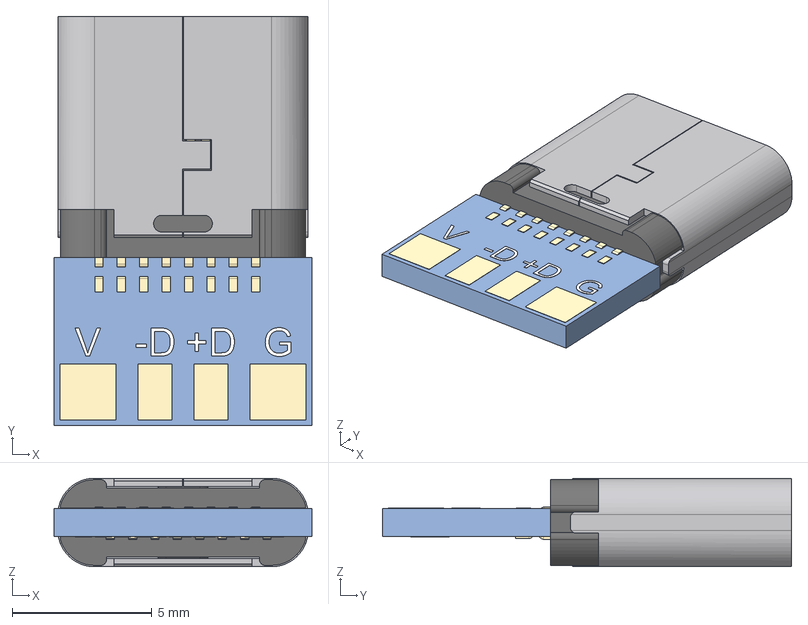
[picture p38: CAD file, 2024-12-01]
3DModel/usb-c-female-jrc-b008-1.snapshot.5/USB-C board JRC-B023.step
9.20 x 14.6 x 3.16 mm
USB_C_SHELL
USB_C_Body
USB_C_PIN x 16
PCB board
text
Contacts

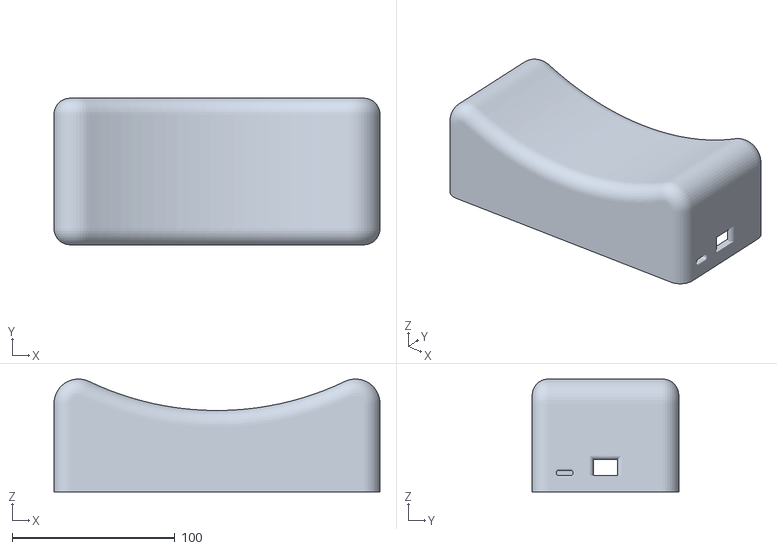
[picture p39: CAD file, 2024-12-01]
STL/2024_AUG_19 Order 2/BatPackCase.stl
200.0 x 90.0 x 69.3

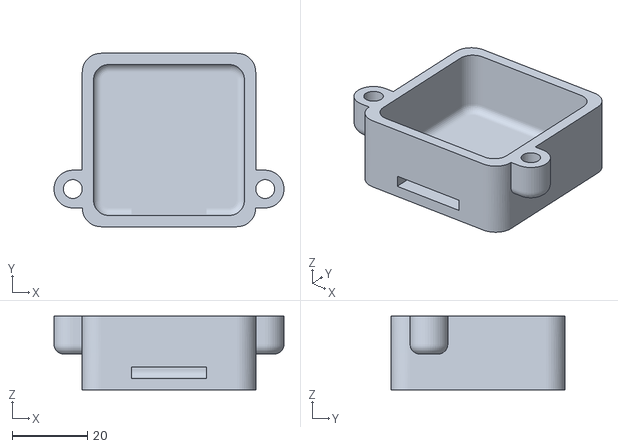
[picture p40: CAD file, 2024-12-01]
STL/2024_JUN_19 Order/FANHOLDER.stl
61.0 x 46.0 x 19.5

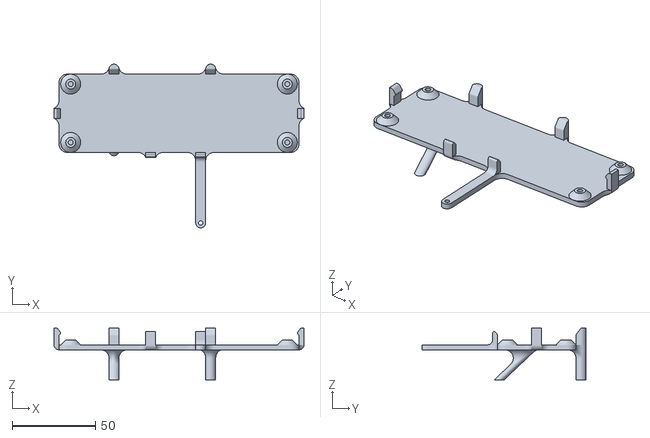
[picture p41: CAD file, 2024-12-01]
STL/2024_MAY_28 Order/PCB_Braket.stl
150.0 x 98.3 x 31.0

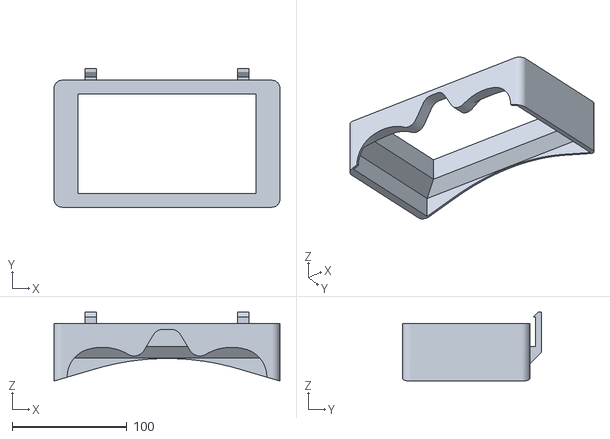
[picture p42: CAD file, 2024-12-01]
STL/lightseal.stl
197.0 x 120.8 x 60.0

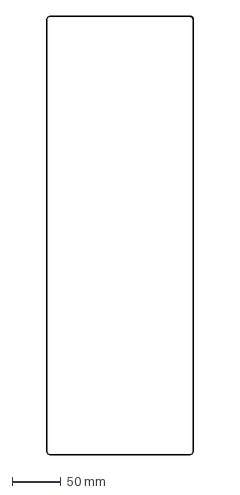
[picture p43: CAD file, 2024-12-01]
zpanel.dxf
150.0 x 450.0 mm

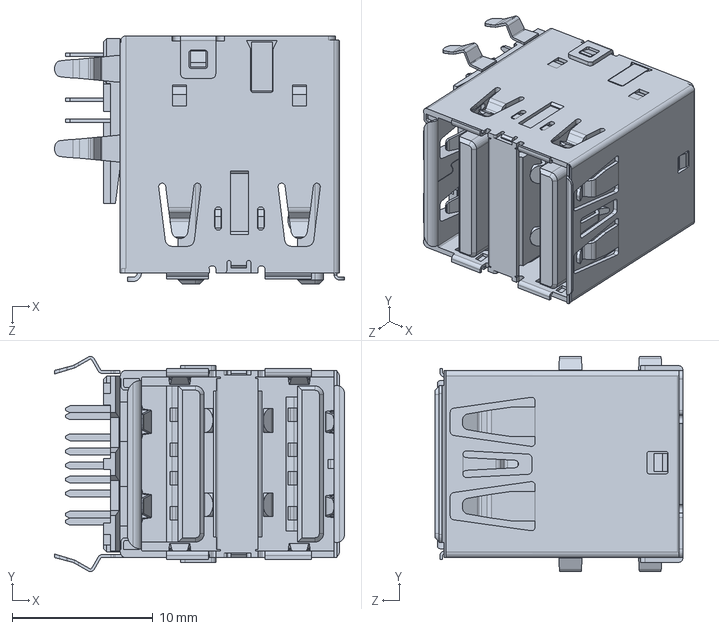
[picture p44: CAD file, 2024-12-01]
3DModel/raspberry-pi-5-2.snapshot.7/PARTS/2xUSB_3.0_PORT.SLDPRT
20.6 x 15.3 x 17.7 mm

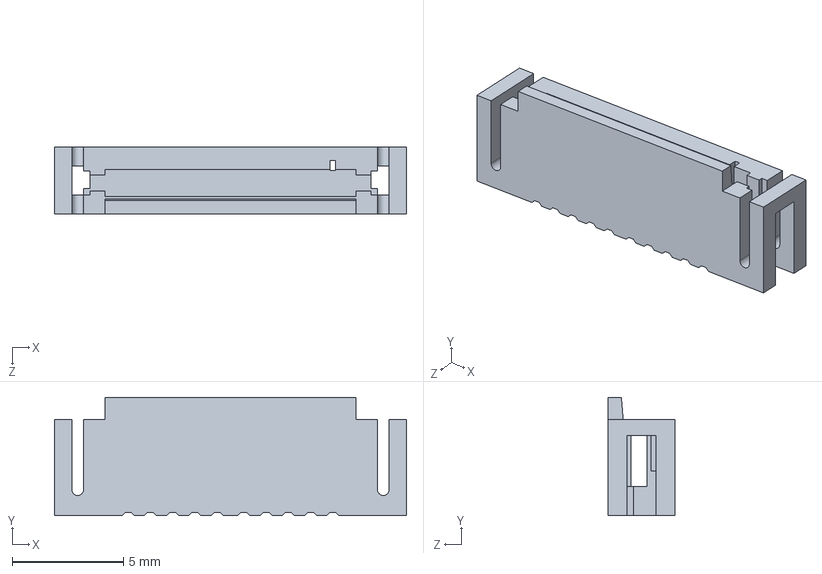
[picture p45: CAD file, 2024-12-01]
3DModel/raspberry-pi-5-2.snapshot.7/PARTS/DISPLAY_CONNECTOR/2.2 part 2 with combine.SLDPRT
15.8 x 5.30 x 3.00 mm

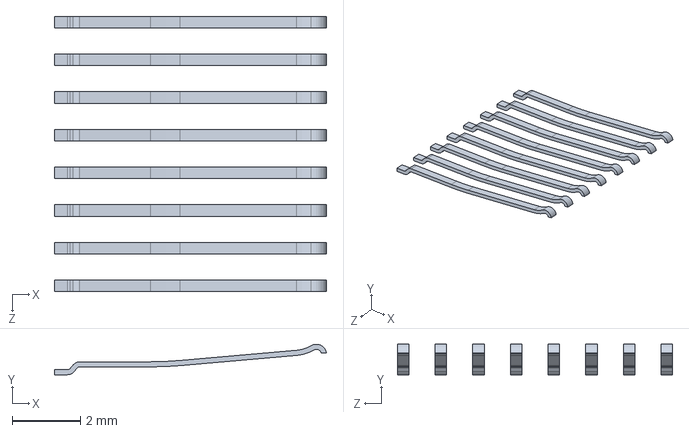
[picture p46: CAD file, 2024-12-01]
3DModel/raspberry-pi-5-2.snapshot.7/PARTS/SD CARD/CARD_SLOT_METAL_PIN.SLDPRT
7.95 x 0.892 x 8.04 mm

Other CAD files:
BlackBoard/mdp.dwg
BlackBoard/intec_name.dxf
3DModel/BatPack.iam
3DModel/BatPackCase.ipt
3DModel/BatPackCaseCover.ipt
3DModel/CoolingModule/40mm-dc-fan-1.snapshot.7/40x40x10 DC Fan.SLDPRT
3DModel/CoolingModule/40mm-dc-fan-1.snapshot.7/40x40x10 DC Fan/40x40x10 DC Fan.ipt
3DModel/CoolingModule/CoolingModule.iam
3DModel/CoolingModule/FANCATCHER.ipt
3DModel/CoolingModule/FANHOLDER.ipt
3DModel/CoolingModule/OldVersions/CoolingModule.0004.iam
3DModel/CoolingModule/OldVersions/FANCATCHER.0003.ipt
3DModel/CoolingModule/OldVersions/FANHOLDER.0003.ipt
3DModel/Hanabi.iam
3DModel/LightSealGioV1.ipt
3DModel/LightSealGioV2.ipt
3DModel/OldVersions/BatPack.0004.iam
3DModel/OldVersions/BatPackCase.0003.ipt
3DModel/OldVersions/BatPackCaseCover.0006.ipt
3DModel/OldVersions/Hanabi.0007.iam
3DModel/OldVersions/LightSealGioV2.0005.ipt
3DModel/OldVersions/PCB.0002.ipt
3DModel/OldVersions/PCB_Braket.0006.ipt
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

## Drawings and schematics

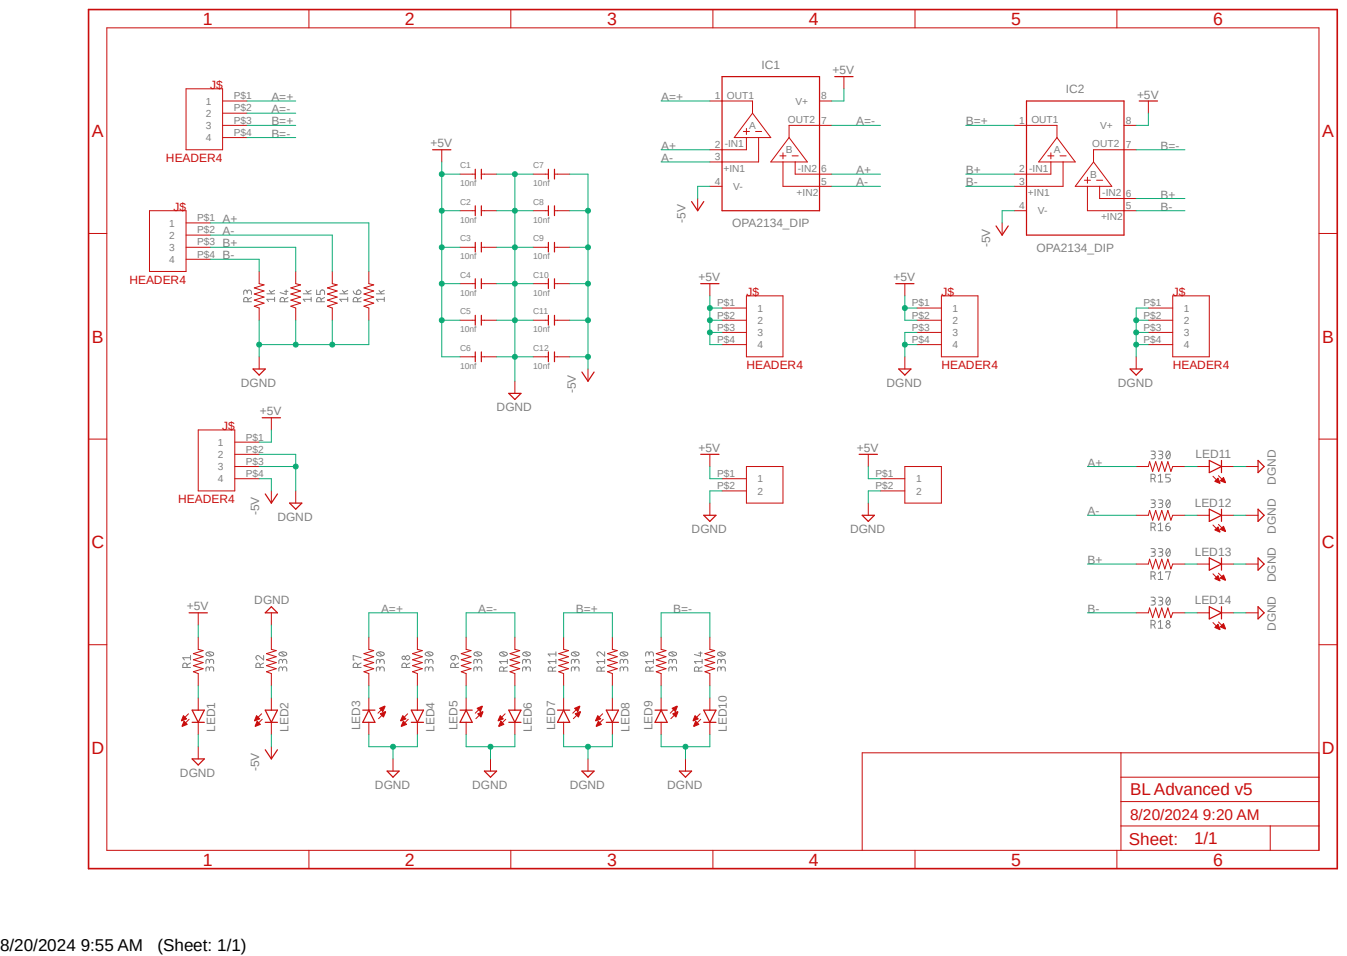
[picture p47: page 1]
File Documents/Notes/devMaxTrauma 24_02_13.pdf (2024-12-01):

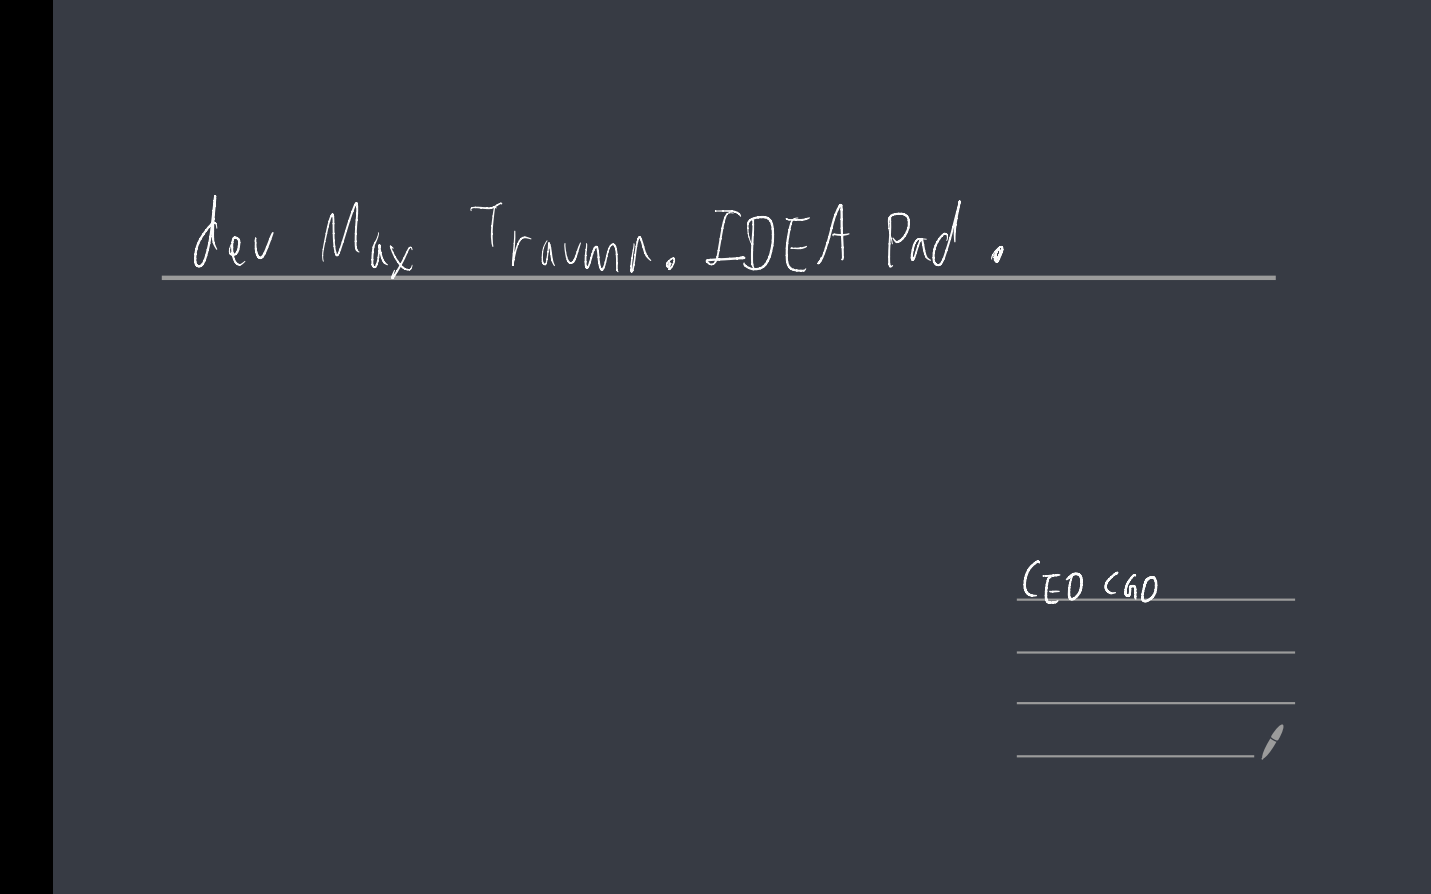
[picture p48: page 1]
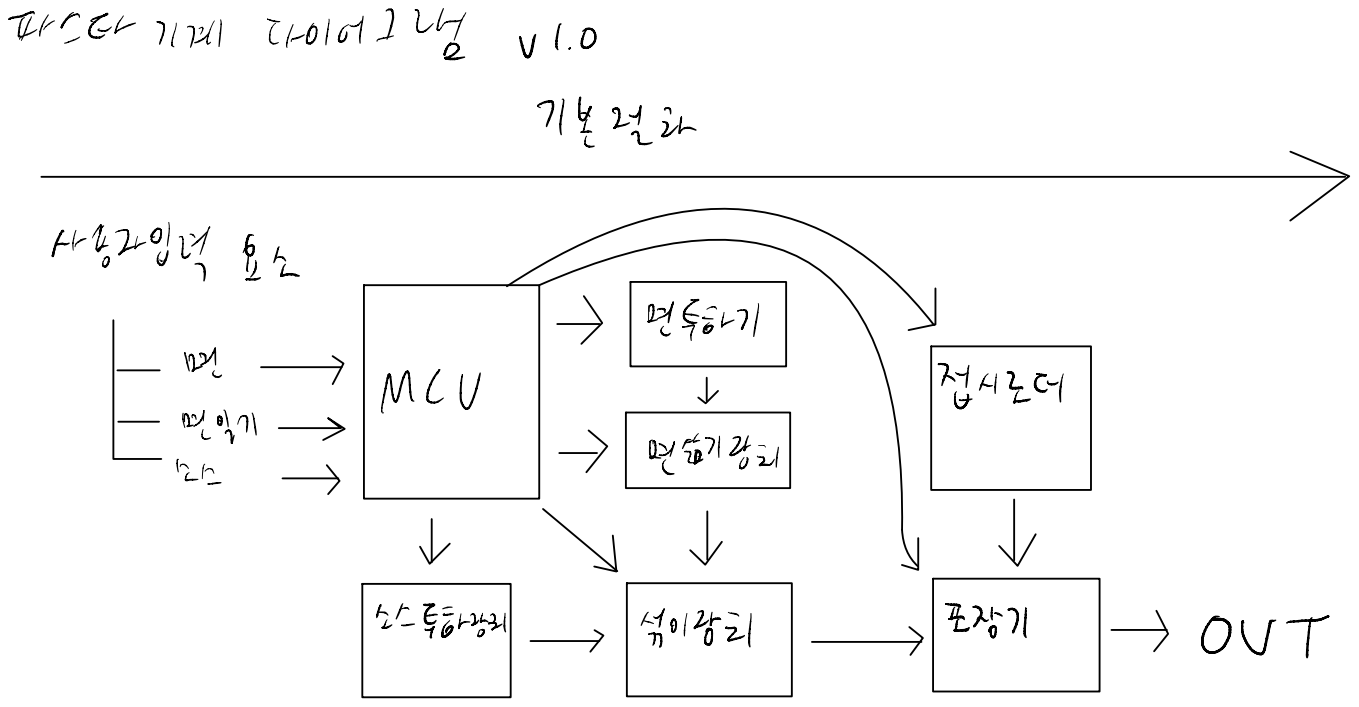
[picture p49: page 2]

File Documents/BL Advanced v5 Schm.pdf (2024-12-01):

# P$4 LED¹ LED²

A
